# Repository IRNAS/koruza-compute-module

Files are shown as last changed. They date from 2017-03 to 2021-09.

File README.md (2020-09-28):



# Koruza compute module

Main hardware board for the Koruza unit, based on the Raspberry Pi Compute Module.

Currently under development, for all information see the [schematic PDF file](https://github.com/IRNAS/koruza-compute-module/blob/board_0.2/koruza-compute-module-board/koruza-compute-module-board.pdf).Produced board versions can be found in the [release section](https://github.com/IRNAS/koruza-compute-module/releases) of the repository.

**Latest release: [v0.3.1](https://github.com/IRNAS/koruza-compute-module/releases/tag/v0.3.1)**

All comments and suggestions can be added to the [Issues](https://github.com/IRNAS/koruza-compute-module/issues) section of the repo. For additional details see the [Issue](https://github.com/IRNAS/koruza-compute-module/issues) section or contact me at vojislav@irnas.eu

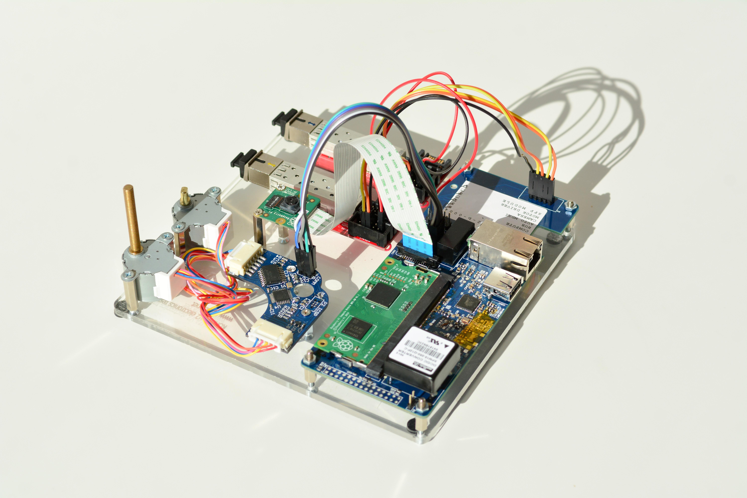
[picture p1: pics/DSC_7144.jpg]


---
## Uploding firmware

Connect board via USB and provide power via POE. Run RPiboot and wait for replay. Flash firmware image via Win32. 

## Licensing

KORUZA Pro Hardware with documentation, including Koruza compute module, is licensed under [CERN OHL v.1.2. license](https://www.ohwr.org/licenses/cern-ohl/license_versions/v1.2).

What this means is that you can use this hardware and documentation without paying a royalty and knowing that you'll be able to use your version forever. You are also free to make changes but if you share these changes then you have to do so on the same conditions that you enjoy.

KORUZA, KORUZA Pro and IRNAS are all names and marks of Institute IRNAS Rače. You may use these names and terms only to attribute the appropriate entity as required by the Open Licence referred to above. You may not use them in any other way and in particular you may not use them to imply endorsement or authorization of any hardware that you design, make or sell.

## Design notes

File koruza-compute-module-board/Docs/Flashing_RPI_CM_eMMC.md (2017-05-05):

# RPI CM Flash manual
The Compute Module has an on-board eMMC device connected to the primary SD card interface. This guide explains how to write data to the eMMC storage using a Compute Module IO board and Raspberry Pi 2B or 3B board.

1. Put the RPI CM in the RPI CM IO board socket. 
2. Set the J4 jumper (USB SLAVE BOOT ENABLE) on the RPI CM IO board to the EN.
3. Plug the micro USB power into the RPI 2B/3B. 
4. SSH to the RPI 2B/3B

*****
If the RPI 2B/3B is configured:

5. On RPI 2B/3B: `cd usbboot`
6. On RPI 2B/3B: `sudo ./rpiboot`
7. Now plug the host machine into the Compute Module IO board USB slave port (J15) and power the CMIO board on. The rpiboot tool will discover the Compute Module and send boot code to allow access to the eMMC. 
8. On RPI 2B/3B: `cd ..`
9. On RPI 2B/3B: `cd image`
10. On RPI 2B/3B: `sudo dd if=image_name.img of=/dev/sda bs=4MiB` Note the following command may take some time to complete, depending on the size of the image. verbose command option: `sudo dd if=image_name.img | pv -s 4G | sudo dd of=/dev/sda bs=4MiB`
11. Make sure J4 (USB SLAVE BOOT ENABLE) is set to the disabled position and/or nothing is plugged into the USB slave port. Power cycling the IO board should now result in the Compute Module booting from eMMC.

*****
If the RPI 2B/3B is NOT configured:

5. On RPI 2B/3B: `sudo apt-get update`
6. On RPI 2B/3B: `sudo apt-get install git pv`
7. Git may produce an error if the date is not set correctly. On a Raspberry Pi, enter the following to correct this: `sudo date MMDDhhmm` where MM is the month, DD is the date, and hh and mm are hours and minutes respectively.
8. On RPI 2B/3B: `git clone --depth=1 https://github.com/raspberrypi/usbboot`
9. On RPI 2B/3B: `cd usbboot`
10. On RPI 2B/3B: `sudo apt-get install libusb-1.0-0-dev`
11. On RPI 2B/3B now build and install the usbboot tool: `make`
12. NOW CONTNOUE FROM THE **If the RPI 2B/3B is configured: number 6.** 

If you have problems configuring the RPI CM please check the [link][link1].

[link1]: https://www.raspberrypi.org/documentation/hardware/computemodule/cm-emmc-flashing.md

# RPI CM installation post flash
1. Run `sudo raspi-config` and expand the filesystem
2. Run `sudo apt-ger update`
3. Run `sudo apt-get upgrade`
4. Copy koruza package on the unit
4. Run `sudo dpkg -i <koruza package>`
4. Run `sudo apt-get -f install`
4. Run `sudo dpkg -i <koruza package>`
4. Upgrade mcu firmware `sudo mcu-upgrade-firmware master`

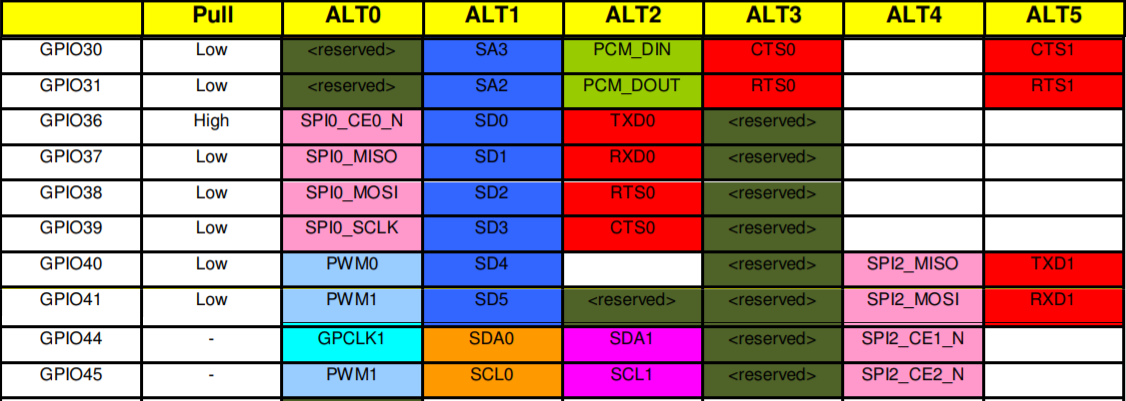
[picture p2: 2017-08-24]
pics/GPIO_ALT.png

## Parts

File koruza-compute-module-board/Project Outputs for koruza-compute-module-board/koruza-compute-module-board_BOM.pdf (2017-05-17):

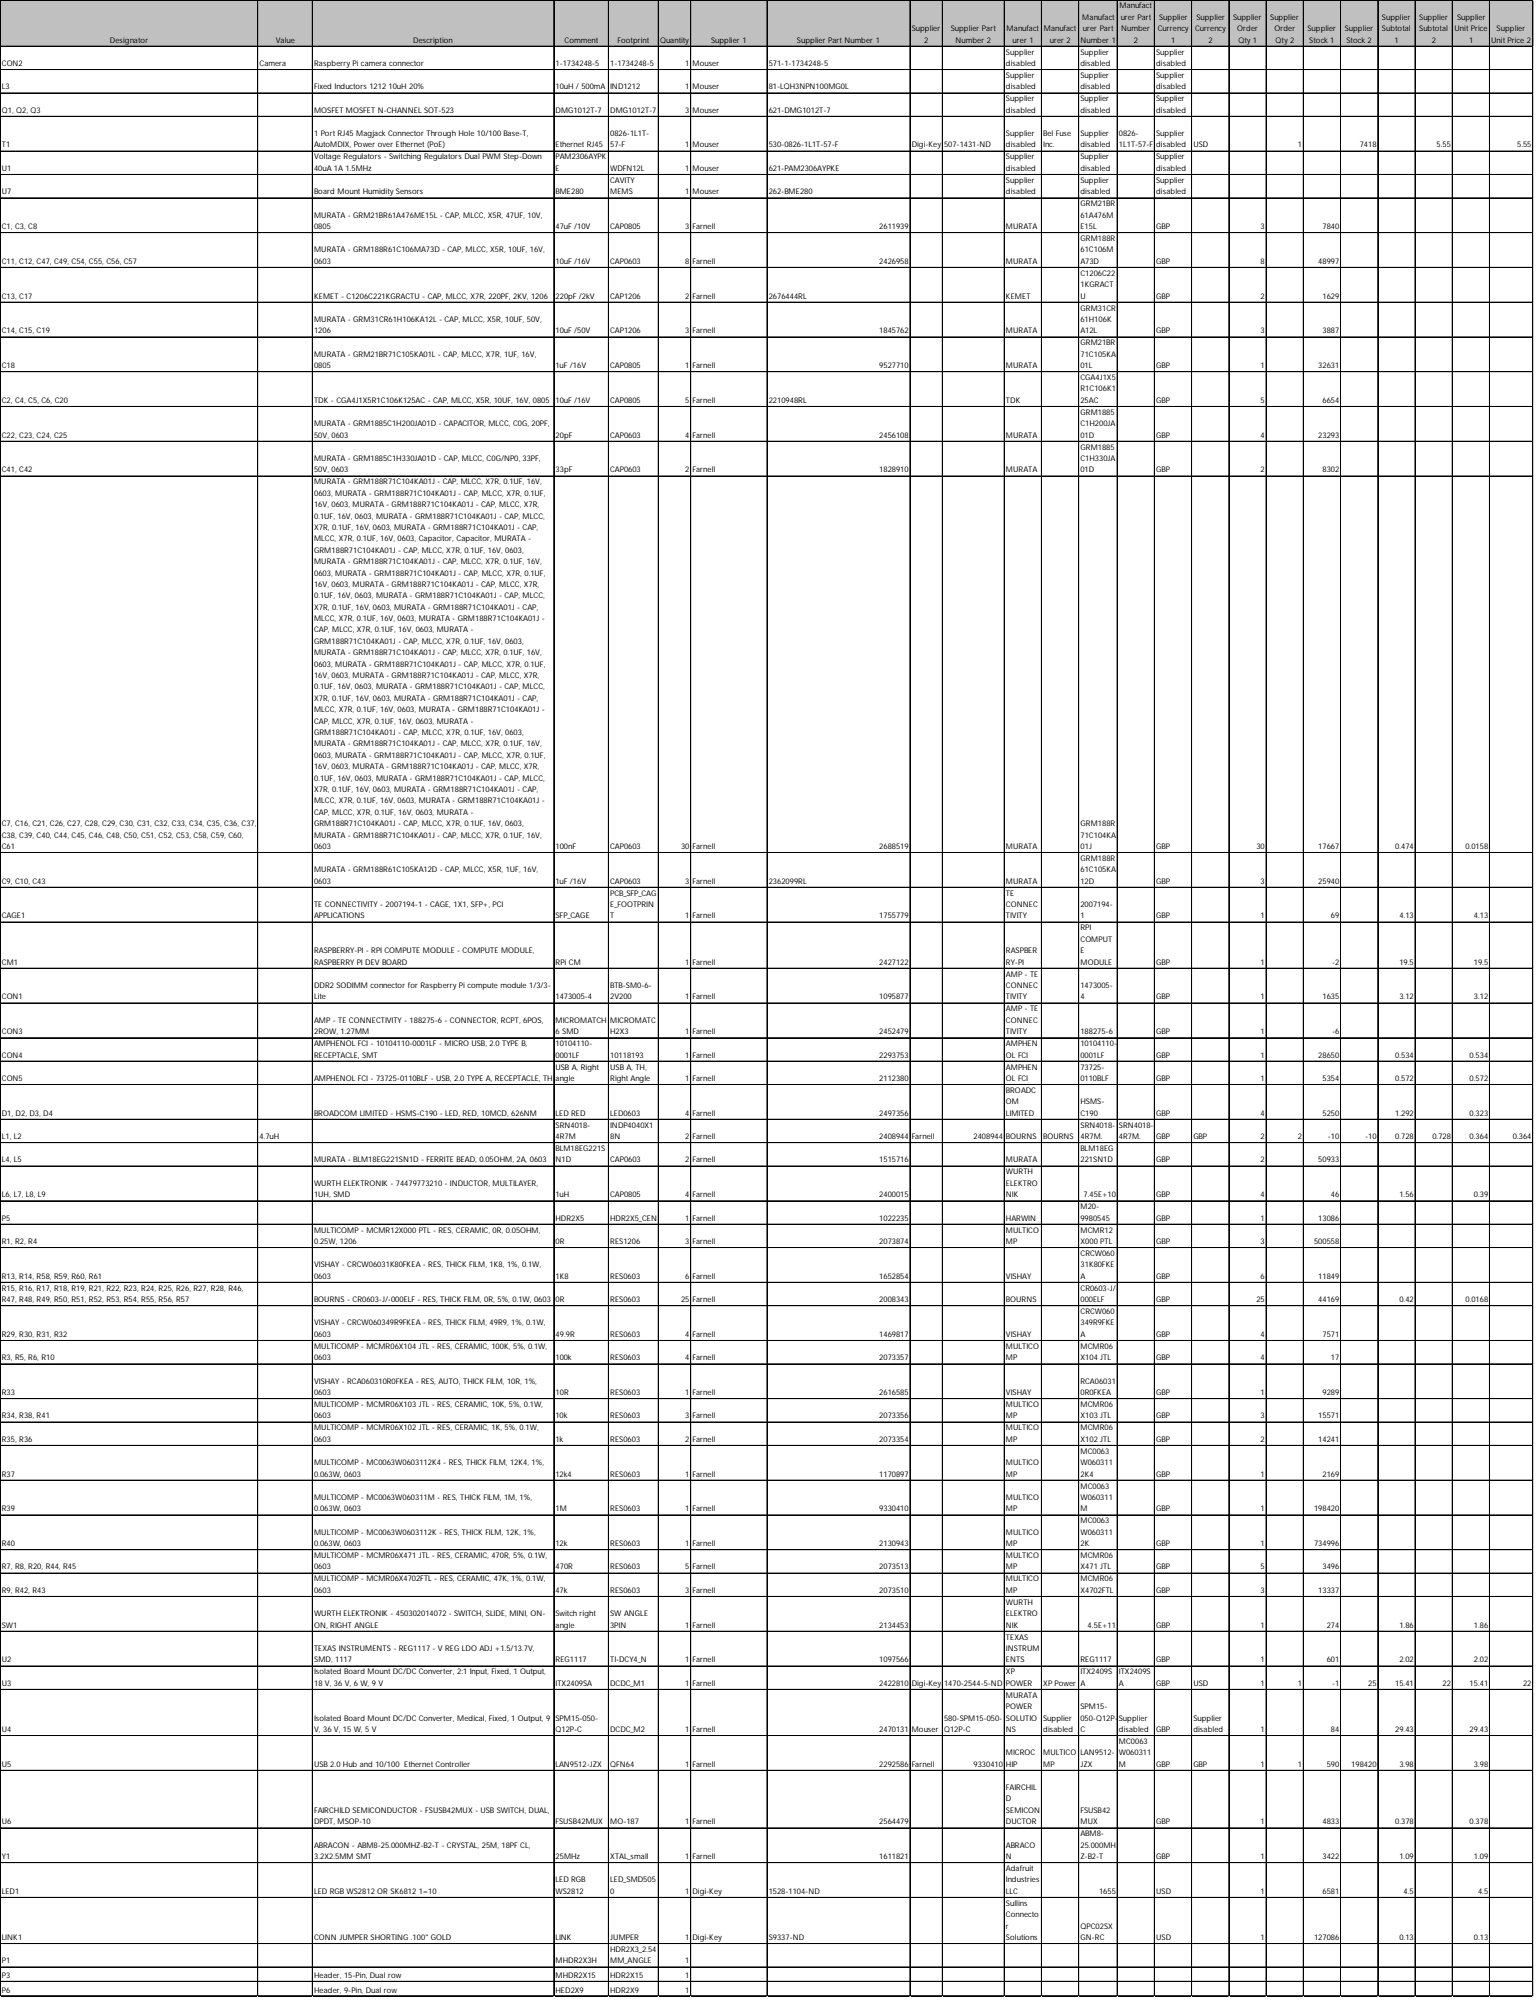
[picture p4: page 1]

Designator | Value | Description | Comment | Footprint | Quantity | Supplier 1 | Supplier Part Number 1 | Supplier 2 | Supplier Part Number 2 | Manufact urer 1 | Manufact urer 2 | Manufact urer Part Number 1 | Manufact urer Part Number 2 | Supplier Currency 1 | Supplier Currency 2 | Supplier Order Qty 1 | Supplier Order Qty 2 | Supplier Stock 1 | Supplier Stock 2 | Supplier Subtotal 1 | Supplier Subtotal 2 | Supplier Unit Price 1 | Supplier Unit Price 2

CON2 | Camera | Raspberry Pi camera connector | 1-1734248-5 | 1-1734248-5 | 1 | Mouser | 571-1-1734248-5 | | | Supplier disabled | | Supplier disabled | | Supplier disabled

L3 | | Fixed Inductors 1212 10uH 20% | 10uH / 500mA | IND1212 | 1 | Mouser | 81-LQH3NPN100MG0L | | | Supplier disabled | | Supplier disabled | | Supplier disabled

Q1, Q2, Q3 | | MOSFET MOSFET N-CHANNEL SOT-523 | DMG1012T-7 | DMG1012T-7 | 3 | Mouser | 621-DMG1012T-7 | | | Supplier disabled | | Supplier disabled | | Supplier disabled

T1 | | 1 Port RJ45 Magjack Connector Through Hole 10/100 Base-T, AutoMDIX, Power over Ethernet (PoE) | Ethernet RJ45 | 0826-1L1T-57-F | 1 | Mouser | 530-0826-1L1T-57-F | Digi-Key | 507-1431-ND | Supplier disabled | Bel Fuse Inc. | Supplier disabled | 0826-1L1T-57-F | Supplier disabled | USD | | 1 | | 7418 | | 5.55 | | 5.55

U1 | | Voltage Regulators - Switching Regulators Dual PWM Step-Down 40uA 1A 1.5MHz | PAM2306AYPK E | WDFN12L | 1 | Mouser | 621-PAM2306AYPKE | | | Supplier disabled | | Supplier disabled | | Supplier disabled

U7 | | Board Mount Humidity Sensors | BME280 | CAVITY MEMS | 1 | Mouser | 262-BME280 | | | Supplier disabled | | Supplier disabled | | Supplier disabled

C1, C3, C8 | | MURATA - GRM21BR61A476ME15L - CAP, MLCC, X5R, 47UF, 10V, 0805 | 47uF /10V | CAP0805 | 3 | Farnell | 2611939 | | | MURATA | | GRM21BR 61A476M E15L | | GBP | | 3 | | 7840

C11, C12, C47, C49, C54, C55, C56, C57 | | MURATA - GRM188R61C106MA73D - CAP, MLCC, X5R, 10UF, 16V, 0603 | 10uF /16V | CAP0603 | 8 | Farnell | 2426958 | | | MURATA | | GRM188R 61C106M A73D | | GBP | | 8 | | 48997

C13, C17 | | KEMET - C1206C221KGRACTU - CAP, MLCC, X7R, 220PF, 2KV, 1206 | 220pF /2kV | CAP1206 | 2 | Farnell | 2676444RL | | | KEMET | | C1206C22 1KGRACT U | | GBP | | 2 | | 1629

C14, C15, C19 | | MURATA - GRM31CR61H106KA12L - CAP, MLCC, X5R, 10UF, 50V, 1206 | 10uF /50V | CAP1206 | 3 | Farnell | 1845762 | | | MURATA | | GRM31CR 61H106K A12L | | GBP | | 3 | | 3887

C18 | | MURATA - GRM21BR71C105KA01L - CAP, MLCC, X7R, 1UF, 16V, 0805 | 1uF /16V | CAP0805 | 1 | Farnell | 9527710 | | | MURATA | | GRM21BR 71C105KA 01L | | GBP | | 1 | | 32631

C2, C4, C5, C6, C20 | | TDK - CGA4J1X5R1C106K125AC - CAP, MLCC, X5R, 10UF, 16V, 0805 | 10uF /16V | CAP0805 | 5 | Farnell | 2210948RL | | | TDK | | CGA4J1X5 R1C106K1 25AC | | GBP | | 5 | | 6654

C22, C23, C24, C25 | | MURATA - GRM1885C1H200JA01D - CAPACITOR, MLCC, C0G, 20PF, 50V, 0603 | 20pF | CAP0603 | 4 | Farnell | 2456108 | | | MURATA | | GRM1885 C1H200JA 01D | | GBP | | 4 | | 23293

C41, C42 | | MURATA - GRM1885C1H330JA01D - CAP, MLCC, C0G/NP0, 33PF, 50V, 0603 | 33pF | CAP0603 | 2 | Farnell | 1828910 | | | MURATA | | GRM1885 C1H330JA 01D | | GBP | | 2 | | 8302

MURATA - GRM188R71C104KA01J - CAP, MLCC, X7R, 0.1UF, 16V,
0603, MURATA - GRM188R71C104KA01J - CAP, MLCC, X7R, 0.1UF,
16V, 0603, MURATA - GRM188R71C104KA01J - CAP, MLCC, X7R,
0.1UF, 16V, 0603, MURATA - GRM188R71C104KA01J - CAP, MLCC,
X7R, 0.1UF, 16V, 0603, MURATA - GRM188R71C104KA01J - CAP,
MLCC, X7R, 0.1UF, 16V, 0603, Capacitor, Capacitor, MURATA -
GRM188R71C104KA01J - CAP, MLCC, X7R, 0.1UF, 16V, 0603,
MLCC, X7R, 0.1UF, 16V, 0603, MURATA - GRM188R71C104KA01J -
CAP, MLCC, X7R, 0.1UF, 16V, 0603, MURATA -

C9, C10, C43 | | MURATA - GRM188R61C105KA12D - CAP, MLCC, X5R, 1UF, 16V, 0603 | 1uF /16V | CAP0603 | 3 | Farnell | 2362099RL | | | MURATA | | GRM188R 61C105KA 12D | | GBP | | 3 | | 25940

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

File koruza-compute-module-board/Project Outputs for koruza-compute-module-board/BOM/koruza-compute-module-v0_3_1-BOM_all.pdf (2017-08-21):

Created by FEDEVEL | Motherboard, Processor and Microcontroller Board Design | http://www.fedevel.com
Component list | <Parameter ProjectTitle not found>
Source Data From: | koruza-compute-module-board.PrjPcb | Contact:
Project: | koruza-compute-module-board.PrjPcb
Variant: | None | Koruza
Report Date: | 05/13/2017 | 10:14:47 AM | www.koruza.net
Print Date: | 27-Jul-17 | 9:42:24 AM
# | Manufacturer Part Number 1 | Manufacturer 1 | Description | Footprint | Category | Quantity | Supplier 1 | Supplier Part Number 1

Supplier
Order Qty
1

Supplier
Stock 1

Supplier
Unit Price
1

Supplier
Subtotal 1

Supplier
Currency 1
1 | ITX2409SA | XP POWER | Isolated Board Mount DC/DC
2 3 | 450302014072 | WURTH ELEKTRONIK | WURTH ELEKTRONIK - | SW ANGLE 3PIN | | 1 | Farnell | 2134453 | 25 | 262 | 1.66 | 41.50 | GBP
| 74479773210 | WURTH ELEKTRONIK | WURTH ELEKTRONIK - | CAP0805 | | 4 | Farnell | 1869749 | 100 | 2187 | 0.29 | 29.00 | GBP
4 5 | CRCW06031K80FKEA | VISHAY | VISHAY - | RES0603 | | 6 | Farnell | 1652854 | 150 | 11759 | 0.01 | 1.44 | GBP
| CRCW060349R9FKEA | VISHAY | VISHAY - | RES0603 | | 4 | Farnell | 1469817 | 100 | 4204 | 0.01 | 0.94 | GBP
6 7 | RCA060310R0FKEA | VISHAY | VISHAY - RCA060310R0FKEA | RES0603 | | 1 | Farnell | 2616585 | 25 | 9289 | 0.08 | 2.01 | GBP
| REG1117 | TEXAS INSTRUMENTS | TEXAS INSTRUMENTS - | TI-DCY4_N | | 1 | Farnell | 1097566 | 25 | 550 | 1.53 | 38.25 | GBP
8 9 | 1-1734248-5 | TE Connectivity / AMP | Raspberry Pi camera connector | 1-1734248-5 | FFC & FPC Connectors | 1 | Mouser | 571-1-1734248-5 | 25 | 1375 | 1.29 | 32.25 | GBP
| 2007194-1 | TE CONNECTIVITY | TE CONNECTIVITY - 2007194- | PCB_SFP_CAGE_FOOTPRI | | 1 | Farnell | 1755779 | 25 | 68 | 3.68 | 92.00 | GBP
10 11 | CGA4J1X5R1C106K125AC | TDK | TDK - | CAP0805 | | 5 | Farnell | 2210948 | 125 | 6414 | 0.16 | 20.00 | GBP
| QPC02SXGN-RC | Sullins Connector Solutions | CONN JUMPER SHORTING | JUMPER | Connectors, Interconnects | 1 | Digi-Key | S9337-ND | 25 | 125440 | 0.05 | 1.25 | GBP
12 13 | RPI COMPUTE MODULE | RASPBERRY-PI | RASPBERRY-PI - RPI | | | 1 | Farnell | 2427122 | 25 | 25 | 19.50 | 487.50 | GBP
| SPM15-050-Q12P-C | MURATA POWER SOLUTIONS | Isolated Board Mount DC/DC | DCDC_M2 | | 1 | Farnell | 2470131 | 25 | 76 | 28.95 | 723.75 | GBP
14 15 | LQH3NPN100MG0L | Murata Electronics | Fixed Inductors 1212 10uH | IND1212 | Fixed Inductors | 1 | Mouser | 81-LQH3NPN100MG0L | 25 | 25 | 0.30 | 7.50 | GPB
| BLM18EG221SN1D | MURATA | MURATA - | CAP0603 | | 2 | Farnell | 1515716 | 50 | 50563 | 0.10 | 4.83 | GBP
16 17 | GRM1885C1H200JA01D | MURATA | MURATA - | CAP0603 | | 4 | Farnell | 2456108 | 100 | 23083 | 0.02 | 1.59 | GBP
| GRM1885C1H330JA01D | MURATA | MURATA - | CAP0603 | | 2 | Farnell | 1828910 | 50 | 8002 | 0.02 | 0.78 | GBP
18 19 | GRM188R61C105KA12D | MURATA | MURATA - | CAP0603 | | 3 | Farnell | 2362099 | 75 | 25820 | 0.01 | 0.95 | GBP
| GRM188R61C106MA73D | MURATA | MURATA - | CAP0603 | | 8 | Farnell | 2426958 | 200 | 37407 | 0.10 | 20.60 | GBP
20 21 | GRM188R71C104KA01J | MURATA | MURATA - | CAP0603 | | 30 | Farnell | 2688519 | 750 | 17667 | 0.01 | 5.85 | GBP
| GRM21BR61A476ME15L | MURATA | MURATA - | CAP0805 | | 3 | Farnell | 2611939 | 75 | 2584 | 0.30 | 22.28 | GBP
22 23 | GRM21BR71C105KA01L | MURATA | MURATA - | CAP0805 | | 1 | Farnell | 9527710 | 25 | 30805 | 0.04 | 1.01 | GBP
| GRM31CR61H106KA12L | MURATA | MURATA - | CAP1206 | | 3 | Farnell | 1845762 | 75 | 711 | 0.22 | 16.20 | GBP
24 25 | MC0063W0603112K | MULTICOMP | MULTICOMP - | RES0603 | | 1 | Farnell | 9330518 | 25 | 724996 | 0.00 | 0.02 | GBP
| MC0063W0603112K4 | MULTICOMP | MULTICOMP - | RES0603 | | 1 | Farnell | 1170897 | 25 | 1859 | 0.01 | 0.28 | GBP
26 27 | MC0063W060311M | MULTICOMP | MULTICOMP - | RES0603 | | 1 | Farnell | 9330410 | 25 | 176136 | 0.00 | 0.03 | GBP
| MCMR06X102 JTL | MULTICOMP | MULTICOMP - MCMR06X102 | RES0603 | | 2 | Farnell | 2073354 | 50 | 10741 | 0.01 | 0.32 | GBP
28 29 | MCMR06X103 JTL | MULTICOMP | MULTICOMP - MCMR06X103 | RES0603 | | 3 | Farnell | 2073356 | 75 | 15351 | 0.01 | 0.47 | GBP
| MCMR06X104 JTL | MULTICOMP | MULTICOMP - MCMR06X104 | RES0603 | | 4 | Farnell | 9233628 | 100 | 25843 | 0.00 | 0.45 | GBP
30 31 | MCMR06X4702FTL | MULTICOMP | MULTICOMP - | RES0603 | | 3 | Farnell | 2073510 | 75 | 13267 | 0.01 | 0.64 | GBP
| MCMR06X471 JTL | MULTICOMP | MULTICOMP - MCMR06X471 | RES0603 | | 5 | Farnell | 2073513 | 125 | 3496 | 0.01 | 0.95 | GBP
32 33 | MCMR12X000 PTL | MULTICOMP | MULTICOMP - MCMR12X000 | RES1206 | | 3 | Farnell | 2073874 | 75 | 497468 | 0.02 | 1.44 | GBP
| LAN9512-JZX | MICROCHIP | USB 2.0 Hub and 10/100 | QFN64 | | 1 | Farnell | 2292586 | 25 | 588 | 3.23 | 80.75 | GBP
34 35 | C1206C221KGRACTU | KEMET | KEMET - | CAP1206 | | 2 | Farnell | 2676444RL | 50 | 1629 | | 0.00 | GBP
| FSUSB42MUX | FAIRCHILD SEMICONDUCTOR | FAIRCHILD | MO-187 | | 1 | Farnell | 2564479 | 25 | 4826 | 0.30 | 7.43 | GBP
36 37 | DMG1012T-7 | Diodes Incorporated | MOSFET MOSFET N- | DMG1012T-7 | MOSFET | 3 | RS | 751-4064 | 100 | 2900 | 0.07 | 6.50 | GBP
| PAM2306AYPKE | Diodes Incorporated | Voltage Regulators - Switching | WDFN12L | Voltage Regulators - Switching Regulators | 1 | Mouser | 621-PAM2306AYPKE | 25 | 25 | 0.56 | 14.00 | GBP
38 39 | HSMS-C190 | BROADCOM LIMITED | BROADCOM LIMITED - HSMS- | LED0603 | | 4 | Farnell | 2497356 | 100 | 5223 | 0.10 | 9.74 | GBP
| VLS4012ET-4R7M | TDK | 4.7 µH, 1.9 A, 1.4 A, Shielded, | INDP4040X18N | Inductor | 2 | Farnell | 2345245 | 50 | 257 | 0..354 | 17.70 | GBP
40 41 | CR0603-J/-000ELF | BOURNS | BOURNS - CR0603-J/-000ELF - | RES0603 | | 25 | Farnell | 2008343 | 625 | 43719 | 0.01 | 7.00 | GBP
| BME280 | Bosch Sensortec | Board Mount Humidity Sensors | CAVITY MEMS | Board Mount Humidity Sensors | 1 | Mouser | 262-BME280 | 25 | 27083 | 5.06 | 106.88 | GPB
42 43 | 0826-1L1T-57-F | Bel Fuse | 1 Port RJ45 Magjack | 0826-1L1T-57-F | Modular Connectors / Ethernet Connectors | 1 | Mouser | 530-0826-1L1T-57-F | 25 | 1438 | 4.58 | 114.50 | GBP
| 10104110-0001LF | AMPHENOL FCI | AMPHENOL FCI - 10104110- | 10118193 | | 1 | Farnell | 2293753 | 25 | 26778 | 0.45 | 11.23 | GBP
44 45 | 73725-0110BLF | AMPHENOL FCI | AMPHENOL FCI - 73725- | USB A, TH, Right Angle | | 1 | Farnell | 2112380 | 25 | 5093 | 0.53 | 13.23 | GBP
| 188275-6 | AMP - TE CONNECTIVITY | AMP - TE CONNECTIVITY - | MICROMATCH2X3 | | 1 | Farnell | 2452479 | 25 | 851 | 0.45 | 11.13 | GBP
46 47 | 1473005-4 | AMP - TE CONNECTIVITY | DDR2 SODIMM connector for | BTB-SM0-6-2V200 | | 1 | Farnell | 1095877 | 25 | 1678 | 2.68 | 67.00 | GBP
| 1655 | Adafruit Industries LLC | LED RGB WS2812 OR | LED_SMD5050 | Optoelectronics | 1 | Digi-Key | 1528-1104-ND | 25 | 6446 | 0.09 | 2.23 | GBP
48 | ABM8-25.000MHZ-B2-T | ABRACON | ABRACON - ABM8- | XTAL_small | | 1 | Farnell | 1611821 | 25 | 3412 | 0.66 | 16.45 | GBP
| | | | | | 155 | | | 3900 | 2426.32
Approved | | | | Notes Price for 1pcs | | | | | | | | GBP
DCDC_M1 | 1 | Digi-Key | 1470-2544-5-ND | 25 | 25 | 15.38 | 384.50 | GBP
25 pcs: | Total | GBP
2426.317

97.05

07/27/2017 | 1/1

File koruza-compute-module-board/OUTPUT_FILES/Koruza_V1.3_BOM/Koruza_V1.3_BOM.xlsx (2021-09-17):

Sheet: Part List Report
 | Component list |  |  | Koruza
 | Source Data From: | koruza-compute-module-board.PrjPcb |  |  | Contact:
 | Project: | koruza-compute-module-board.PrjPcb
 | Variant: | None |  |  |  |  |  |  | IRNAS
 | Report Date: | 13. 04. 2021 | 08:57 |  |  |  |  |  | www.irnas.eu
 | Print Date: | 2021-05-26 | 7:35:33
# | Manufacturer Part Number | Manufacturer | Description | Footprint | Designator | Quantity | Supplier 1 | Supplier Part Number 1 | Supplier Order Qty 1 | Supplier Stock 1 | Supplier Unit Price 1 | Supplier Subtotal 1 | Supplier Currency 1
1 | RPI COMPUTE MODULE | RASPBERRY-PI | RASPBERRY-PI - RPI COMPUTE MODULE - COMPUTE MODULE, RASPBERRY PI DEV BOARD |  | CM1 | 1 | Farnell | 2427122 |  |  |  |  |  | 2427122,40,Koruza,Koruza
2 | 1-1734248-5 | TE Connectivity / AMP | Raspberry Pi camera connector | 1-1734248-5 | CON2 | 1 | Mouser | 571-1-1734248-5
3 | 0826-1L1T-57-F | Bel Fuse | 1 Port RJ45 Magjack Connector Through Hole 10/100 Base-T, AutoMDIX, Power over Ethernet (PoE) | 0826-1L1T-57-F | T1 | 1 | Mouser | 530-0826-1L1T-57-F
4
5 | 1776275-2 | TE CONNECTIVITY | TE CONNECTIVITY - 1776275-2 - TERMINAL BLOCK, WIRE TO BRD, 2POS, 18AWG | Block Terminal 3.5mm | CON4 | 1 | Farnell | 1098611 |  |  |  |  |  | 1098611,40,Koruza,Koruza
6 | BM04B-SRSS | JST | Pin Header, Top Entry, Wire-to-Board, 1 mm, 1 Rows, 4 Contacts, Surface Mount, SR Series | BM04B-SRSS | P5, P6 | 2 | Farnell | 1679129 |  |  |  |  |  | 1679129,80,Koruza,Koruza
7 | 1473005-4 | AMP - TE CONNECTIVITY | DDR2 SODIMM connector for Raspberry Pi compute module 1/3/3-Lite | BTB-SM0-6-2V200 | CON1 | 1 | Farnell | 1095877 |  |  |  |  |  | 1095877,40,Koruza,Koruza
8 | BLM18EG221SN1D | MURATA | MURATA - BLM18EG221SN1D - FERRITE BEAD, 0.05OHM, 2A, 0603 | CAP0603 | L4, L5 | 2 | Farnell | 1515716 |  |  |  |  |  | 1515716,80,Koruza,Koruza
9 | GRM188R61C105KA12D | MURATA | MURATA - GRM188R61C105KA12D - CAP, MLCC, X5R, 1UF, 16V, 0603 | CAP0603 | C9, C10, C43 | 3 | Farnell | 2362099 |  |  |  |  |  | 2362099,120,Koruza,Koruza
10 | GRM188R61C106MA73D | MURATA | MURATA - GRM188R61C106MA73D - CAP, MLCC, X5R, 10UF, 16V, 0603 | CAP0603 | C11, C12, C54, C55, C56, C57 | 6 | Farnell | 2426958 |  |  |  |  |  | 2426958,240,Koruza,Koruza
11 | GRM188R61C475KAAJD | MURATA | MURATA - GRM188R61C475KAAJD - CAP, MLCC, X5R, 4.7UF, 16V, 0603 | CAP0603 | C13, C14, C47 | 3 | Farnell | 2611924 |  |  |  |  |  | 2611924,120,Koruza,Koruza
12 | GRM188R61H105KAALD | MURATA | MURATA - GRM188R61H105KAALD - CAP, MLCC, X5R, 1UF, 50V, 0603 | CAP0603 | C50 | 1 | Farnell | 1845736 |  |  |  |  |  | 1845736,40,Koruza,Koruza
13 | GRM188R71C104KA01J | MURATA | MURATA - GRM188R71C104KA01J - CAP, MLCC, X7R, 0.1UF, 16V, 0603 | CAP0603 | C7, C16, C17, C26, C27, C28, C29, C30, C31, C32, C33, C34, C35, C36, C37, C38, C39, C40, C44, C45, C46, C48, C49, C52, C53, C58, C59, C60, C61, C64, C65, C68, C69, C72, C73 | 35 | Farnell | 2688519 |  |  |  |  |  | 2688519,1400,Koruza,Koruza
14 | GRM188R71C104KA01J | MURATA | MURATA - GRM188R71C104KA01J - CAP, MLCC, X7R, 0.1UF, 16V, 0603 | CAP0603 | C51 | 1 | Farnell | 2688519 |  |  |  |  |  | 2688519,40,Koruza,Koruza
15 | GRM1885C1H200JA01D | MURATA | MURATA - GRM1885C1H200JA01D - CAPACITOR, MLCC, C0G, 20PF, 50V, 0603 | CAP0603 | C22, C23, C24, C25 | 4 | Farnell | 2456108 |  |  |  |  |  | 2456108,160,Koruza,Koruza
16 | GRM1885C1H330JA01D | MURATA | MURATA - GRM1885C1H330JA01D - CAP, MLCC, C0G/NP0, 33PF, 50V, 0603 | CAP0603 | C41, C42 | 2 | Farnell | 1828910 |  |  |  |  |  | 1828910,80,Koruza,Koruza
17 | GRM21BR61A476ME15L | MURATA | MURATA - GRM21BR61A476ME15L - CAP, MLCC, X5R, 47UF, 10V, 0805 | CAP0805 | C62, C66, C70, C74 | 4 | Farnell | 2611939 |  |  |  |  |  | 2611939,160,Koruza,Koruza
18 | GRM21BR61A476ME15L | MURATA | MURATA - GRM21BR61A476ME15L - CAP, MLCC, X5R, 47UF, 10V, 0805 | CAP0805 | C1, C3, C8 | 3 | Farnell | 2611939 |  |  |  |  |  | 2611939,120,Koruza,Koruza
19 | GRM21BR71C105KA01L | MURATA | MURATA - GRM21BR71C105KA01L - CAP, MLCC, X7R, 1UF, 16V, 0805 | CAP0805 | C18 | 1 | Farnell | 9527710 |  |  |  |  |  | 9527710,40,Koruza,Koruza
20 | CGA4J1X5R1C106K125AC | TDK | TDK - CGA4J1X5R1C106K125AC - CAP, MLCC, X5R, 10UF, 16V, 0805 | CAP0805 | C2, C4, C5, C6, C20 | 5 | Farnell | 2210948 |  |  |  |  |  | 2210948,200,Koruza,Koruza
21 | MPZ1608D101B | TDK | TDK - MPZ1608D101B - FERRITE BEAD, 0.15OHM, 1A, 0603 | CAP0805 | FB1 | 1 | Farnell | 1669740 |  |  |  |  |  | 1669740,40,Koruza,Koruza
22 | KLZ2012AHR1R0WTD25 | WURTH ELEKTRONIK | WURTH ELEKTRONIK - 74479773210 - INDUCTOR, MULTILAYER, 1UH, SMD | CAP0805 | L6, L7, L8, L9 | 4 | Farnell | 3489650 |  |  |  |  |  | 3489650,160,Koruza,Koruza
23 | C1206C221KGRACTU | KEMET | KEMET - C1206C221KGRACTU - CAP, MLCC, X7R, 220PF, 2KV, 1206 | CAP1206 | C21 | 1 | Farnell | 2676444 |  |  |  |  |  | 2676444,40,Koruza,Koruza
24 | GRM31CR61H106KA12L | MURATA | MURATA - GRM31CR61H106KA12L - CAP, MLCC, X5R, 10UF, 50V, 1206 | CAP1206 | C15, C63, C67, C71 | 4 | Farnell | 1845762 |  |  |  |  |  | 1845762,160,Koruza,Koruza
25 | GRM31CR61H106KA12L | MURATA | MURATA - GRM31CR61H106KA12L - CAP, MLCC, X5R, 10UF, 50V, 1206 | CAP1206 | C19 | 1 | Farnell | 1845762 |  |  |  |  |  | 1845762,40,Koruza,Koruza
26 | SPM15-050-Q12P-C | MURATA POWER SOLUTIONS | Isolated Board Mount DC/DC Converter, Medical, Fixed, 1 Output, 9 V, 36 V, 15 W, 5 V | DCDC_M2 | U4 | 1 | Farnell | 2470131 |  |  |  |  |  | 2470131,40,Koruza,Koruza
27 | MRA4007T3G | ON SEMICONDUCTOR | ON SEMICONDUCTOR - MRA4007T3G - DIODE, STANDARD, 1A, 1KV, SMA | DIOM4326X24N_1 | D5, D6 | 2 | Farnell | 1459137 |  |  |  |  |  | 1459137,80,Koruza,Koruza
28 | DMG1012T-7 | Diodes Incorporated | MOSFET MOSFET N-CHANNEL SOT-523 | DMG1012T-7 | Q1, Q2, Q3, Q4, Q5 | 5 | Mouser | 621-DMG1012T-7
29
30 | 68001-402HLF | Amphenol FCI | Headers & Wire Housings 2P VERT HDR | Hdr1x2_2.54mm | CON8 | 1 | Mouser
31 | PCA9546ABS,118 | NXP | Translating Switch, Bidirectional, 4 Inputs, 2.3V to 5.5V Supply, 25mA Out, 0.3ns Delay, HVQFN-16 | HVQFN16 | U17 | 1 | Farnell | 2775989 |  |  |  |  |  | 2775989,40,Koruza,Koruza
32 | SRN4018-4R7M. | Bourns | INDUCTOR, SEMI-SHIELDED, 4.7uH, 1.9A, 20%, SMD | INDP4040X18N | L1, L2 | 2 | Farnell | 2408944 |  |  |  |  |  | 2408944,80,Koruza,Koruza
33
34 | QPC02SXGN-RC | Sullins Connector Solutions | CONN JUMPER SHORTING .100" GOLD | JUMPER | LINK1 | 1 | Digi-Key | S9337-ND
35 | HSMS-C190 | BROADCOM LIMITED | BROADCOM LIMITED - HSMS-C190 - LED, RED, 10MCD, 626NM | LED0603 | D1, D2, D3, D4 | 4 | Farnell | 2497356 |  |  |  |  |  | 2497356,160,Koruza,Koruza
36 | 1040310811 | Molex, LLC | CONN MICRO SD CARD PUSH-PULL R/A | MICRO SD CARD SOCKET | CON5 | 1 | Digi-Key | WM6357CT-ND
37 | 188275-6 | AMP - TE CONNECTIVITY | AMP - TE CONNECTIVITY - 188275-6 - CONNECTOR, RCPT, 6POS, 2ROW, 1.27MM | MICROMATCH2X3 | CON3 | 1 | Farnell | 2452479 |  |  |  |  |  | 2452479,40,Koruza,Koruza
38 | FSUSB42MUX | FAIRCHILD SEMICONDUCTOR | FAIRCHILD SEMICONDUCTOR - FSUSB42MUX - USB SWITCH, DUAL, DPDT, MSOP-10 | MO-187 | U6 | 1 | Farnell | 2564479
39 | 2007194-1 | TE CONNECTIVITY | TE CONNECTIVITY - 2007194-1 - CAGE, 1X1, SFP+, PCI APPLICATIONS | PCB_SFP_CAGE_FOOTPRINT | CAGE1 | 1 | Farnell | 1755779 |  |  |  |  |  | 1755779,40,Koruza,Koruza
40 | LAN9514-JZX | MICROCHIP | MICROCHIP - LAN9514-JZX - IC, USB2 - ENET CNTRL 4-PORT HUB, 64VQFN | QFN64 | U5 | 1 | Farnell | 2292587 |  |  |  |  |  | 2292587,40,Koruza,Koruza
41 | CR0603-J/-000ELF | BOURNS | BOURNS - CR0603-J/-000ELF - RES, THICK FILM, 0R, 5%, 0.1W, 0603 | RES0603 | R2, R11, R15, R63 | 4 | Farnell | 2008343 |  |  |  |  |  | 2008343,160,Koruza,Koruza
42 | CR0603-J/-000ELF | BOURNS | BOURNS - CR0603-J/-000ELF - RES, THICK FILM, 0R, 5%, 0.1W, 0603 | RES0603 | R16, R17, R18, R19, R22, R25, R26, R50, R51, R52, R53 | 11 | Farnell | 2008343 |  |  |  |  |  | 2008343,440,Koruza,Koruza
43 | MC0063W060311M | MULTICOMP | MULTICOMP - MC0063W060311M - RES, THICK FILM, 1M, 1%, 0.063W, 0603 | RES0603 | R46 | 1 | Farnell | 9330410 |  |  |  |  |  | 9330410,40,Koruza,Koruza
44 | MC0063W060311M | MULTICOMP | MULTICOMP - MC0063W060311M - RES, THICK FILM, 1M, 1%, 0.063W, 0603 | RES0603 | R39 | 1 | Farnell | 9330410 |  |  |  |  |  | 9330410,40,Koruza,Koruza
45 | MC0063W0603112K4 | MULTICOMP | MULTICOMP - MC0063W0603112K4 - RES, THICK FILM, 12K4, 1%, 0.063W, 0603 | RES0603 | R37 | 1 | Farnell | 1170897 |  |  |  |  |  | 1170897,40,Koruza,Koruza
46 | MC0063W0603112K | MULTICOMP | MULTICOMP - MC0063W0603112K - RES, THICK FILM, 12K, 1%, 0.063W, 0603 | RES0603 | R40 | 1 | Farnell | 2130943 |  |  |  |  |  | 2130943,40,Koruza,Koruza
47 | MCMR06X102 JTL | MULTICOMP | MULTICOMP - MCMR06X102 JTL - RES, CERAMIC, 1K, 5%, 0.1W, 0603 | RES0603 | R35, R36 | 2 | Farnell | 2073354 |  |  |  |  |  | 2073354,80,Koruza,Koruza
48 | MCMR06X103 JTL | MULTICOMP | MULTICOMP - MCMR06X103 JTL - RES, CERAMIC, 10K, 5%, 0.1W, 0603 | RES0603 | R47, R48, R49, R54, R55, R56, R57, R66, R67 | 9 | Farnell | 2073356 |  |  |  |  |  | 2073356,360,Koruza,Koruza
49 | MCMR06X103 JTL | MULTICOMP | MULTICOMP - MCMR06X103 JTL - RES, CERAMIC, 10K, 5%, 0.1W, 0603 | RES0603 | R34, R38, R41, R72, R73, R74, R75 | 7 | Farnell | 2073356 |  |  |  |  |  | 2073356,280,Koruza,Koruza
50 | MCMR06X104 JTL | MULTICOMP | MULTICOMP - MCMR06X104 JTL - RES, CERAMIC, 100K, 5%, 0.1W, 0603 | RES0603 | R3, R5, R6, R10, R64 | 5 | Farnell | 2073357 |  |  |  |  |  | 2073357,200,Koruza,Koruza
51 | MCMR06X471 JTL | MULTICOMP | MULTICOMP - MCMR06X471 JTL - RES, CERAMIC, 470R, 5%, 0.1W, 0603 | RES0603 | R65 | 1 | Farnell | 2073513 |  |  |  |  |  | 2073513,40,Koruza,Koruza
52 | MCMR06X471 JTL | MULTICOMP | MULTICOMP - MCMR06X471 JTL - RES, CERAMIC, 470R, 5%, 0.1W, 0603 | RES0603 | R7, R8, R20, R44, R45 | 5 | Farnell | 2073513 |  |  |  |  |  | 2073513,200,Koruza,Koruza
53 | MCMR06X4701FTL | MULTICOMP | MULTICOMP - MCMR06X4701FTL - RES, CERAMIC, 4K7, 1%, 0.1W, 0603 | RES0603 | R23, R24, R68, R69, R70, R71 | 6 | Farnell | 2073509 |  |  |  |  |  | 2073509,240,Koruza,Koruza
54 | MCMR06X4702FTL | MULTICOMP | MULTICOMP - MCMR06X4702FTL - RES, CERAMIC, 47K, 1%, 0.1W, 0603 | RES0603 | R1, R4, R12, R62 | 4 | Farnell | 2073510 |  |  |  |  |  | 2073510,160,Koruza,Koruza
55 | MCMR06X4702FTL | MULTICOMP | MULTICOMP - MCMR06X4702FTL - RES, CERAMIC, 47K, 1%, 0.1W, 0603 | RES0603 | R9, R42, R43 | 3 | Farnell | 2073510 |  |  |  |  |  | 2073510,120,Koruza,Koruza
56 | CRCW06031K80FKEA | VISHAY | VISHAY - CRCW06031K80FKEA - RES, THICK FILM, 1K8, 1%, 0.1W, 0603 | RES0603 | R13, R14, R58, R59, R60, R61 | 6 | Farnell | 1652854 |  |  |  |  |  | 1652854,240,Koruza,Koruza
57 | CRCW060349R9FKEA | VISHAY | VISHAY - CRCW060349R9FKEA - RES, THICK FILM, 49R9, 1%, 0.1W, 0603 | RES0603 | R29, R30, R31, R32 | 4 | Farnell | 1469817 |  |  |  |  |  | 1469817,160,Koruza,Koruza
58 | RCA060310R0FKEA | VISHAY | VISHAY - RCA060310R0FKEA - RES, AUTO, THICK FILM, 10R, 1%, 0603 | RES0603 | R33 | 1 | Farnell | 2616585 |  |  |  |  |  | 2616585,40,Koruza,Koruza
59 | MCMR12X000 PTL | MULTICOMP | MULTICOMP - MCMR12X000 PTL - RES, CERAMIC, 0R, 0.05OHM, 0.25W, 1206 | RES1206 | R27, R28 | 2 | Farnell | 2073874 |  |  |  |  |  | 2073874,80,Koruza,Koruza
60 | TL2BR10FTE | TE CONNECTIVITY | TE CONNECTIVITY - TL2BR10FTE - RESISTOR, METAL , R10, 0.25W, 1%, 1206 | RES1206 | R21 | 1 | Farnell | 2330389 |  |  |  |  |  | 2330389,40,Koruza,Koruza
61 | AP2553FDC-7 | Diodes Incorporated | IC PD SW CURR LIMIT 6DFN | SON65P200X63_HS-7N | U8, U10, U12, U14 | 4 | Digi-Key | AP2553FDC-7DICT-ND
62 | PC817X2NIP0F | SHARP | SHARP - PC817X2NIP0F - OPTOCOUPLER, PHOTOTRANSISTOR, 5KV | SOP127P600-8N | U16 | 1 | Farnell | 2420054 |  |  |  |  |  | 2420054,40,Koruza,Koruza
63 | INA219AIDCNR | TEXAS INSTRUMENTS | TEXAS INSTRUMENTS - INA219AIDCNR - CURRENT / POWER MONITOR, 120DB, 8SOT23 | SOT23-8PIN | U7 | 1 | Farnell | 2295989 |  |  |  |  |  | 2295989,40,Koruza,Koruza
64 | USBLC6-2SC6 | STMICROELECTRONICS | STMICROELECTRONICS - USBLC6-2SC6 - ESD PROTECTION, 3.5PF, 17V, SOT23 | SOT23127P600-8N | U9, U11, U13, U15 | 4 | Farnell | 1269406 |  |  |  |  |  | 1269406,160,Koruza,Koruza
65 | SRV05-4ATCT | Semtech Corporation | TVS DIODE 5VWM 17.5VC SOT23-6 | SOT23127P600-8N | U3 | 1 | Digi-Key | SRV05-4ATCTCT-ND
66 | CPH3455-TL-W | ON SEMICONDUCTOR | ON SEMICONDUCTOR - CPH3455-TL-W - MOSFET, N-CH, 35V, 3A, CPH-3 | SOT23127P600-8N - 1 | Q6 | 1 | Farnell | 2508370 |  |  |  |  |  | 2508370,40,Koruza,Koruza
67 | REG1117 | TEXAS INSTRUMENTS | TEXAS INSTRUMENTS - REG1117 - V REG LDO ADJ +1.5/13.7V, SMD, 1117 | TI-DCY4_N | U2 | 1 | Farnell | 1097566 |  |  |  |  |  | 1097566,40,Koruza,Koruza
68 | PAM2306AYPKE | Diodes Incorporated | Voltage Regulators - Switching Regulators Dual PWM Step-Down 40uA 1A 1.5MHz | WDFN12L | U1 | 1 | Mouser | 621-PAM2306AYPKE
69 | ABM8-25.000MHZ-B2-T | ABRACON | ABRACON - ABM8-25.000MHZ-B2-T - CRYSTAL, 25M, 18PF CL, 3.2X2.5MM SMT | XTAL_small | Y1 | 1 | Farnell | 1611821 |  |  |  |  |  | 1611821,40,Koruza,Koruza
 |  |  |  |  |  | 200 |  |  | 0 |  |  | 0
Approved |  |  |  | Notes
 |  |  |  | pcs: |  | 20 |  | Total |  | 0 |  | <none>
 |  |  |  |  |  |  |  | Price for 1pcs |  | 0.00 |  | <none>

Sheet: Project Information
Project Full Path | D:\Synology Drive\IRNAS-Projects\KORUZA\KORUZA-Electronics\koruza-compute-module-board.PrjPcb
Project Filename | koruza-compute-module-board.PrjPcb
Variant Name | None
Data-Source Filename | koruza-compute-module-board.PrjPcb
Data-Source Full Path | D:\Synology Drive\IRNAS-Projects\KORUZA\KORUZA-Electronics\koruza-compute-module-board.PrjPcb
Title | BOM for Project [koruza-compute-module-board.PrjPcb] (No PCB Document Selected)
Total Quantity | 204
Report Time | 08:57
Report Date | 13. 04. 2021
Report Date & Tine | 13. 04. 2021 08:57
Output Name | BOM
Output Type | BOM_PartType
Output Generator Name | BOM
Output Generator Description | Bill of Materials

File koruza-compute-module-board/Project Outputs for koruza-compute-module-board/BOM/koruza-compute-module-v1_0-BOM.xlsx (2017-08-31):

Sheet: Part List Report
 | Component list |  |  | Koruza-CM
 | Source Data From: | koruza-compute-module-board.PrjPcb |  |  | Contact:
 | Project: | koruza-compute-module-board.PrjPcb
 | Variant: | None |  |  |  |  |  |  | Koruza
 | Report Date: | 08/31/2017 | 8:45:27 AM |  |  |  |  |  | www.koruza.net
 | Print Date: | 2017-08-31 | 8:54:46
# | Manufacturer Part Number 1 | Manufacturer 1 | Description | Footprint | Category | Quantity | Supplier 1 | Supplier Part Number 1 | Supplier Order Qty 1 | Supplier Stock 1 | Supplier Unit Price 1 | Supplier Subtotal 1 | Supplier Currency 1
1 | 74479773210 | WURTH ELEKTRONIK | WURTH ELEKTRONIK - 74479773210 - INDUCTOR, MULTILAYER, 1UH, SMD | CAP0805 |  | 4 | Farnell |  | 20 | 41 | 0.39 | 7.80 | GBP
2 | CRCW06031K80FKEA | VISHAY | VISHAY - CRCW06031K80FKEA - RES, THICK FILM, 1K8, 1%, 0.1W, 0603 | RES0603 |  | 6 | Farnell | 1652854 | 30 | -2 | 0.04 | 1.26 | GBP
3 | CRCW060349R9FKEA | VISHAY | VISHAY - CRCW060349R9FKEA - RES, THICK FILM, 49R9, 1%, 0.1W, 0603 | RES0603 |  | 4 | Farnell | 1469817 | 20 | -2 | 0.03 | 0.67 | GBP
4 | RCA060310R0FKEA | VISHAY | VISHAY - RCA060310R0FKEA - RES, AUTO, THICK FILM, 10R, 1%, 0603 | RES0603 |  | 1 | Farnell | 2616585 | 5 | 7045 |  |  | GBP
5 | INA219AIDCNR | TEXAS INSTRUMENTS | TEXAS INSTRUMENTS - INA219AIDCNR - CURRENT / POWER MONITOR, 120DB, 8SOT23 | SOT23-8PIN |  | 1 | Farnell | 2295989 | 5 | 5708 | 1.90 | 9.50 | GBP
6 | REG1117 | TEXAS INSTRUMENTS | TEXAS INSTRUMENTS - REG1117 - V REG LDO ADJ +1.5/13.7V, SMD, 1117 | TI-DCY4_N |  | 1 | Farnell | 1097566 | 5 | 274 | 2.92 | 14.60 | GBP
7 | 1776275-2 | TE CONNECTIVITY | TE CONNECTIVITY - 1776275-2 - TERMINAL BLOCK, WIRE TO BRD, 2POS, 18AWG | Block Terminal 3.5mm |  | 1 | Farnell | 1098611 | 5 | 22419 | 0.20 | 0.99 | GBP
8 | 2007194-1 | TE CONNECTIVITY | TE CONNECTIVITY - 2007194-1 - CAGE, 1X1, SFP+, PCI APPLICATIONS | PCB_SFP_CAGE_FOOTPRINT | Optoelectronics | 1 | Farnell | 1755779 | 5 | 1124 | 3.43 | 17.15 | GBP
9 | TL2BR10FTE | TE CONNECTIVITY | TE CONNECTIVITY - TL2BR10FTE - RESISTOR, METAL , R10, 0.25W, 1%, 1206 | RES1206 |  | 1 | Farnell | 2330389 | 5 | 1781 |  |  | GBP
10 | CGA4J1X5R1C106K125AC | TDK | TDK - CGA4J1X5R1C106K125AC - CAP, MLCC, X5R, 10UF, 16V, 0805 | CAP0805 |  | 5 | Farnell | 2210948RL | 25 | 5934 | 0.31 | 7.72 | GBP
11 | MPZ1608D101B | TDK | TDK - MPZ1608D101B - FERRITE BEAD, 0.15OHM, 1A, 0603 | CAP0805 |  | 1 | Farnell | 1669740 | 5 | 21874 |  |  | GBP
12 | Supplier disabled | Supplier disabled | 1 Port RJ45 Magjack Connector Through Hole 10/100 Base-T, AutoMDIX, Power over Ethernet (PoE) | 0826-1L1T-57-F | Modular Connectors / Ethernet Connectors | 1 | Mouser | 530-0826-1L1T-57-F |  |  |  |  | Supplier disabled
13 | Supplier disabled | Supplier disabled | MOSFET MOSFET N-CHANNEL SOT-523 | DMG1012T-7 | MOSFET | 5 | Mouser | 621-DMG1012T-7 |  |  |  |  | Supplier disabled
14 | Supplier disabled | Supplier disabled | Raspberry Pi camera connector | 1-1734248-5 | FFC & FPC Connectors | 1 | Mouser | 571-1-1734248-5 |  |  |  |  | Supplier disabled
15 | Supplier disabled | Supplier disabled | Voltage Regulators - Switching Regulators Dual PWM Step-Down 40uA 1A 1.5MHz | WDFN12L | Voltage Regulators - Switching Regulators | 1 | Mouser | 621-PAM2306AYPKE |  |  |  |  | Supplier disabled
16 | USBLC6-2SC6 | STMICROELECTRONICS | STMICROELECTRONICS - USBLC6-2SC6 - ESD PROTECTION, 3.5PF, 17V, SOT23 | SOT23127P600-8N |  | 4 | Farnell | 1269406 | 20 | 22324 | 0.21 | 4.30 | GBP
17 | PC817X2NIP0F | SHARP | SHARP - PC817X2NIP0F - OPTOCOUPLER, PHOTOTRANSISTOR, 5KV | SOP127P600-8N |  | 1 | Farnell | 2420054 | 5 | 5697 | 0.37 | 1.83 | GBP
18 | SRV05-4ATCT | Semtech Corporation | TVS DIODE 5VWM 17.5VC SOT23-6 | SOT23127P600-8N | Circuit Protection | 1 | Digi-Key | SRV05-4ATCTCT-ND | 5 | 15256 | 1.19 | 5.95 | USD
19 | FSUSB42MUX | ON SEMICONDUCTOR/FAIRCHILD | FAIRCHILD SEMICONDUCTOR - FSUSB42MUX - USB SWITCH, DUAL, DPDT, MSOP-10 | MO-187 |  | 1 | Farnell | 2564479 | 5 | 4690 | 0.55 | 2.73 | GBP
20 | CPH3455-TL-W | ON SEMICONDUCTOR | ON SEMICONDUCTOR - CPH3455-TL-W - MOSFET, N-CH, 35V, 3A, CPH-3 | SOT23127P600-8N - 1 |  | 1 | Farnell | 2508370 | 5 | 2861 | 0.46 | 2.32 | GBP
21 | MRA4007T3G | ON SEMICONDUCTOR | ON SEMICONDUCTOR - MRA4007T3G - DIODE, STANDARD, 1A, 1KV, SMA | DIOM4326X24N_1 |  | 2 | Farnell | 1459137 | 10 | 80779 | 0.18 | 1.81 | GBP
22 | SPM15-050-Q12P-C | MURATA POWER SOLUTIONS | Isolated Board Mount DC/DC Converter, Medical, Fixed, 1 Output, 9 V, 36 V, 15 W, 5 V | DCDC_M2 |  | 1 | Farnell | 2470131 | 5 | 1 | 34.90 | 174.50 | GBP | imamo ta dva komada kod mene
23 | BLM18EG221SN1D | MURATA | MURATA - BLM18EG221SN1D - FERRITE BEAD, 0.05OHM, 2A, 0603 | CAP0603 |  | 2 | Farnell | 1515716 | 10 | 42371 | 0.11 | 1.13 | GBP
24 | GRM1885C1H200JA01D | MURATA | MURATA - GRM1885C1H200JA01D - CAPACITOR, MLCC, C0G, 20PF, 50V, 0603 | CAP0603 |  | 4 | Farnell | 2456108 | 20 | 13962 | 0.03 | 0.52 | GBP
25 | GRM1885C1H330JA01D | MURATA | MURATA - GRM1885C1H330JA01D - CAP, MLCC, C0G/NP0, 33PF, 50V, 0603 | CAP0603 |  | 2 | Farnell | 1828910 | 10 | 13046 | 0.02 | 0.16 | GBP
26 | GRM188R61C105KA12D | MURATA | MURATA - GRM188R61C105KA12D - CAP, MLCC, X5R, 1UF, 16V, 0603 | CAP0603 |  | 3 | Farnell | 2362099RL | 15 | 21570 | 0.02 | 0.33 | GBP
27 | GRM188R61C106MA73D | MURATA | MURATA - GRM188R61C106MA73D - CAP, MLCC, X5R, 10UF, 16V, 0603 | CAP0603 |  | 6 | Farnell | 2426958 | 30 | 32477 | 0.28 | 8.34 | GBP
28 | GRM188R61C475KAAJD | MURATA | MURATA - GRM188R61C475KAAJD - CAP, MLCC, X5R, 4.7UF, 16V, 0603 | CAP0603 |  | 3 | Farnell | 2611924 | 15 | 3758 | 0.16 | 2.40 | GBP
29 | GRM188R71C104KA01J | MURATA | MURATA - GRM188R71C104KA01J - CAP, MLCC, X7R, 0.1UF, 16V, 0603 | CAP0603 |  | 35 | Farnell | 2688519 | 175 | 9083 | 0.01 | 2.31 | GBP
30 | GRM21BR61A476ME15L | MURATA | MURATA - GRM21BR61A476ME15L - CAP, MLCC, X5R, 47UF, 10V, 0805 | CAP0805 |  | 3 | Farnell | 2611939 | 15 | 9 | 0.49 | 7.37 | GBP
31 | GRM21BR61A476ME15L | MURATA | MURATA - GRM21BR61A476ME15L - CAP, MLCC, X5R, 47UF, 10V, 0805 | CAP0805 |  | 4 | Farnell | 2611939 | 20 | 9 | 0.49 | 9.82 | GBP
32 | GRM21BR71C105KA01L | MURATA | MURATA - GRM21BR71C105KA01L - CAP, MLCC, X7R, 1UF, 16V, 0805 | CAP0805 |  | 1 | Farnell | 9527710 | 5 | 72743 | 0.06 | 0.31 | GBP
33 | GRM31CR61H106KA12L | MURATA | MURATA - GRM31CR61H106KA12L - CAP, MLCC, X5R, 10UF, 50V, 1206 | CAP1206 |  | 1 | Farnell | 1845762 | 5 | 53539 | 0.42 | 2.10 | GBP
34 | GRM31CR61H106KA12L | MURATA | MURATA - GRM31CR61H106KA12L - CAP, MLCC, X5R, 10UF, 50V, 1206 | CAP1206 |  | 4 | Farnell | 1845762 | 20 | 53539 | 0.42 | 8.38 | GBP
35 | MC0063W0603112K | MULTICOMP | MULTICOMP - MC0063W0603112K - RES, THICK FILM, 12K, 1%, 0.063W, 0603 | RES0603 |  | 1 | Farnell | 2130943 | 5 | 559496 |  |  | GBP
36 | MC0063W0603112K4 | MULTICOMP | MULTICOMP - MC0063W0603112K4 - RES, THICK FILM, 12K4, 1%, 0.063W, 0603 | RES0603 |  | 1 | Farnell | 1170897 | 5 | 688 |  |  | GBP
37 | MC0063W060311M | MULTICOMP | MULTICOMP - MC0063W060311M - RES, THICK FILM, 1M, 1%, 0.063W, 0603 | RES0603 |  | 1 | Farnell | 9330410 | 5 | 29546 |  |  | GBP
38 | MC0063W060311M | MULTICOMP | MULTICOMP - MC0063W060311M - RES, THICK FILM, 1M, 1%, 0.063W, 0603 | RES0603 |  | 1 | Farnell | 9330410 | 5 | 29546 |  |  | GBP
39 | MCMR06X102 JTL | MULTICOMP | MULTICOMP - MCMR06X102 JTL - RES, CERAMIC, 1K, 5%, 0.1W, 0603 | RES0603 |  | 2 | Farnell | 2073354 | 10 | 5961 | 0.01 | 0.07 | GBP
40 | MCMR06X103 JTL | MULTICOMP | MULTICOMP - MCMR06X103 JTL - RES, CERAMIC, 10K, 5%, 0.1W, 0603 | RES0603 |  | 3 | Farnell | 2073356 | 15 | 16381 | 0.01 | 0.11 | GBP
41 | MCMR06X103 JTL | MULTICOMP | MULTICOMP - MCMR06X103 JTL - RES, CERAMIC, 10K, 5%, 0.1W, 0603 | RES0603 |  | 9 | Farnell | 2073356 | 45 | 16381 | 0.01 | 0.33 | GBP
42 | MCMR06X104 JTL | MULTICOMP | MULTICOMP - MCMR06X104 JTL - RES, CERAMIC, 100K, 5%, 0.1W, 0603 | RES0603 |  | 5 | Farnell | 2073357 | 25 | 3387 | 0.01 | 0.16 | GBP
43 | MCMR06X4702FTL | MULTICOMP | MULTICOMP - MCMR06X4702FTL - RES, CERAMIC, 47K, 1%, 0.1W, 0603 | RES0603 |  | 3 | Farnell | 2073510 | 15 | 14979 | 0.01 | 0.15 | GBP
44 | MCMR06X4702FTL | MULTICOMP | MULTICOMP - MCMR06X4702FTL - RES, CERAMIC, 47K, 1%, 0.1W, 0603 | RES0603 |  | 4 | Farnell | 2073510 | 20 | 14979 | 0.01 | 0.20 | GBP
45 | MCMR06X471 JTL | MULTICOMP | MULTICOMP - MCMR06X471 JTL - RES, CERAMIC, 470R, 5%, 0.1W, 0603 | RES0603 |  | 1 | Farnell | 2073513 | 5 | 2976 |  |  | GBP
46 | MCMR06X471 JTL | MULTICOMP | MULTICOMP - MCMR06X471 JTL - RES, CERAMIC, 470R, 5%, 0.1W, 0603 | RES0603 |  | 5 | Farnell | 2073513 | 25 | 2976 | 0.01 | 0.23 | GBP
47 | MCMR12X000 PTL | MULTICOMP | MULTICOMP - MCMR12X000 PTL - RES, CERAMIC, 0R, 0.05OHM, 0.25W, 1206 | RES1206 |  | 2 | Farnell | 2073874 | 10 | 434877 | 0.01 | 0.14 | GBP
48 | 1040310811 | Molex, LLC | CONN MICRO SD CARD PUSH-PULL R/A | MICRO SD CARD SOCKET | Connectors, Interconnects | 1 | Digi-Key | WM6357CT-ND | 5 | 22256 | 1.92 | 9.60 | USD
49 | LAN9514-JZX | MICROCHIP | MICROCHIP - LAN9514-JZX - IC, USB2 - ENET CNTRL 4-PORT HUB, 64VQFN | QFN64 |  | 1 | Farnell | 2292587 | 5 | 941 | 5.09 | 25.45 | GBP
50 | C1206C221KGRACTU | KEMET | KEMET - C1206C221KGRACTU - CAP, MLCC, X7R, 220PF, 2KV, 1206 | CAP1206 |  | 1 | Farnell | 2676444 | 5 | 2575 | 0.21 | 1.05 | GBP
51 | AP2553FDC-7 | Diodes Incorporated | IC PD SW CURR LIMIT 6DFN | SON65P200X63_HS-7N | Integrated Circuits (ICs) | 4 | Digi-Key | AP2553FDC-7DICT-ND | 20 | 1636 | 0.42 | 8.50 | USD
52 | CR0603-J/-000ELF | BOURNS | BOURNS - CR0603-J/-000ELF - RES, THICK FILM, 0R, 5%, 0.1W, 0603 | RES0603 |  | 11 | Farnell | 2008343 | 55 | 24261 | 0.02 | 0.90 | GBP
53 | CR0603-J/-000ELF | BOURNS | BOURNS - CR0603-J/-000ELF - RES, THICK FILM, 0R, 5%, 0.1W, 0603 | RES0603 |  | 4 | Farnell | 2008343 | 20 | 24261 | 0.02 | 0.33 | GBP
54 | 188275-6 | AMP - TE CONNECTIVITY | AMP - TE CONNECTIVITY - 188275-6 - CONNECTOR, RCPT, 6POS, 2ROW, 1.27MM | MICROMATCH2X3 |  | 1 | Farnell | 2452479 | 5 | 79 |  |  | GBP
55 | 1473005-4 | AMP - TE CONNECTIVITY | DDR2 SODIMM connector for Raspberry Pi compute module 1/3/3-Lite | BTB-SM0-6-2V200 |  | 1 | Farnell | 1095877 | 5 | 1803 | 2.94 | 14.70 | GBP
56 | ABM8-25.000MHZ-B2-T | ABRACON | ABRACON - ABM8-25.000MHZ-B2-T - CRYSTAL, 25M, 18PF CL, 3.2X2.5MM SMT | XTAL_small |  | 1 | Farnell | 1611821 | 5 | 592 | 0.83 | 4.17 | GBP
 |  |  |  |  |  | 176 |  |  | 840 |  |  | 362.389
Approved |  |  |  | Notes
 |  |  |  |  |  | 5 | pcs: | Total |  | 362.389 |  | <none>
 |  |  |  |  |  |  |  | Price for 1pcs |  | 72.48 |  | <none>

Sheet: Project Information
Project Full Path | C:\Users\vojislav\Documents\koruza-compute-module\koruza-compute-module-board\koruza-compute-module-board.PrjPcb
Project Filename | koruza-compute-module-board.PrjPcb
Variant Name | None
Data-Source Filename | koruza-compute-module-board.PrjPcb
Data-Source Full Path | C:\Users\vojislav\Documents\koruza-compute-module\koruza-compute-module-board\koruza-compute-module-board.PrjPcb
Title | <Parameter Title not found>
Total Quantity | 189
Report Time | 8:45:27 AM
Report Date | 08/31/2017
Report Date & Tine | 08/31/2017 8:45:27 AM
Output Name | Bill of Materials
Output Type | BOM_PartType
Output Generator Name | BOM
Output Generator Description | Bill of Materials

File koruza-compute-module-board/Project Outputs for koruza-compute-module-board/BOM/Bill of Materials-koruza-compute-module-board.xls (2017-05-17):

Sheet: Part List Report
 | Component list |  |  | Bill of Materials For Project [koruza-compute-module-board.PrjPcb] (No PCB Document Selected)
 | Source Data From: | koruza-compute-module-board.PrjPcb |  |  | Contact: |  |  |  | Generated by:
 | Project: | koruza-compute-module-board.PrjPcb
 | Variant: | None |  |  |  |  |  |  | FEDEVEL
 | Report Date: | 05/12/2017 | 4:55:51 PM |  |  |  |  |  | http://www.fedevel.com
 | Print Date: | 2017-05-13 | 10:17:47
# | Category | Manufacturer 1 | Manufacturer Part Number 1 | #Column Name Error:Package / Case | Description | Quantity | Supplier 1 | Supplier Part Number 1 | Supplier Order Qty 1 | Supplier Stock 1 | Supplier Unit Price 1 | Supplier Subtotal 1 | Supplier Currency 1
1 | Modular Connectors / Ethernet Connectors | Bel Fuse | 0826-1L1T-57-F |  | 1 Port RJ45 Magjack Connector Through Hole 10/100 Base-T, AutoMDIX, Power over Ethernet (PoE) | 1 | Mouser | 530-0826-1L1T-57-F | 25 | 1590 | 4.58 | 114.50 | EUR
2 | Board Mount Humidity Sensors | Bosch Sensortec | BME280 |  | Board Mount Humidity Sensors | 1 | Mouser | 262-BME280 | 25 | 27093 | 5.06 | 126.50 | EUR
3 | Fixed Inductors | Murata Electronics | LQH3NPN100MG0L |  | Fixed Inductors 1212 10uH 20% | 1 | Mouser | 81-LQH3NPN100MG0L | 25 | 0 | 0.30 | 7.58 | EUR
4 | MOSFET | Diodes Incorporated | DMG1012T-7 |  | MOSFET MOSFET N-CHANNEL SOT-523 | 3 | RS | 751-4064 | 100 | 0 | 0.19 | 14.03 | EUR
5 | FFC & FPC Connectors | TE Connectivity / AMP | 1-1734248-5 |  | Raspberry Pi camera connector | 1 | Mouser | 571-1-1734248-5 | 25 | 1405 | 1.53 | 38.25 | EUR
6 | Voltage Regulators - Switching Regulators | Diodes Incorporated | PAM2306AYPKE |  | Voltage Regulators - Switching Regulators Dual PWM Step-Down 40uA 1A 1.5MHz | 1 | Mouser | 621-PAM2306AYPKE | 25 | 0 | 0.56 | 13.88 | EUR
7 |  | HARWIN | M20-9980545 |  |  | 1 | Farnell | 1022235 | 25 | 12796 | 0.23 | 5.65 | GBP
8 |  | BOURNS | SRN4018-4R7M. |  |  | 2 | Farnell | 2345245 | 50 | -10 | 0.21 | 10.55 | GBP
9 |  | ABRACON | ABM8-25.000MHZ-B2-T |  | ABRACON - ABM8-25.000MHZ-B2-T - CRYSTAL, 25M, 18PF CL, 3.2X2.5MM SMT | 1 | Farnell | 1611821 | 25 | 3422 | 0.66 | 16.45 | GBP
10 |  | AMP - TE CONNECTIVITY | 188275-6 |  | AMP - TE CONNECTIVITY - 188275-6 - CONNECTOR, RCPT, 6POS, 2ROW, 1.27MM | 1 | Farnell | 2452479 | 25 | 851 | 0.45 | 11.12 | GBP
11 |  | AMPHENOL FCI | 10104110-0001LF |  | AMPHENOL FCI - 10104110-0001LF - MICRO USB, 2.0 TYPE B, RECEPTACLE, SMT | 1 | Farnell | 2293753 | 25 | 26778 | 0.45 | 11.22 | GBP
12 |  | AMPHENOL FCI | 73725-0110BLF |  | AMPHENOL FCI - 73725-0110BLF - USB, 2.0 TYPE A, RECEPTACLE, TH | 1 | Farnell | 2112380 | 25 | 5094 | 0.53 | 13.22 | GBP
13 |  | BOURNS | CR0603-J/-000ELF |  | BOURNS - CR0603-J/-000ELF - RES, THICK FILM, 0R, 5%, 0.1W, 0603 | 25 | Farnell | 2008343 | 625 | 43719 | 0.01 | 7.00 | GBP
14 |  | BROADCOM LIMITED | HSMS-C190 |  | BROADCOM LIMITED - HSMS-C190 - LED, RED, 10MCD, 626NM | 4 | Farnell | 2497356 | 100 | 5223 | 0.10 | 9.74 | GBP
15 |  | AMP - TE CONNECTIVITY | 1473005-4 |  | DDR2 SODIMM connector for Raspberry Pi compute module 1/3/3-Lite | 1 | Farnell | 1095877 | 25 | 1678 | 2.68 | 67.00 | GBP
16 |  | FAIRCHILD SEMICONDUCTOR | FSUSB42MUX |  | FAIRCHILD SEMICONDUCTOR - FSUSB42MUX - USB SWITCH, DUAL, DPDT, MSOP-10 | 1 | Farnell | 2564479 | 25 | 4826 | 0.30 | 7.42 | GBP
17 |  | XP POWER | ITX2409SA |  | Isolated Board Mount DC/DC Converter, 2:1 Input, Fixed, 1 Output, 18 V, 36 V, 6 W, 9 V | 1 | Farnell | 2422810 | 25 | -1 | 15.38 | 384.50 | GBP
18 |  | MURATA POWER SOLUTIONS | SPM15-050-Q12P-C |  | Isolated Board Mount DC/DC Converter, Medical, Fixed, 1 Output, 9 V, 36 V, 15 W, 5 V | 1 | Farnell | 2470131 | 25 | 76 | 28.95 | 723.75 | GBP
19 |  | KEMET | C1206C221KGRACTU |  | KEMET - C1206C221KGRACTU - CAP, MLCC, X7R, 220PF, 2KV, 1206 | 2 | Farnell | 2676444RL | 50 | 1629 |  |  | GBP
20 |  | MULTICOMP | MC0063W0603112K |  | MULTICOMP - MC0063W0603112K - RES, THICK FILM, 12K, 1%, 0.063W, 0603 | 1 | Farnell | 2130943 | 25 | 724996 |  |  | GBP
21 |  | MULTICOMP | MC0063W0603112K4 |  | MULTICOMP - MC0063W0603112K4 - RES, THICK FILM, 12K4, 1%, 0.063W, 0603 | 1 | Farnell | 1170897 | 25 | 1859 | 0.01 | 0.28 | GBP
22 |  | MULTICOMP | MC0063W060311M |  | MULTICOMP - MC0063W060311M - RES, THICK FILM, 1M, 1%, 0.063W, 0603 | 1 | Farnell | 9330410 | 25 | 177136 | 0.0011 | 0.03 | GBP
23 |  | MULTICOMP | MCMR06X102 JTL |  | MULTICOMP - MCMR06X102 JTL - RES, CERAMIC, 1K, 5%, 0.1W, 0603 | 2 | Farnell | 2073354 | 50 | 10741 | 0.01 | 0.32 | GBP
24 |  | MULTICOMP | MCMR06X103 JTL |  | MULTICOMP - MCMR06X103 JTL - RES, CERAMIC, 10K, 5%, 0.1W, 0603 | 3 | Farnell | 2073356 | 75 | 15351 | 0.01 | 0.47 | GBP
25 |  | MULTICOMP | MCMR06X104 JTL |  | MULTICOMP - MCMR06X104 JTL - RES, CERAMIC, 100K, 5%, 0.1W, 0603 | 4 | Farnell | 2073357 | 100 | 17 | 0.0038 | 0.38 | GBP
26 |  | MULTICOMP | MCMR06X4702FTL |  | MULTICOMP - MCMR06X4702FTL - RES, CERAMIC, 47K, 1%, 0.1W, 0603 | 3 | Farnell | 2073510 | 75 | 13267 | 0.01 | 0.64 | GBP
27 |  | MULTICOMP | MCMR06X471 JTL |  | MULTICOMP - MCMR06X471 JTL - RES, CERAMIC, 470R, 5%, 0.1W, 0603 | 5 | Farnell | 2073513 | 125 | 3496 | 0.01 | 0.95 | GBP
28 |  | MULTICOMP | MCMR12X000 PTL |  | MULTICOMP - MCMR12X000 PTL - RES, CERAMIC, 0R, 0.05OHM, 0.25W, 1206 | 3 | Farnell | 2073874 | 75 | 497468 | 0.02 | 1.44 | GBP
29 |  | MURATA | BLM18EG221SN1D |  | MURATA - BLM18EG221SN1D - FERRITE BEAD, 0.05OHM, 2A, 0603 | 2 | Farnell | 1515716 | 50 | 50563 | 0.10 | 4.83 | GBP
30 |  | MURATA | GRM1885C1H200JA01D |  | MURATA - GRM1885C1H200JA01D - CAPACITOR, MLCC, C0G, 20PF, 50V, 0603 | 4 | Farnell | 2456108 | 100 | 23093 | 0.02 | 1.59 | GBP
31 |  | MURATA | GRM1885C1H330JA01D |  | MURATA - GRM1885C1H330JA01D - CAP, MLCC, C0G/NP0, 33PF, 50V, 0603 | 2 | Farnell | 1828910 | 50 | 8002 | 0.02 | 0.78 | GBP
32 |  | MURATA | GRM188R61C105KA12D |  | MURATA - GRM188R61C105KA12D - CAP, MLCC, X5R, 1UF, 16V, 0603 | 3 | Farnell | 2362099 | 75 | 25820 |  |  | GBP
33 |  | MURATA | GRM188R61C106MA73D |  | MURATA - GRM188R61C106MA73D - CAP, MLCC, X5R, 10UF, 16V, 0603 | 8 | Farnell | 2426958 | 200 | 37767 | 0.10 | 20.60 | GBP
34 |  | MURATA | GRM188R71C104KA01J |  | MURATA - GRM188R71C104KA01J - CAP, MLCC, X7R, 0.1UF, 16V, 0603 | 28 | Farnell | 2688519 | 700 | 17667 | 0.01 | 5.46 | GBP
35 |  | MURATA | GRM21BR61A476ME15L |  | MURATA - GRM21BR61A476ME15L - CAP, MLCC, X5R, 47UF, 10V, 0805 | 3 | Farnell | 2611939 | 75 | 2584 | 0.30 | 22.27 | GBP
36 |  | MURATA | GRM21BR71C105KA01L |  | MURATA - GRM21BR71C105KA01L - CAP, MLCC, X7R, 1UF, 16V, 0805 | 1 | Farnell | 9527710 | 25 | 30805 | 0.04 | 1.01 | GBP
37 |  | MURATA | GRM31CR61H106KA12L |  | MURATA - GRM31CR61H106KA12L - CAP, MLCC, X5R, 10UF, 50V, 1206 | 3 | Farnell | 1845762 | 75 | -2 | 0.22 | 16.20 | GBP
38 |  | RASPBERRY-PI | RPI COMPUTE MODULE |  | RASPBERRY-PI - RPI COMPUTE MODULE - COMPUTE MODULE, RASPBERRY PI DEV BOARD | 1 | Farnell | 2427122 | 25 | -2 | 19.50 | 487.50 | GBP
39 |  | TDK | CGA4J1X5R1C106K125AC |  | TDK - CGA4J1X5R1C106K125AC - CAP, MLCC, X5R, 10UF, 16V, 0805 | 5 | Farnell | 2210948 | 125 | 6414 |  |  | GBP
40 |  | TE CONNECTIVITY | 2007194-1 |  | TE CONNECTIVITY - 2007194-1 - CAGE, 1X1, SFP+, PCI APPLICATIONS | 1 | Farnell | 1755779 | 25 | 68 | 3.68 | 92.00 | GBP
41 |  | TEXAS INSTRUMENTS | REG1117 |  | TEXAS INSTRUMENTS - REG1117 - V REG LDO ADJ +1.5/13.7V, SMD, 1117 | 1 | Farnell | 1097566 | 25 | 550 | 1.53 | 38.25 | GBP
42 |  | MICROCHIP | LAN9512-JZX |  | USB 2.0 Hub and 10/100 Ethernet Controller | 1 | Farnell | 2292586 | 25 | 588 | 3.23 | 80.75 | GBP
43 |  | VISHAY | CRCW06031K80FKEA |  | VISHAY - CRCW06031K80FKEA - RES, THICK FILM, 1K8, 1%, 0.1W, 0603 | 6 | Farnell | 1652854 | 150 | 11759 | 0.01 | 1.44 | GBP
44 |  | VISHAY | CRCW060349R9FKEA |  | VISHAY - CRCW060349R9FKEA - RES, THICK FILM, 49R9, 1%, 0.1W, 0603 | 4 | Farnell | 1469817 | 100 | 4204 | 0.01 | 0.94 | GBP
45 |  | Loading... | Loading... |  | VISHAY - RCA060310R0FKEA - RES, AUTO, THICK FILM, 10R, 1%, 0603 | 1 | Farnell | 2616585 |  |  |  |  | Loading...
46 |  | WURTH ELEKTRONIK | 450302014072 |  | WURTH ELEKTRONIK - 450302014072 - SWITCH, SLIDE, MINI, ON-ON, RIGHT ANGLE | 1 | Farnell | 2134453 | 25 | 262 | 1.66 | 41.50 | GBP
47 |  | WURTH ELEKTRONIK | 74479773210 |  | WURTH ELEKTRONIK - 74479773210 - INDUCTOR, MULTILAYER, 1UH, SMD | 4 | Farnell | 2400015 | 100 | 36 | 0.29 | 29.00 | GBP
48 | Connectors, Interconnects | Sullins Connector Solutions | QPC02SXGN-RC |  | CONN JUMPER SHORTING .100" GOLD | 1 | Digi-Key | S9337-ND | 25 | 125560 | 0.05 | 1.37 | USD
49 | Optoelectronics | Adafruit Industries LLC | 1655 |  | LED RGB WS2812 OR SK6812 1=10 | 1 | Digi-Key | 1528-1104-ND | 25 | 6446 | 4.50 | 112.50 | USD
50 |  |  |  |  |  | 1
51 |  |  |  |  | Capacitor | 2
52 |  |  |  |  | Header, 15-Pin, Dual row | 1
53 |  |  |  |  | Header, 9-Pin, Dual row | 1
 |  |  |  |  |  | 159 |  |  | 3850 |  |  | 2544.8675
Approved |  |  |  | Notes
 |  |  |  |  |  | 25 | pcs: | Total |  | 2544.8675 |  | <none>
 |  |  |  |  |  |  |  | Price for 1pcs |  | 101.79 |  | <none>

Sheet: Project Information
Project Full Path | C:\Users\vojislav\Documents\koruza-compute-module\koruza-compute-module-board\koruza-compute-module-board.PrjPcb
Project Filename | koruza-compute-module-board.PrjPcb
Variant Name | None
Data-Source Filename | koruza-compute-module-board.PrjPcb
Data-Source Full Path | C:\Users\vojislav\Documents\koruza-compute-module\koruza-compute-module-board\koruza-compute-module-board.PrjPcb
Title | Bill of Materials For Project [koruza-compute-module-board.PrjPcb] (No PCB Document Selected)
Total Quantity | 159
Report Time | 4:55:51 PM
Report Date | 05/12/2017
Report Date & Tine | 05/12/2017 4:55:51 PM
Output Name | Bill of Materials
Output Type | BOM_PartType
Output Generator Name | BOM
Output Generator Description | Bill of Materials

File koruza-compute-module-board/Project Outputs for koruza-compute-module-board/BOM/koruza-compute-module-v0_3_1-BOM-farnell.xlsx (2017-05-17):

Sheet: Part List Report
 | Component list |  |  | <Parameter ProjectTitle not found>
 | Source Data From: | koruza-compute-module-board.PrjPcb |  |  | Contact:
 | Project: | koruza-compute-module-board.PrjPcb
 | Variant: | None |  |  |  |  |  |  | Koruza
 | Report Date: | 05/13/2017 | 10:14:47 AM |  |  |  |  |  | www.koruza.net
 | Print Date: | 2017-05-16 | 15:22:14
# | Manufacturer Part Number 1 | Manufacturer 1 | Description | Footprint | Category | Quantity | Supplier 1 | Supplier Part Number 1 | Supplier Order Qty 1 | Supplier Stock 1 | Supplier Unit Price 1 | Supplier Subtotal 1 | Supplier Currency 1
1 | 1655 | Adafruit Industries LLC | LED RGB WS2812 OR SK6812 1=10 | LED_SMD5050 | Optoelectronics | 1 | Digi-Key | 1528-1104-ND | 25 | 6446 | 4.50 | 112.50 | USD
2 | 450302014072 | WURTH ELEKTRONIK | WURTH ELEKTRONIK - 450302014072 - SWITCH, SLIDE, MINI, ON-ON, RIGHT ANGLE | SW ANGLE 3PIN |  | 1 | Farnell | 2134453 | 25 | 262 | 1.66 | 41.50 | GBP
3 | 74479773210 | WURTH ELEKTRONIK | WURTH ELEKTRONIK - 74479773210 - INDUCTOR, MULTILAYER, 1UH, SMD | CAP0805 |  | 4 | Farnell | 1869749 | 100 | 2187 | 0.29 | 29.00 | GBP
4 | CRCW06031K80FKEA | VISHAY | VISHAY - CRCW06031K80FKEA - RES, THICK FILM, 1K8, 1%, 0.1W, 0603 | RES0603 |  | 6 | Farnell | 1652854 | 150 | 11759 | 0.01 | 1.44 | GBP
5 | CRCW060349R9FKEA | VISHAY | VISHAY - CRCW060349R9FKEA - RES, THICK FILM, 49R9, 1%, 0.1W, 0603 | RES0603 |  | 4 | Farnell | 1469817 | 100 | 4204 | 0.01 | 0.94 | GBP
6 | RCA060310R0FKEA | VISHAY | VISHAY - RCA060310R0FKEA - RES, AUTO, THICK FILM, 10R, 1%, 0603 | RES0603 |  | 1 | Farnell | 2616585 | 25 | 9289 | 0.08 | 2.01 | GBP
7 | REG1117 | TEXAS INSTRUMENTS | TEXAS INSTRUMENTS - REG1117 - V REG LDO ADJ +1.5/13.7V, SMD, 1117 | TI-DCY4_N |  | 1 | Farnell | 1097566 | 25 | 550 | 1.53 | 38.25 | GBP
8 | 2007194-1 | TE CONNECTIVITY | TE CONNECTIVITY - 2007194-1 - CAGE, 1X1, SFP+, PCI APPLICATIONS | PCB_SFP_CAGE_FOOTPRINT |  | 1 | Farnell | 1755779 | 25 | 68 | 3.68 | 92.00 | GBP
9 | CGA4J1X5R1C106K125AC | TDK | TDK - CGA4J1X5R1C106K125AC - CAP, MLCC, X5R, 10UF, 16V, 0805 | CAP0805 |  | 5 | Farnell | 2210948 | 125 | 6414 | 0.16 | 20.00 | GBP
10 | BLM18EG221SN1D | MURATA | MURATA - BLM18EG221SN1D - FERRITE BEAD, 0.05OHM, 2A, 0603 | CAP0603 |  | 2 | Farnell | 1515716 | 50 | 50563 | 0.10 | 4.83 | GBP
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

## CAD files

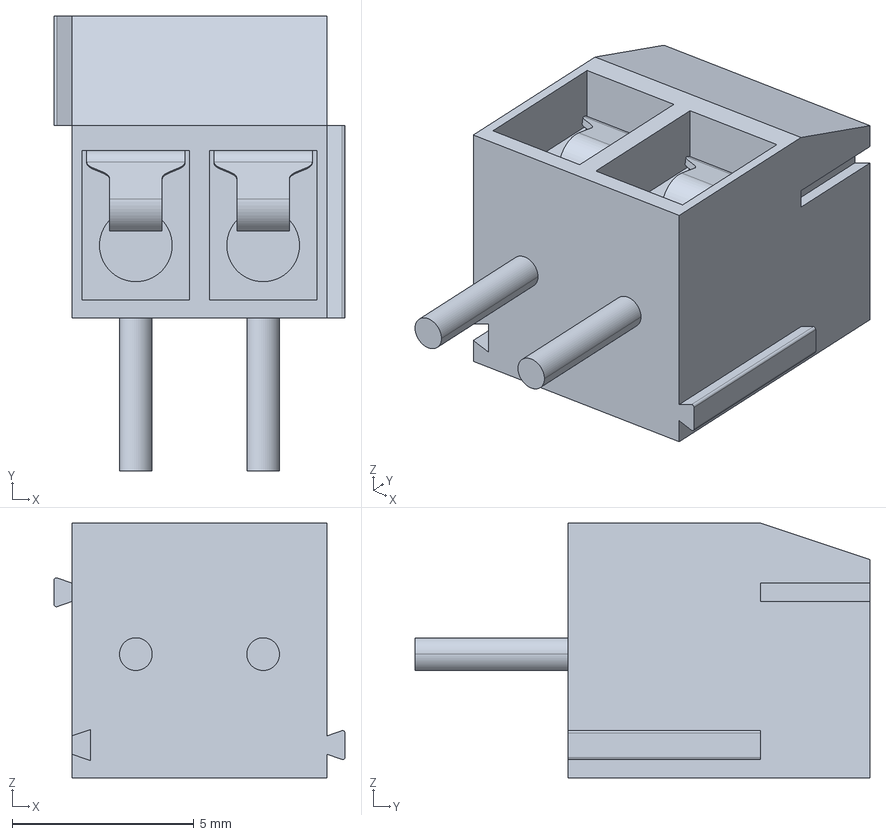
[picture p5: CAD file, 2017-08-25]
koruza-compute-module-board/step/block-terminal-2way-3.5mm.stp
8.00 x 12.5 x 7.00 mm

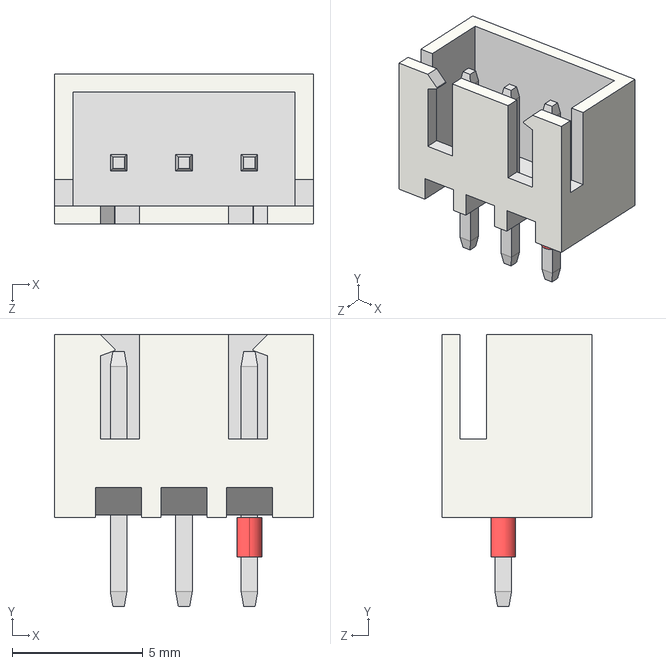
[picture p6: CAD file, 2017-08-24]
koruza-compute-module-board/step/jst-b3b-xh-a.step
9.90 x 10.4 x 5.75 mm

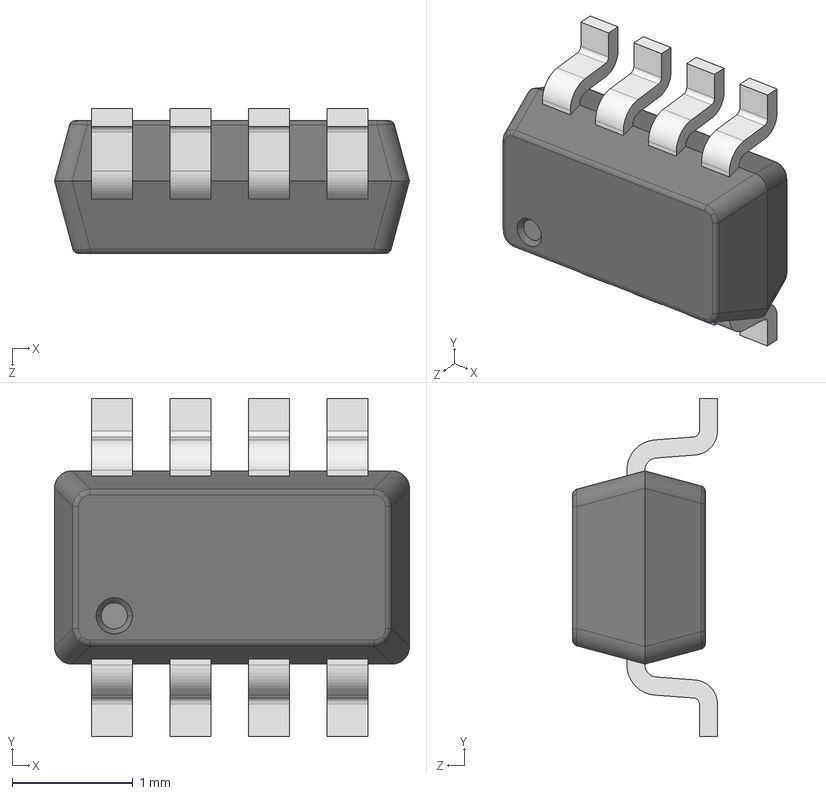
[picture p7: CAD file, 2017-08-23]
koruza-compute-module-board/step/sot238.step
2.94 x 2.80 x 1.20 mm

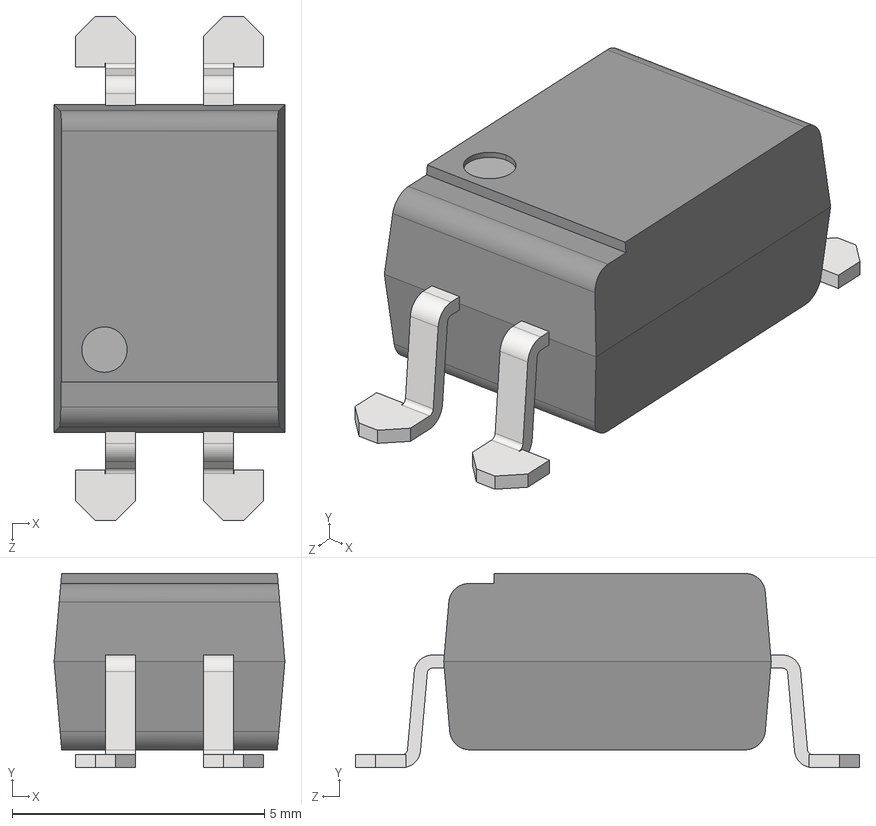
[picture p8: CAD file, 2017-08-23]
koruza-compute-module-board/step/PC817.STEP
4.58 x 3.85 x 10.0 mm
User Library-PC817_Gullwing_PC817 Body
User Library-PC817_Gullwing_Gullwing Pin
User Library-PC817_Gullwing_Gullwing Pin_MIR
User Library-PC817_Gullwing_Gullwing Pin_MIR1
User Library-PC817_Gullwing_Gullwing Pin_MIR_MIR

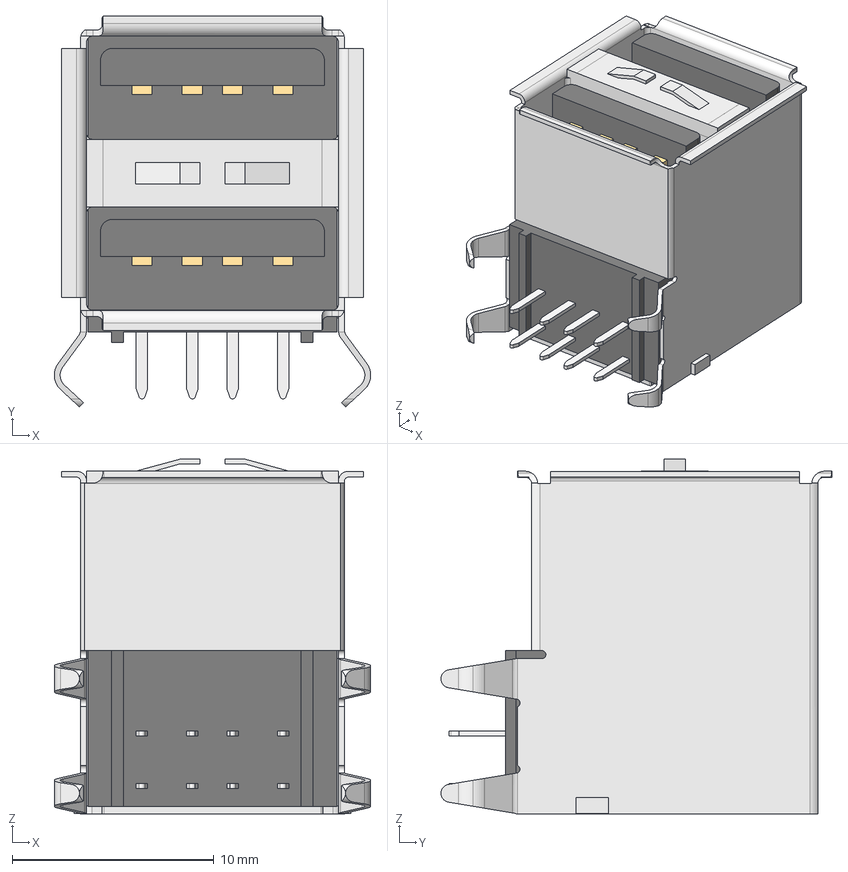
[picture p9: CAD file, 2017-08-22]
koruza-compute-module-board/step/usb_a-usb_a-2p-c.stp
15.7 x 19.4 x 17.6 mm

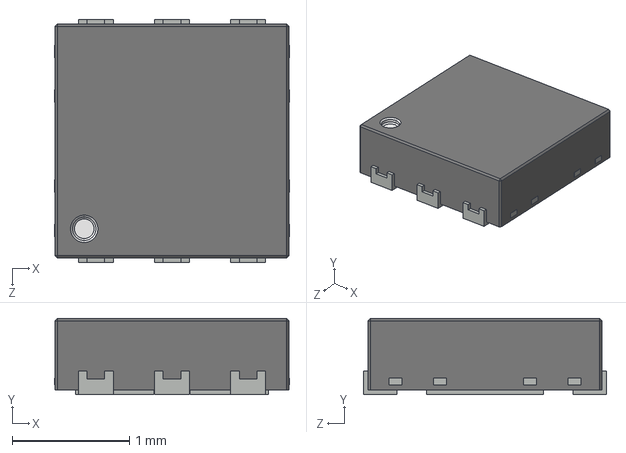
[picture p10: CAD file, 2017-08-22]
koruza-compute-module-board/step/DFN2020-6.step
2.01 x 0.65 x 2.08 mm

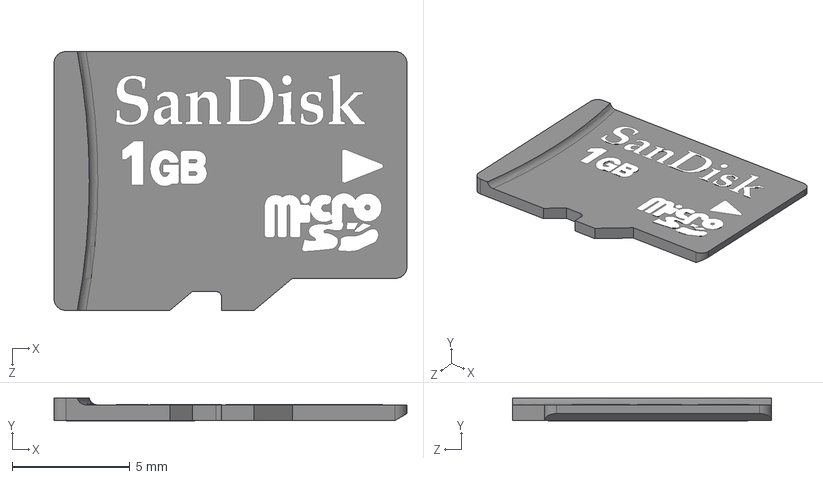
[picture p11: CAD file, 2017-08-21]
koruza-compute-module-board/step/User Library-Micro_SD.step
15.0 x 0.975 x 11.0 mm

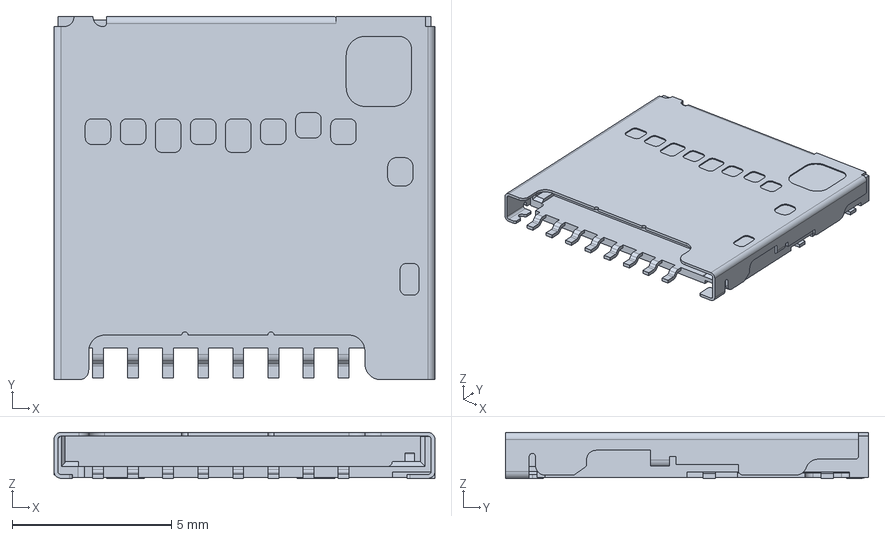
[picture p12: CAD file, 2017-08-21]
koruza-compute-module-board/step/1040310811.stp
11.9 x 11.4 x 1.45 mm

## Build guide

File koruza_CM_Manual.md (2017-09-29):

# Koruza Compute Module board Manual

This document is dedicated to the Koruza CM board and all its features. 

## Introduction
Koruza CM board is the base board for the Raspberry Pi Compute Module CM1, CM3 and CM3Lite. The Raspberry Pi Compute Module (CM1), Compute Module 3 (CM3) and Compute Module 3 Lite
(CM3L) are DDR2-SODIMM-mechanically-compatible System on Modules (SoMs) containing processor, memory, eMMC Flash (for CM1 and CM3) and supporting power circuitry.

The CM1 contains a BCM2835 processor (as used on the original Raspberry Pi and Raspberry Pi B+ models), 512MByte LPDDR2 RAM and 4Gbytes eMMC Flash. The CM3 contains a BCM2837 processor (as used on the Raspberry Pi 3), 1Gbyte LPDDR2 RAM and 4Gbytes eMMC Flash. Finally the CM3L product is the same as CM3 except the eMMC Flash is not fitted, and the SD/eMMC interface pins are available for the user to connect their own SD/eMMC device.

Note that the BCM2837 processor is an evolution of the BCM2835 processor. The only real differences are that the BCM2837 can address more RAM (up to 1Gbyte) and the ARM CPU complex has been upgraded from a single core ARM11 in BCM2835 to a Quad core Cortex A53 with dedicated 512Kbyte L2 cache in BCM2837. All IO interfaces and peripherals stay the same and hence the two chips are largely software and hardware compatible.

All three versions of the Raspberry Pi compute module are supproted by the Koruza CM board.

## Features
Koruza CM board has many interfaces:
* GPIO Expansion header
  * IO pins
  * 2x UART
  * I2C
  * USB (Optional)
  * 2x SPI
  * PWM
  * Power
* Onboard 3 Amp DC to DC converter
* Upgrade software over USB
* MicroSC slot (Only for the Raspberry Pi CM3Lite moodule)
* Camera connetor
* Camera Enable Jumper
* 4x Host USB 2.0
* Ethernet 10/100 + PoE
  * Ethernet Bandwidth: 10Base-T/100Base-TX
  * 24VDC Passive PoE Input
* SFP Controle connector
* 24 VDC Power Input
* ESD protection for USB and Ethernet

## Block Diagram
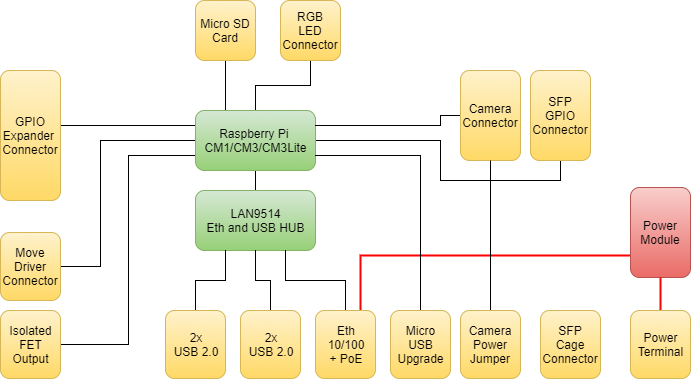
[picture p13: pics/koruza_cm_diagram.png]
koruza_cm_block_diagram


*Power module block is explained in section "Power supply"

## Mechanical Specification
The picture below shows the Koruza CM board dimension, cutouts and holes position. Holes dimensions are 3.2mm in diameter.

The maximum komponent height in the top side of the board is 14mm.

The maximum component height on the underside of the board is 2mm (component pins).

Note that the location and arrangement of components on the Koruza CM board may change slightly
over time due to revisions for cost and manufacturing considerations; however, maximum component
heights and PCB thickness and connectors positions will be kept as specified.

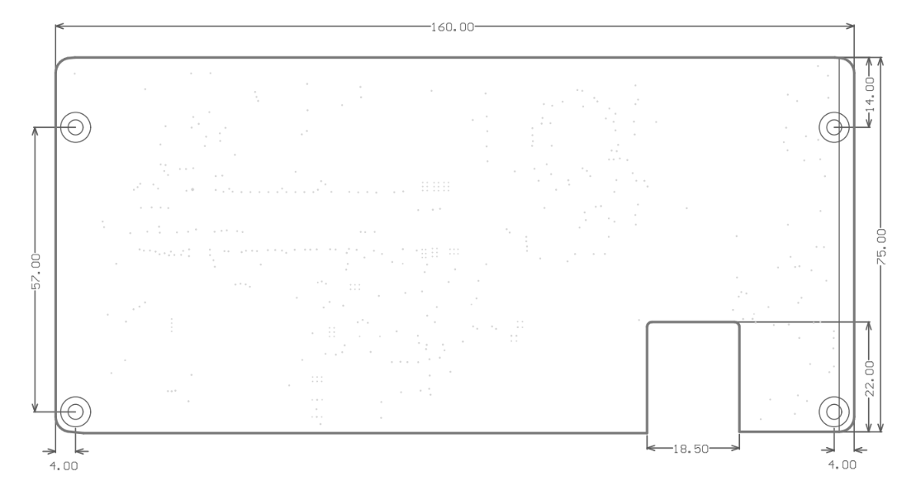
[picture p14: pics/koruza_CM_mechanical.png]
koruza_CM_mechanical


## Power sypply
  ### Power Requirements
  
Exact power requirements will be heavily dependent upon the individual use case. If an on-chip subsystem is unused, it is usually in a low power state or completely turned off. For instance, if your application does not use 3D graphics then a large part of the core digital logic will never turn on and need power. This is also the case for camera, USB interfaces, video encoders and decoders, and so on.

Powerchain design is critical for stable and reliable operation of the Compute Module. We strongly recommend that designers spend time measuring and verifying power requirements for their particular use case and application, as well as paying careful attention to power supply sequencing and maximum supply voltage tolerance.

Recomended power input for the Koruza CM board is 24VDC 1A. 
  
  ### Power Diagram
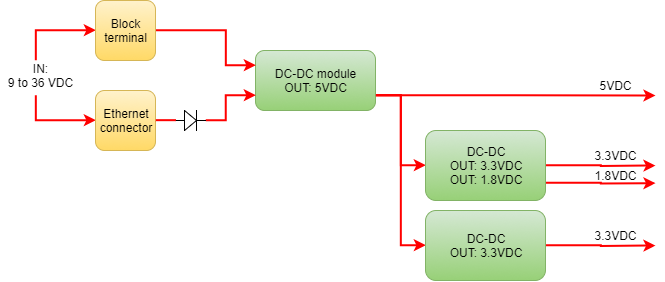
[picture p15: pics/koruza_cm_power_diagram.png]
koruza_CM_power_diagram
  

## Board peripherials
  ### Ethernet 
  
  ### USB Port
  ### Camera
  ### MicroSD Card
  ### UART Connector (Move Driver)
  ### Isolated FET output
  ### Front panle GPIO
  ### Expander GPIO connector

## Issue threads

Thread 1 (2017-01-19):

Power supply

VojislavM, 2017-01-19:
Power supply diagram:
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

5V and 9V power supply are separated besause on the 9V there is inductive load.

VojislavM, 2017-01-23:
Refer to issue #2

VojislavM, 2017-01-23:
Based on #2  DC DC 5V and 9V are isolated power modules.
Characteristics:
* Vin(5V and 9V) = ~12V to ~36V
* Vout(5V) = 5V, Imax(5V) = ~3A to 4A
* Vout(9V) = 9V, Imax(9V) = ~1A

VojislavM, 2017-01-23:
For the 5V DC-DC:
* Imax = 0.4A + 2*1A + max(0.4A, 0.7A) = 3.1A

Because Raspberry Pi compute module won't use some parts of the system like GPU, 3D graphics, HDMI, etc. the overall consumption will be smaller, so we can use the 3A@5V output on the isolated DC-DC power supply.

After testing, gettering the data about consumption and analyzing it, we can probably decrease the power of the DC-DC output.

Current optimal solution for 5V, without knowing the consumption data, is[ MURATA POWER SOLUTIONS  SPM15-050-Q12P-C  Isolated Board Mount DC/DC Converter](http://uk.farnell.com/murata-power-solutions/spm15-050-q12p-c/dc-dc-conv-medical-15w-5v-3a/dp/2470131)

VojislavM, 2017-01-23:
### FOR the 9V DC-DC:
The motor is normally rated at 5V and ~60 ohms, so each winding will take ~80mA with one
winding active, ~160mA with two (some step patterns like full-wave do this). Because the [24byj48-03](http://irnas.eu/downloads/TaskMechEng/24BYJ48-03-4.pdf) stepper motor is not relayble at 5V it is better to use 9V or 12V
At 9V supply those values will be 150mA and 300mA, and at 12V  supply those values will be 200mA and 400mA instead.

At worst scenario we will have two motors running, so:
* Imax(9V) = 2 * 300mA + 7.4mA(for the [MCU](https://www.avrprogrammers.com/howto/atmega328-power)) = 607.4 mA
* Imax(12V) = 2 * 400mA + 7.4mA(for the [MCU](https://www.avrprogrammers.com/howto/atmega328-power)) = 807.4 mA

Because lowering the power is always the priority, 9V power output from the DC-DC module is more then enough. Also Imax should not be below 650mA.

After testing, gettering the data about consumption and analyzing it, we can probably decrease the power of the DC-DC output.

Current optimal solution for 5V, without knowing the consumption data, is [XP POWER  ITX2409SA  Isolated Board Mount DC/DC Converter](http://uk.farnell.com/xp-power/itx2409sa/dc-dc-converter-6w-9v-0-666a/dp/2422810)

VojislavM, 2017-01-23:
### For SFP 3V3:
One SFP module uses aproximatly ~ 200mA so:
* Imax = 2 * 200mA = 400mA

Because there is low voltage drop, form 5V to 3.3V we will use [Low Dropout Positive Regulator REG1117](http://www.ti.com/lit/ds/symlink/reg1117.pdf)

VojislavM, 2017-01-23:
### For CM 3V3 and 1V8:
Currently the [PAM2306](http://www.diodes.com/_files/datasheets/PAM2306.pdf) is in use. It is recommended form Raspberry pi foundation and it is on there CM base board.

Other option for 3V3 and 1V8 is Low Dropout Positive Regulator REG1117 with 1A output. Is is less efficient because it is linear but it is easier to solder by hand, but PAM2306AYPKE is several time cheaper.

VojislavM, 2017-08-16:
In the new version there is no need for 9V power regulator. There will be only 5V and that vlotage will be step up on the move driver.

VojislavM, 2017-08-16:
5V DCDC module will stay same, because it has more then enough power for the hole system. Onother option will be separate koruza-power-module with the same footprint

VojislavM, 2017-08-16:
another option for power is non isolated DCDC the one form #2

VojislavM, 2017-08-17:
There will be two option, both with 5V output:
1. Isolated: [DCDC converter](http://uk.farnell.com/murata-power-solutions/spm15-050-q12p-c/dc-dc-conv-medical-15w-5v-3a/dp/2470131)
2. Non-Isolated: [koruza-power-module](https://github.com/IRNAS/koruza-power-module)

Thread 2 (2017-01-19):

isolated vs non-isolated power supply

VojislavM, 2017-01-19:
Is there need for 5V and 9V power supplies to be isolated?

isolated suggestions:
* http://uk.farnell.com/xp-power/jcd0424s09/dc-dc-converter-4w-9v-dip-24/dp/2065194
* http://uk.farnell.com/murata-power-solutions/spm15-050-q12p-c/dc-dc-conv-medical-15w-5v-3a/dp/2470131

non-isolated suggestions:
* both for 9V and 5V: http://uk.farnell.com/texas-instruments/ptn78060waz/ic-isr-3a-adj-o-p-smd-78060/dp/1109705

if we put isolated power supplies, the whole devise will be isolated because Ethernet data lines are isolated with internal transformers

VojislavM, 2017-01-23:
Because of the noise it is better for device to be electrically isolated, so isolated power modules are way to go.
New question is where should metal conductive casing be connected?

VojislavM, 2017-08-17:
We will support both options, see #1

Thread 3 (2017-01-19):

Ethernet connector

VojislavM, 2017-01-19:
The Ethernet connector is:
* http://www.digikey.com/product-detail/en/bel-fuse-inc/0826-1L1T-57-F/507-1431-ND/2107996

Need to check:
* Ethernet PoE pins
* Ethernet pins 5 and 10, do they go to GND?
* Ethernet does shield go to GND?

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

VojislavM, 2017-01-23:
This connector can be also find at mouser electronics: http://eu.mouser.com/search/ProductDetail.aspx?R=0virtualkey0virtualkey0826-1L1T-57-F

VojislavM, 2017-01-24:
Pins 4 and 5 coming form the cable side are positive end of passive PoE power supply, and pins 7 and 8 are negative end (GND).

Pins 5 and 10 on the connector side are not used, and they will be connected to the ground over zero resistors

VojislavM, 2017-08-16:
the connector for the new version has same configuration, but instead of connecting pins 5 and 10 to the ground they will be also used for power. This is the case with gigabit PoE. So eather passive PoE or gigabit PoE is connected the module will have power.

VojislavM, 2017-08-17:
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

SloMusti, 2017-10-07:
Gigabit power checked with Ubiquiti Gigabit PoE supply and works as expected.

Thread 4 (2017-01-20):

Camera connector

VojislavM, 2017-01-20:
There is a difference between camera connectors on Raspberry Pi 1, 2 and 3 and Raspberry pi CM base board.

## Raspberry Pi 3 camera connector:
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

## Raspberry Pi CM base board camera connector:
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

VojislavM, 2017-01-20:
Camera 1 interface is used as the primary camera interface

VojislavM, 2017-01-20:
## STEPS TO ATTACH A RASPBERRY PI CAMERA (TO CAM1)

* Attach the 0.5mm 22W FFC flexi (included with the adaptor board) to the CAM1 connector (flex contacts face down).
* Attach the camera adaptor board to the other end of the 0.5mm flex (flex contacts face down).
* Attach a Raspberry Pi Camera to the other, larger 15W 1mm FFC on the camera adaptor board (contacts on the Raspberry Pi Camera flex must face up).
* Attach CD1_SDA (J6 pin 37) to GPIO0 (J5 pin 1).
* Attach CD1_SCL (J6 pin 39) to GPIO1 (J5 pin 3).
* Attach CAM1_IO1 (J6 pin 41) to GPIO2 (J5 pin 5).
* Attach CAM1_IO0 (J6 pin 43) to GPIO3 (J5 pin 7).

## https://www.raspberrypi.org/documentation/hardware/computemodule/cmio-camera.md

VojislavM, 2017-01-20:
Because we do not want to use camera adapter board, 15 pin connector will be used:
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

VojislavM, 2017-01-24:
## Camera connector:
It will be vertical SMD connector, because of the limited space inside of the Koruza unit. This way flax cable will easily connect to the board.
Connector part number: 1-1734248-5
Available:
* [digikey](http://www.digikey.com/product-detail/en/te-connectivity-amp-connectors/1-1734248-5/A101418CT-ND/2567554)
* [mouser](http://eu.mouser.com/ProductDetail/TE-Connectivity-AMP/1-1734248-5/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)

VojislavM, 2017-01-30:
There is no need for trace length matching on camera differential pairs, but it would be ok to have ti.

VojislavM, 2017-01-31:
The SDA and SCL pins must be either GPIO0 and GPIO1 or GPIO28 and 29 and must be individual to each camera.

VojislavM, 2017-01-31:
## Camera 1 I2C and IO interface:

| interface       | GPIO          | function  |
| ------------- |:-------------:| -----:|
| I2C0 | GPIO0 | SDA |
| I2C0 | GPIO1 | SCL |
| GPIO | GPIO4 | CAM_GPIO |
| GPIO | GPIO5 | CAM_CLK |

VojislavM, 2017-08-17:
disconnect pins on the PCB, they are connected thru  the connector

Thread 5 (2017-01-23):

LAN and USB HUB

VojislavM, 2017-01-23:
Because [Raspberry Pi compute module](https://www.raspberrypi.org/products/compute-module/) has no Ethernet pins additional "bridge" is needed. Best solution for this is widely used [LAN9512 USB 2.0 Hub and 10/100 Ethernet Controller](http://ww1.microchip.com/downloads/en/DeviceDoc/9512.pdf). It will connect to the Raspberry Pi CM USB. On the other side ti will have one Ethernet connector RJ45 with the PoE pins and two USB A female connectors. One will not be populated, because Koruza unit needs only one.

LAN9512 HUB will not be directly connected to the RPi CM. It will be connected thru the USB MUX [FSUSB42UMX](http://www.mouser.com/ds/2/149/FSUSB42-112719.pdf) because the RPi CM has option to be booted form the USB, and this is something Koruza units could possible use. If unnecessary USB connector should not be populated.

VojislavM, 2017-01-23:
### Specifics in design:
* USB 2 and USB 3 are used
* HUB can be restarted from the RPi CM GPIO6 PIN
* **nTRST pin** This active low pin functions as the JTAG test port reset input. Note: This pin should be tied high if it is not used.
* **TEST3 PIN**  this pin must always be connected to VDD33IO for proper operation.
* **AUTOMDIX PIN** Determines the default Auto-MDIX setting. 1 = Auto-MDIX is enabled.
* **EXRES**  Used for the internal bias circuits. Connect to an external 12.4K 1.0% resistor to ground.
* **USBRBIAS**  Connect to an external 12K 1.0% resistor to ground.

VojislavM, 2017-03-29:
Consider change to newer LAN9514

VojislavM, 2017-08-17:
Change in the HUB, new version LAN9514, see #37

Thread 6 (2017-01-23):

RPi compute module

VojislavM, 2017-01-23:
Main processor is the [Raspberry Pi Computer module](https://www.raspberrypi.org/products/compute-module/).  It uses 200 Pin SODIMM connector for connecting to the board.

This board will be compatible with Raspberry Pi CM1 and CM3. It will not support CM3/Lite.
**CM1:**
- BCM2835 System on Chip (SoC) processor
- Single Core 32bit, 700Mhz
- ARM11 with ARMv6 Instruction Set
- 512MByte LPDDR2 RAM
- 4GBytes eMMC

**CM3:**
- BCM2837 System on Chip (SoC) processor
- Quad Core 64bit, 1.2Ghz
- 512KByte L2 Cache
- ARM Cortex A53 with ARMv7 Instruction Set
- 1GByte LPDDR2 RAM
- 4GBytes eMMC

Due to the CM3 using the BCM2837, this means that consideration needs to be made for power consumption and heat dissipation.
* 2000mW for CM1, 3500mW for CM3/3L*

VojislavM, 2017-01-23:
## Specifics in design:

### GPIO:
* GPIO0 - SDA0/ used for camera module
* GPIO1 - SCL0/ used for camera module
* GPIO2 - SDA/1 used for SFP module
* GPIO3 - SCL1/ used for SFP module
* GPIO4 - /CAM1_GPIO used for camera module
* GPIO5 - /CAM1_CKL used for camera module
* GPIO6 - /HUB_nRESET used for HUB
* GPIO14 - TXD0/used for move driver
* GPIO15 - RXD0/used for move driver
* GPIO16 - CTS0/SFP_LOS used for SFP module
* GPIO18 - /RST used for move driver, reset and firmware upgrade
* GPIO28, GPIO29, GPIO44 and GPIO45 are pulled down

### Camera:
* pins 147 and 149, 153 and 155, 159 and 161, which are differential pairs used for camera, need to have 100 Ohm differential pair impedance.
* pins 165 and 167, which are differential pair used for USB connection to the HUB, need to have 90 Ohm differential pair impedance.

### Power:
* VDAC is connected to the 3.3V

VojislavM, 2017-08-17:
add support for CM3 Lite, see #27

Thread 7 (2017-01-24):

GPIO Expandera port

VojislavM, 2017-01-24:
Koruza computer module board GPIO expander header will be on the left edge of the board. It will be used in the future to connect [Koruza router board](https://github.com/IRNAS/KORUZA-router).

It has:
* USB port, which is also connected to the USB and Ethernet HUB, and if this port wants to be used zero ohm resistors need to be soldered.
* UART
* I2C, which is shared with the SFP module
* GPIO pins
* Power pins, 5V and 3.3V, these are output power pins!

VojislavM, 2017-08-17:
change RGB LED pin so the UART is on the expander connector

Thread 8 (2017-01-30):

I2C-0 Bus

VojislavM, 2017-01-30:
## I2C-0
As part of the B+ improvemets, the Raspberry Pi Foundation has standardized the interface to add-on boards, in what they call the “Hardware Added On Top” (HAT) specification. It standardizes the physical form factor for add-on boards, and includes a provision for the B+ to automatically identify and initialize HATs at startup. It uses an I2C bus to read a description from an EEPROM on the HAT, similar to cape identification on the Beagle Bone Black.

This capability has been carried forward on the A+ and Pi 2 Model B as well. This I2C bus is found on the ID_SC and ID_SD pins (pins 27 and 28 of the 40-pin connector) - but before you get too excited about adding peripherals on that bus, observe the note in the schematic for that port.
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

This is further clarified in the [HAT design guide](https://github.com/raspberrypi/hats/blob/master/designguide.md):

> On a Model B+, GPIO0 (ID_SD) and GPIO1 (ID_SC) will be switched to ALT0 (I2C-0) mode and probed for an EEPROM. These pins will revert to inputs once the probe sequence has completed.
The only allowed connections to the ID_ pins are an ID EEPROM plus 3.9K pull up resistors. Do not connect anything else to these pins!

It’s only there to talk to EEPROMs at addresses 0x50 during boot time. User access at runtime is problematic. If you want a general purpose I2C bus on the B+, you’ll need to use I2C-1, on pins 3 and 5 of the 40-pin connector, marked SDA and SCL on the Pi Wedge.

### Enabling I2C-0
I2C-0 is disabled by default. To enable it, you’ll need to manually edit the configuration file.

Edit /boot/config.txt, and add the following line. If you previously used raspi-config to enable I2C-1 and SPI, you’ll see similar entries near the bottom of the vile.

```
dtparam=i2c_vc=on
```
With that enabled, restart your Pi (sudo reboot). When it’s back up, you’ll know it’s been activated is you’ve got a filesystem node at /dev/i2c-0.

Source: [Link1](https://learn.sparkfun.com/tutorials/raspberry-pi-spi-and-i2c-tutorial)

VojislavM, 2017-01-31:
## I2C 0 interface
It is used for Camera 1, and it cannot be used for other communication see the #4 .

## I2C 1 interface
This port will be used to control two SFP modules. Problem is that both modules have the same address, so they cannot be on the same bus pins.
####Options:
* use two different pins for the same I2C-1 interface, GPIO2/3 and GPIO44/45. Then the Rpi CM will do the runtime switching in the SoC GPIO multiplexer, and simulate two I2C ports for the SFP modules.
* if runtime GPIO switching is not possible one pin pair will be used for I2C communication and additional GPIO pin will be used to drive external I2C MUX or regular GPIO MUX between two SFP connectors.
* use bit-banging I2C on second GPIO pin pair.

kostko, 2017-02-01:
We can switch the GPIO pin functions during runtime, using the [`wiringpi` utility/library](http://wiringpi.com/the-gpio-utility), which is available in the package repository and may be installed via apt-get. For example:
```
gpio -g mode 2 off
gpio -g mode 3 off
gpio -g mode 44 alt2
gpio -g mode 45 alt2
```

There is also a library, so we can also switch functions from withing the `koruza-driver` daemon.

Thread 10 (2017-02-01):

Camera PWR switch

VojislavM, 2017-02-01:
Camera PWR switch need to be added in the next version of the board. This switch will enable the user to turn off camera power manually.

Closed 2017-03-29.

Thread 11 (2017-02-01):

Environment sensor

VojislavM, 2017-02-01:
Add the environment sensor for temperature, humidity and pressure.
[BME280](https://www.bosch-sensortec.com/bst/products/all_products/bme280)

Closed 2017-03-30.

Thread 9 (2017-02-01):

LED ring connector

VojislavM, 2017-02-01:
Led ring connector need to be added in the next version of the board

VojislavM, 2017-03-29:
RPI CM GPIO40 for LED RING (PWM0 mode)

Closed 2017-03-29.

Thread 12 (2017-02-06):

USB switch FSUSB42UMX

VojislavM, 2017-02-06:
The FSUSB42UMX (U6 on the schematic) has bad footprint:
* FSUSB42UMX is UMLP
* FSUSB42MUX  is MSOP

Currently the FSUSB42UMX has MSOP footprint and the problem is the pin numbers are not compatible.

For testing the first boards it could be solved by connecting pins 1 and 2 to 6 and 7. That way hub will be connected to the CM board, but USB boot for the CM will not work. For this stage this is not big problem, but it need to be fixed in the next version/release.

Closed 2017-03-29.

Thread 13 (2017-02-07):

Ethernet connector termination resistors

VojislavM, 2017-02-07:
All ethernet connector termination resistors (R34, R35, R36, R37 / 49.9R) should not be on the 3V3 on one side, instead, they should be connected to the VDD33A.
This is not a big issue, but it needs to be fixed in the next version/revision of the board.

VojislavM, 2017-02-07:
Also, it would be good to rearrange some of the components around LAN9512, and follow the [AN19.20 - LAN9512/LAN9513/LAN9514 Layout Guidelines](http://ww1.microchip.com/downloads/en/AppNotes/en562751.pdf) more accurate.

Closed 2017-03-30.

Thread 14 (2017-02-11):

CM footprint

VojislavM, 2017-02-11:
Footprint for compute module is missing holes on each side.

Closed 2017-03-29.

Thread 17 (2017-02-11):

9V DC-DC footprint

VojislavM, 2017-02-11:
Footprint for 9V DC-DC is bad, need to mirror the top overlay.

VojislavM, 2017-03-29:
Top view of the component  in the datasheet is not correct.

Closed 2017-03-29.

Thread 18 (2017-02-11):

move driver connector pinout

VojislavM, 2017-02-11:
It would be good that connectors on both boards, CM board and move driver board, have same pinout so cables can be easily made...

Possible solution change 2.54 IDC6 connector to smaller one, like micromatch...

Closed 2017-03-29.

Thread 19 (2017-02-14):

HUB oscilator

VojislavM, 2017-02-14:
There should be a 1 MOhm resistor in parallel with the oscillator. If there is no resistor HUB won't boot properly.

Closed 2017-03-30.

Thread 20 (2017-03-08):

current measurement

VojislavM, 2017-03-08:
Add current measurement to the CM

VojislavM, 2017-03-30:
Because the power lines of PoE (+24V) are galvanic isolated, we can not measure current simply. To be discussed for next revision.

VojislavM, 2017-08-17:
current measurement will be done in the 5V line, after the DCDC converter circuit

VojislavM, 2017-08-17:
We need to add current measurement to the koruza unit. There are two options for you to read the value:
* analog value (connected to the one analog pin) [INA169](https://www.adafruit.com/product/1164)
* I2C data (connected to the I2C data bus) [INA219](https://www.adafruit.com/product/904)

VojislavM, 2017-08-17:
Better option is digital sensor (I2C bus). INA219.
we can choose  from 16 different addresses to on the current measurement chip

VojislavM, 2017-08-17:
Current system uses two I2C buses. One is for camera, and it cannot be uses for anything else, and second one is for SFP modules. The modules have same address, and we are using the same bus just on the different pins to overcome this issue.
The I2C pins which are going to the SFP for the wireless optic link are the main one, so we should connect the chip to those pins.

Closed 2017-09-12.

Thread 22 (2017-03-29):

USB connector

VojislavM, 2017-03-29:
Change current USB connector to vertical right angle USB connector to save space on the board.

Closed 2017-03-30.

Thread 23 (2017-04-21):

USB switch problem

VojislavM, 2017-04-21:
USB switch has wrong D+ and D- pin connnections, quick fix for the HUB is on the picture.
Micro USB need to be tested...
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

Closed 2017-05-05.

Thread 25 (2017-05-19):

sfp disable

VojislavM, 2017-05-19:
Link fail signal propagation. Add tx disable pin to the processor

VojislavM, 2017-08-23:
TX_DISABLE_2 -> GPIO8
TX_DISABLE_1 -> GPIO9

Closed 2017-09-12.

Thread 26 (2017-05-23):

Heater for lens

VojislavM, 2017-05-23:
Add one MOSFET output for heater...

SloMusti, 2017-08-09:
via optocopupler for full isolation as we will use input voltage directly

VojislavM, 2017-08-17:
This will be a resistor around 5W
power voltage is 24V so the current will be around 0.208A, and the value of the resistor should be around 115 Ohm

This will be turned on and off over FET with opto isolation

VojislavM, 2017-08-23:
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

Closed 2017-09-12.

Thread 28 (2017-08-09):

Remove 9V power supply

SloMusti, 2017-08-09:
Remove 9V power supply from this board and route 5V to move driver.

VojislavM, 2017-08-16:
Move driver will have small boost on board

VojislavM, 2017-08-17:
see the https://github.com/IRNAS/koruza-move-driver/issues/10

Closed 2017-09-12.

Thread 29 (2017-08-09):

Add LED disable transistor

SloMusti, 2017-08-09:
Add transistor such that all LEDs inside can be disabled, except ethernet port diodes. This prevents from extra light exitign the unit when not needed.

VojislavM, 2017-08-17:
the diodes will be switched with one [MOSFET](http://uk.farnell.com/nxp/nx7002bk/mosfet-n-ch-60v-0-27a-sot-23-3/dp/2469640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)

VojislavM, 2017-08-23:
there are two diodes and they are turned off with separate mosfets Q4 and Q5, but with the same pin. Default state is on which is provided by the pull up resistor R64.

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

Closed 2017-09-12.

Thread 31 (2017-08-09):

Add dual USB port

SloMusti, 2017-08-09:
Replace single USB port with dual.

VojislavM, 2017-08-17:
there will be two dual port USB connectors, One will be on the front, the connector is ordered from the factory. The second dual port will be on the side. footprint will not be populated, and it will be compatible with other connectors.

Closed 2017-09-12.

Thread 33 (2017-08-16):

Mechanical: move SFP cage/connector

VojislavM, 2017-08-16:
Move SFP cage and connector more to the back, to be in line with the ethernet connector when the SFP module is connected.

VojislavM, 2017-08-16:
Move it 10 mm

Closed 2017-09-12.

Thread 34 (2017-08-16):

Mechanical: move USB port

VojislavM, 2017-08-16:
Instead of single A type USB port there will be dual USB #31
Move it a bit back so the USB cable can fit
move back 10 mm

VojislavM, 2017-09-12:
port won't be moved

Closed 2017-09-12.

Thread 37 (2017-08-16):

new HUB LAN9514

VojislavM, 2017-08-16:
Change the current HUB LAN9512 for the new version LAN9514.
This will add two more USB ports to  the design.

VojislavM, 2017-08-17:
LAN9512 and LAN9514 are compatible chips so we can just replace them.
TODO:
* check reference design for LAN9514
* check internal ESD protection

Closed 2017-09-12.

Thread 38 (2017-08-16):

two new USB ports

VojislavM, 2017-08-16:
Add two new USB ports, see #37
Ports will be places on the right side of the SFP cage, instede of the RGB led footprint

VojislavM, 2017-08-17:
see #31

Closed 2017-09-12.

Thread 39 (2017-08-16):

RGB LED connector

VojislavM, 2017-08-16:
Replace the current RGB LED with the connector for the koruza-led-module

Closed 2017-09-12.

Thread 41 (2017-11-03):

U2 problem

VojislavM, 2017-11-03:
Change the U2 for adj to fix 3v3 out on all boards from first batch.
http://uk.farnell.com/texas-instruments/reg1117-3-3/ic-v-reg-ldo-0-8a-3-3v-smd-1117/dp/1212355

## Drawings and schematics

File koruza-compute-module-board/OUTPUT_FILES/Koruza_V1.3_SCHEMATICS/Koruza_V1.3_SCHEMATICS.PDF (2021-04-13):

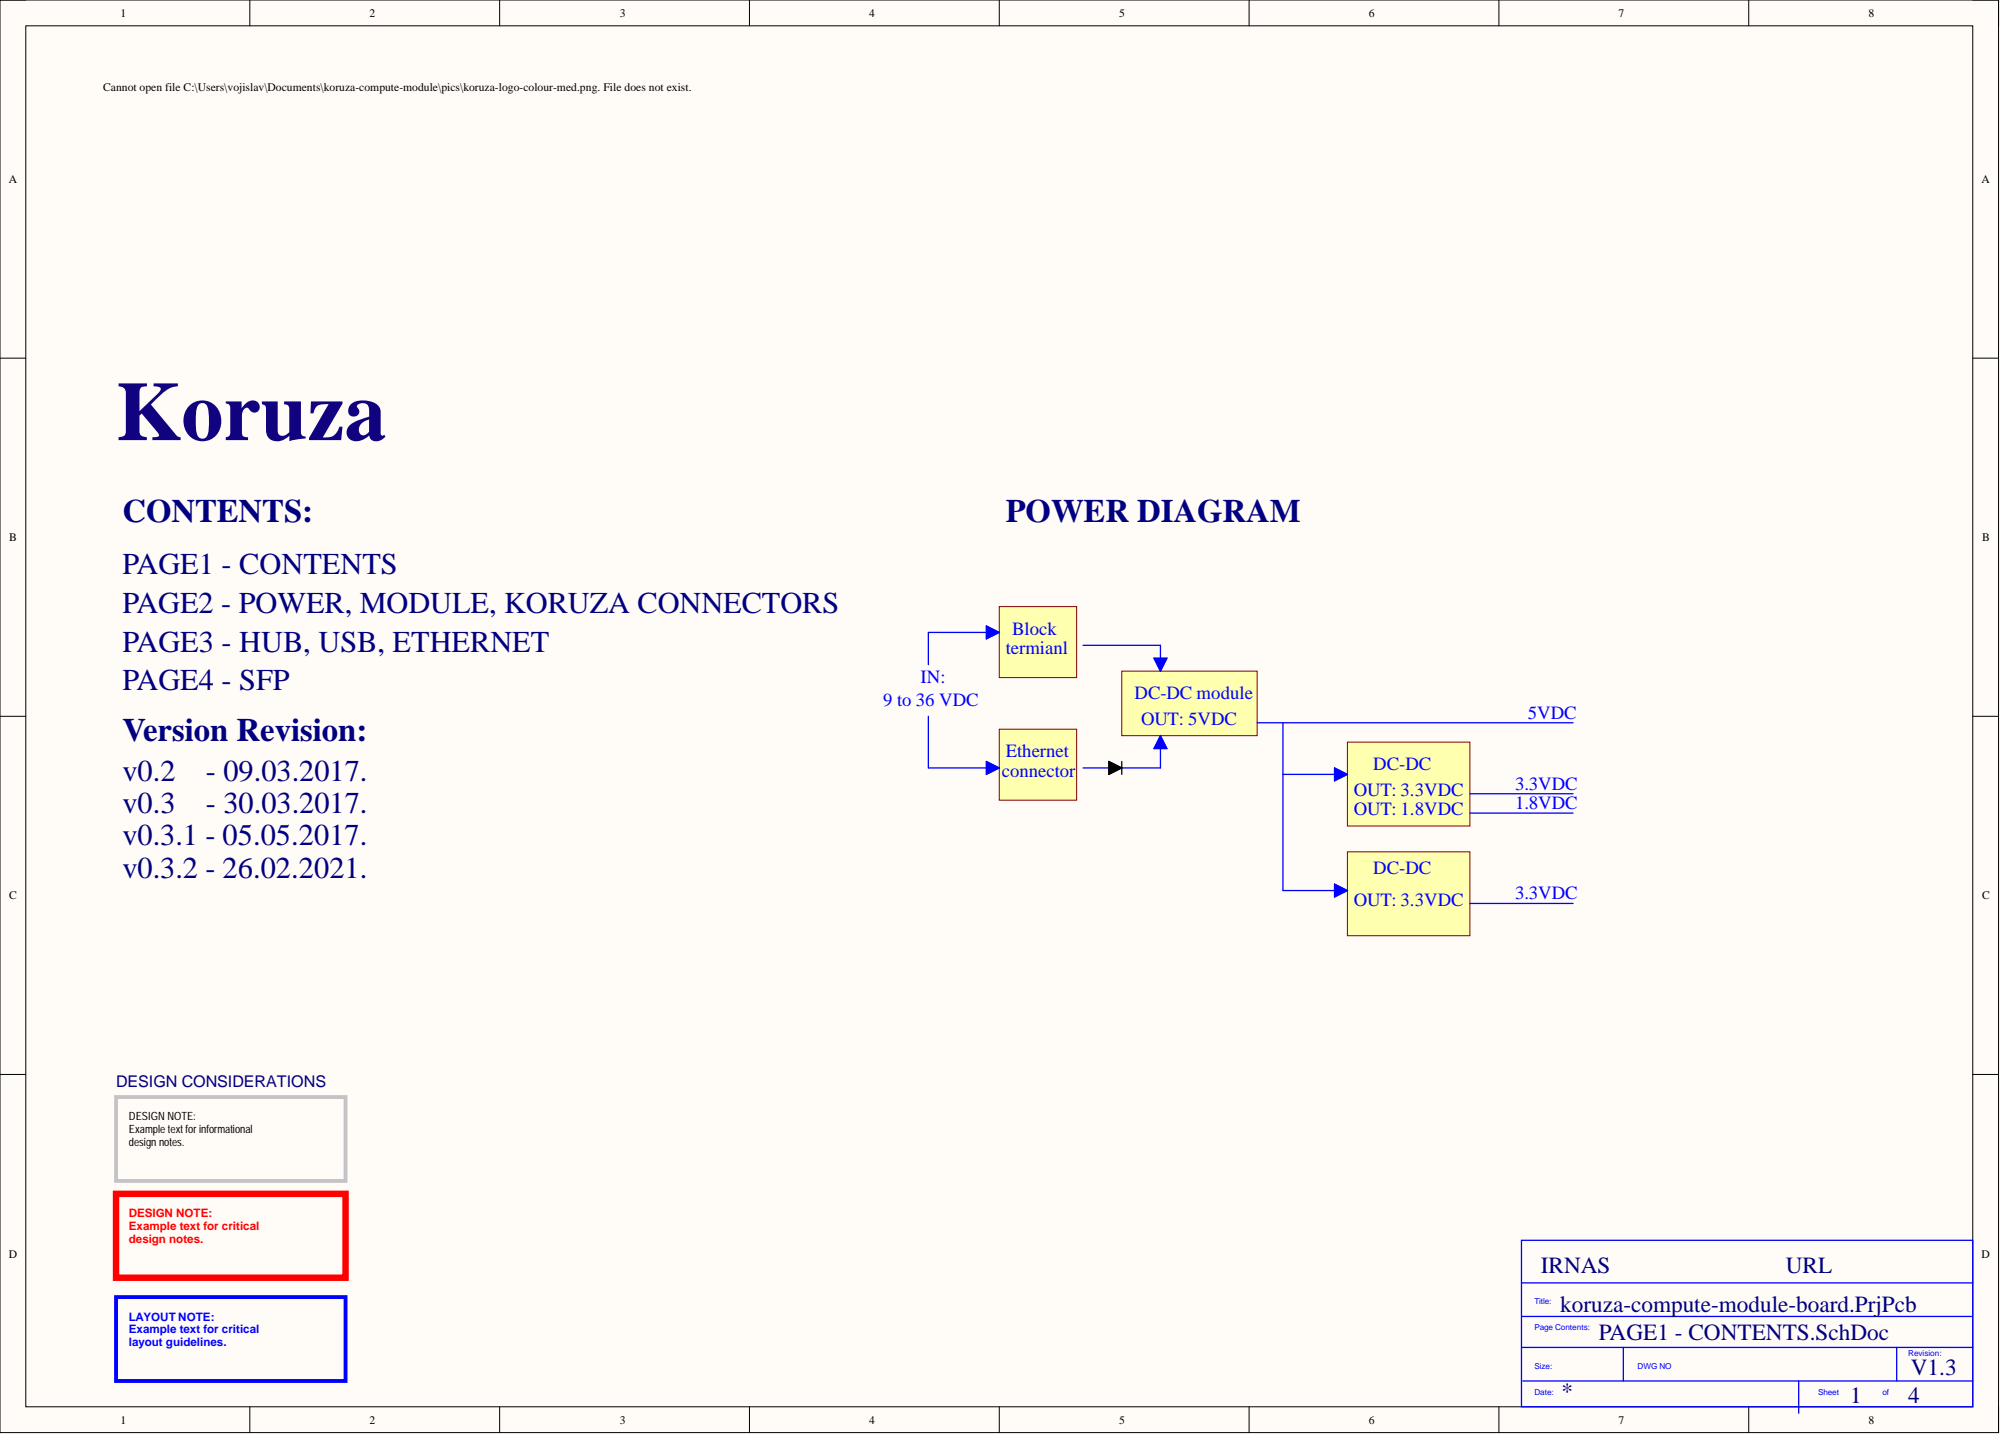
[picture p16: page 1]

Cannot open file C:\Users\vojislav\Documents\koruza-compute-module\pics\koruza-logo-colour-med.png. File does not exist.

DESIGN NOTE:
Example text for informational
design notes.

Example text for critical

koruza-compute-module-board.PrjPcb
PAGE1 - CONTENTS.SchDoc

LAYOUT NOTE:
layout guidelines.

Size: | DWG NO | Revision: V1.3

Date: | Sheet of

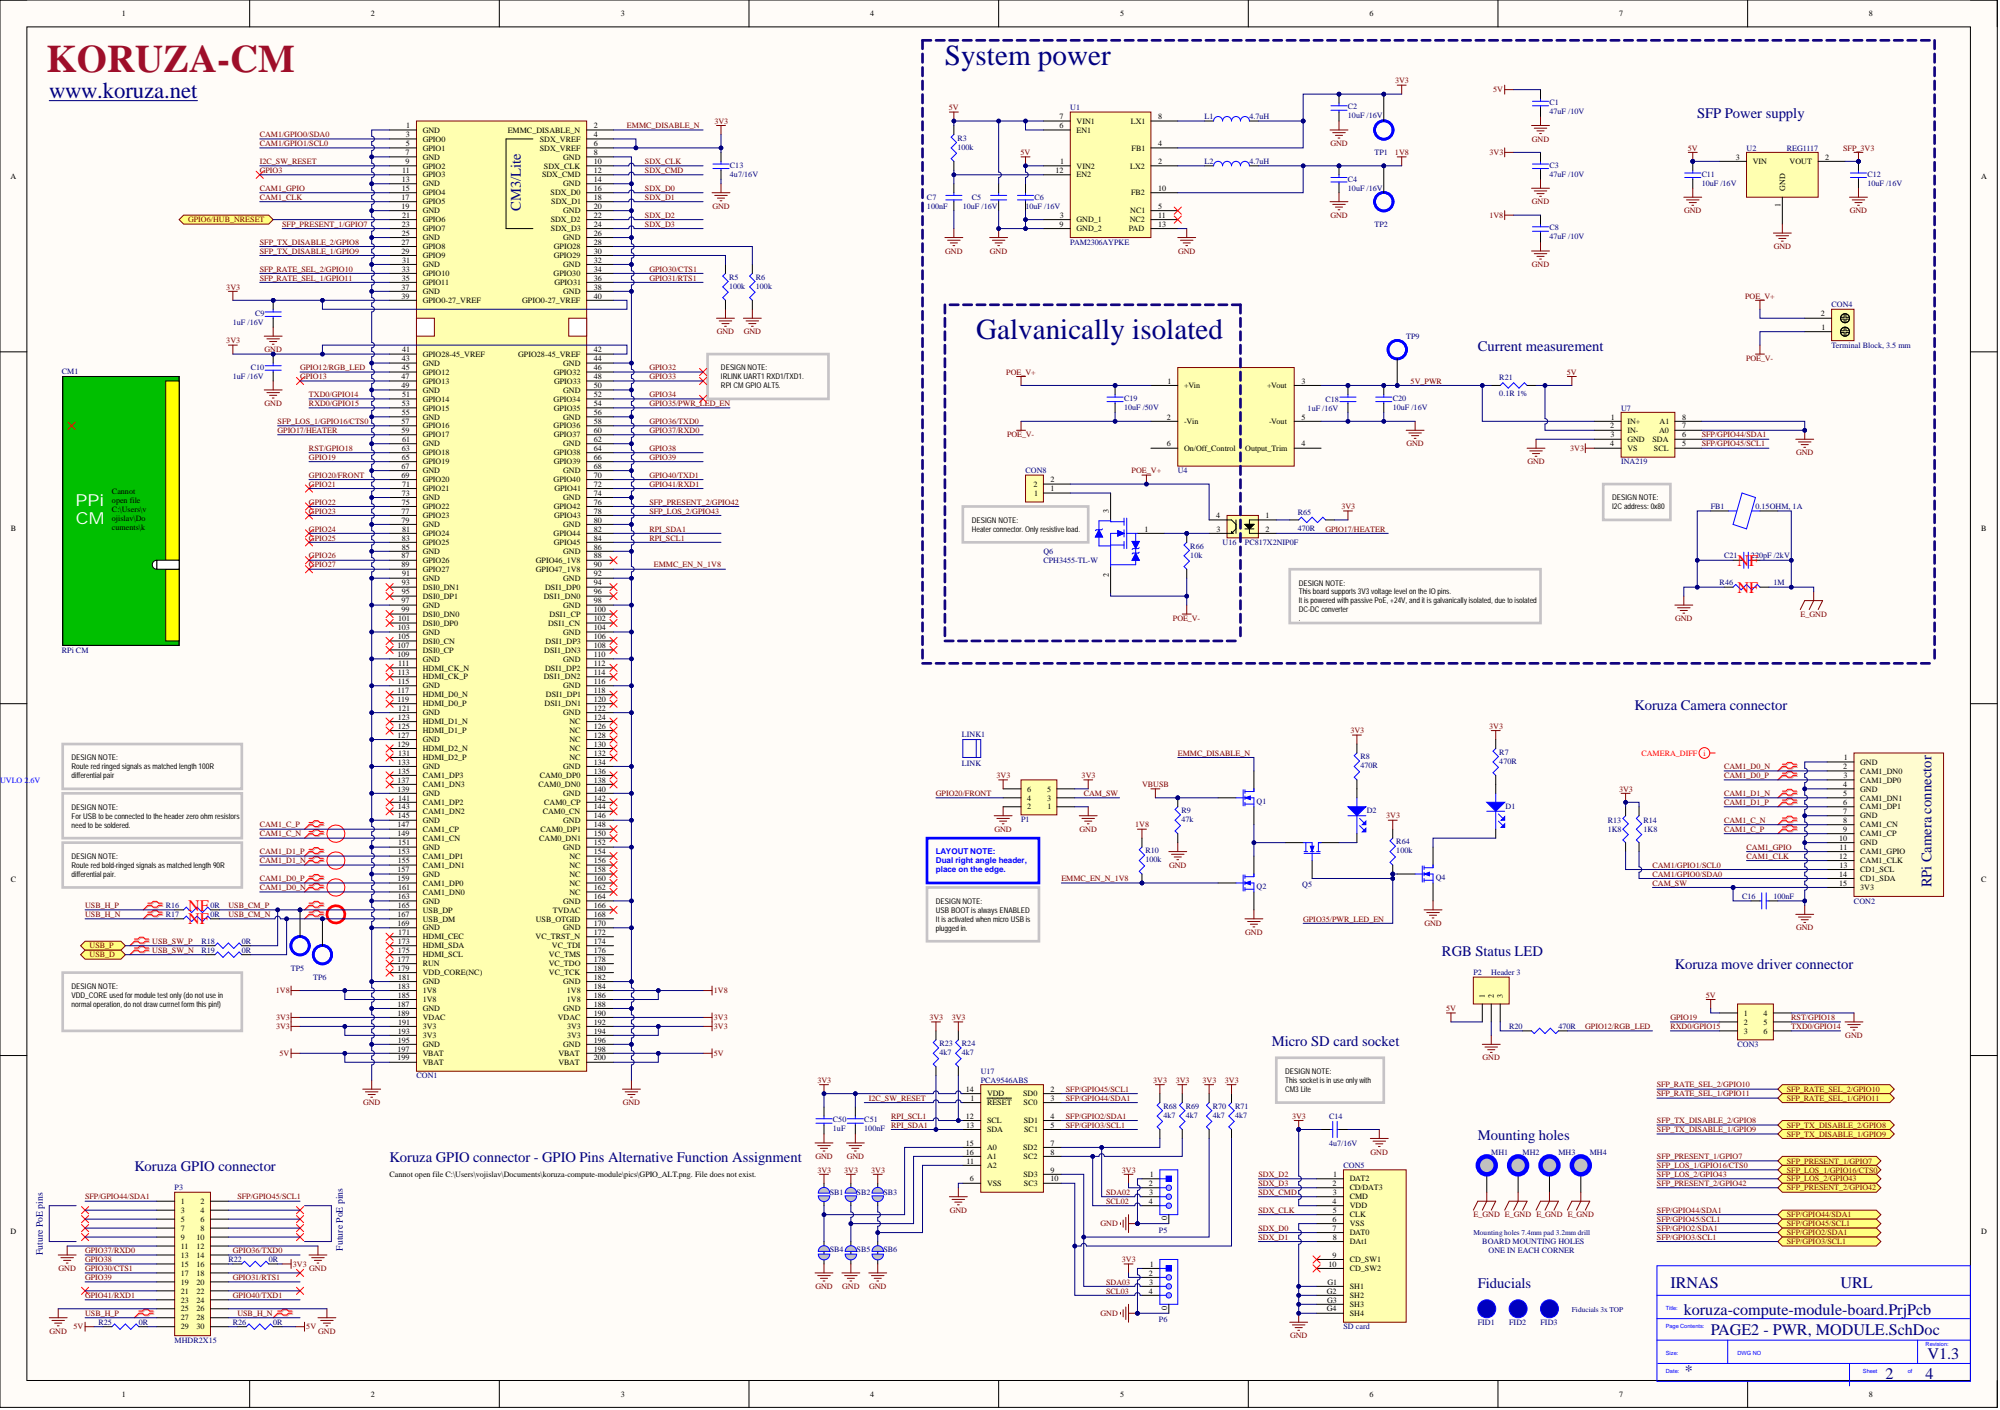
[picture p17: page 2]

2 | GND 3

DESIGN NOTE:
Heater connector. Only resistive load.

This board supports 3V3 voltage level on the IO pins.
It is powered with passive PoE, +24V, and it is galvanically isolated, due to isolated
DC-DC converter .

Route red ringed signals as matched length 100R
differential pair

For USB to be connected to the header zero ohm resistors
need to be soldered.

LAYOUT NOTE:
Dual right angle header
place on the edge.

ringed signals as matched length 90R

USB BOOT is always ENABLED
It is activated when micro USB is
plugged in.

Koruza move driver connector

VDD_CORE used for module test only (do not use in
normal operation, do not draw currnet form this pin!)

Micro SD card socket

This socket is in use only with
CM3 Lite
3V3 GND

GND | | A1 16 | 8

Koruza GPIO connector - GPIO Pins Alternative Function Assignment

Cannot open file C:\Users\vojislav\Documents\koruza-compute-module\pics\GPIO_AL

T.png. File does not exist.

SDA02

BOARD MOUNTING HOLES
ONE IN EACH CORNER

DWG N O

: | Shee t o f

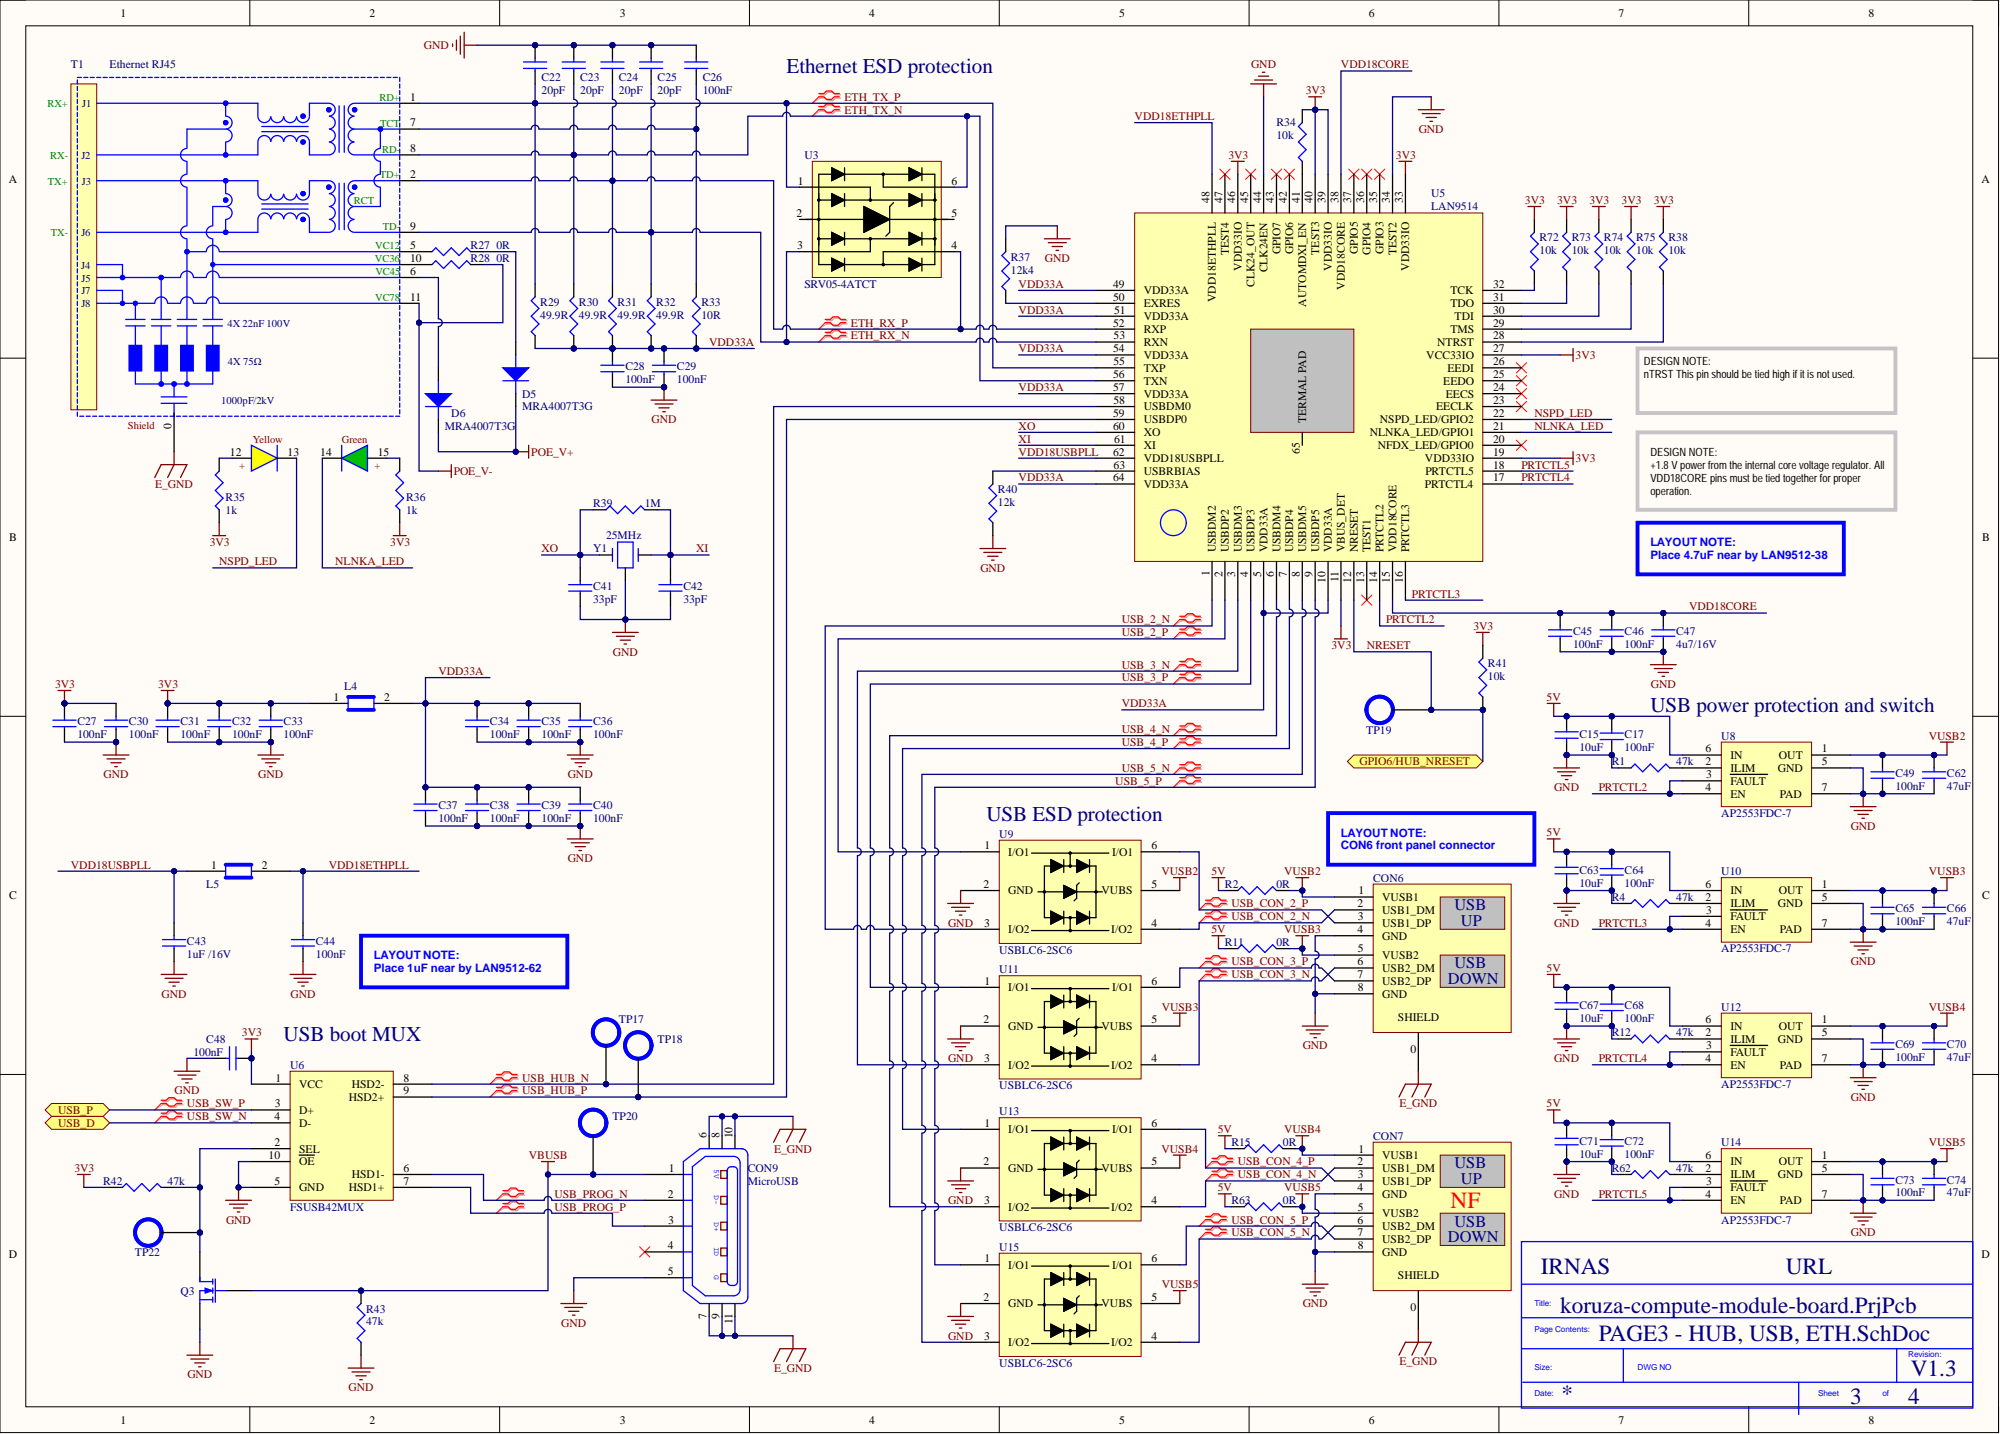
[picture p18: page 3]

DESIGN NOTE:
nTRST This pin should be tied high if it is not used.

+1.8 V power from the internal core voltage regulator. All
VDD18CORE pins must be tied together for proper
operation.

GND
USB power protection and switch

I/O1 | VUSB2

I/O1 VUBS

USB_CON_3_N | 7

9 | USB_HUB_P | | USBLC6-2SC6

DWG N O

: | Shee t o f

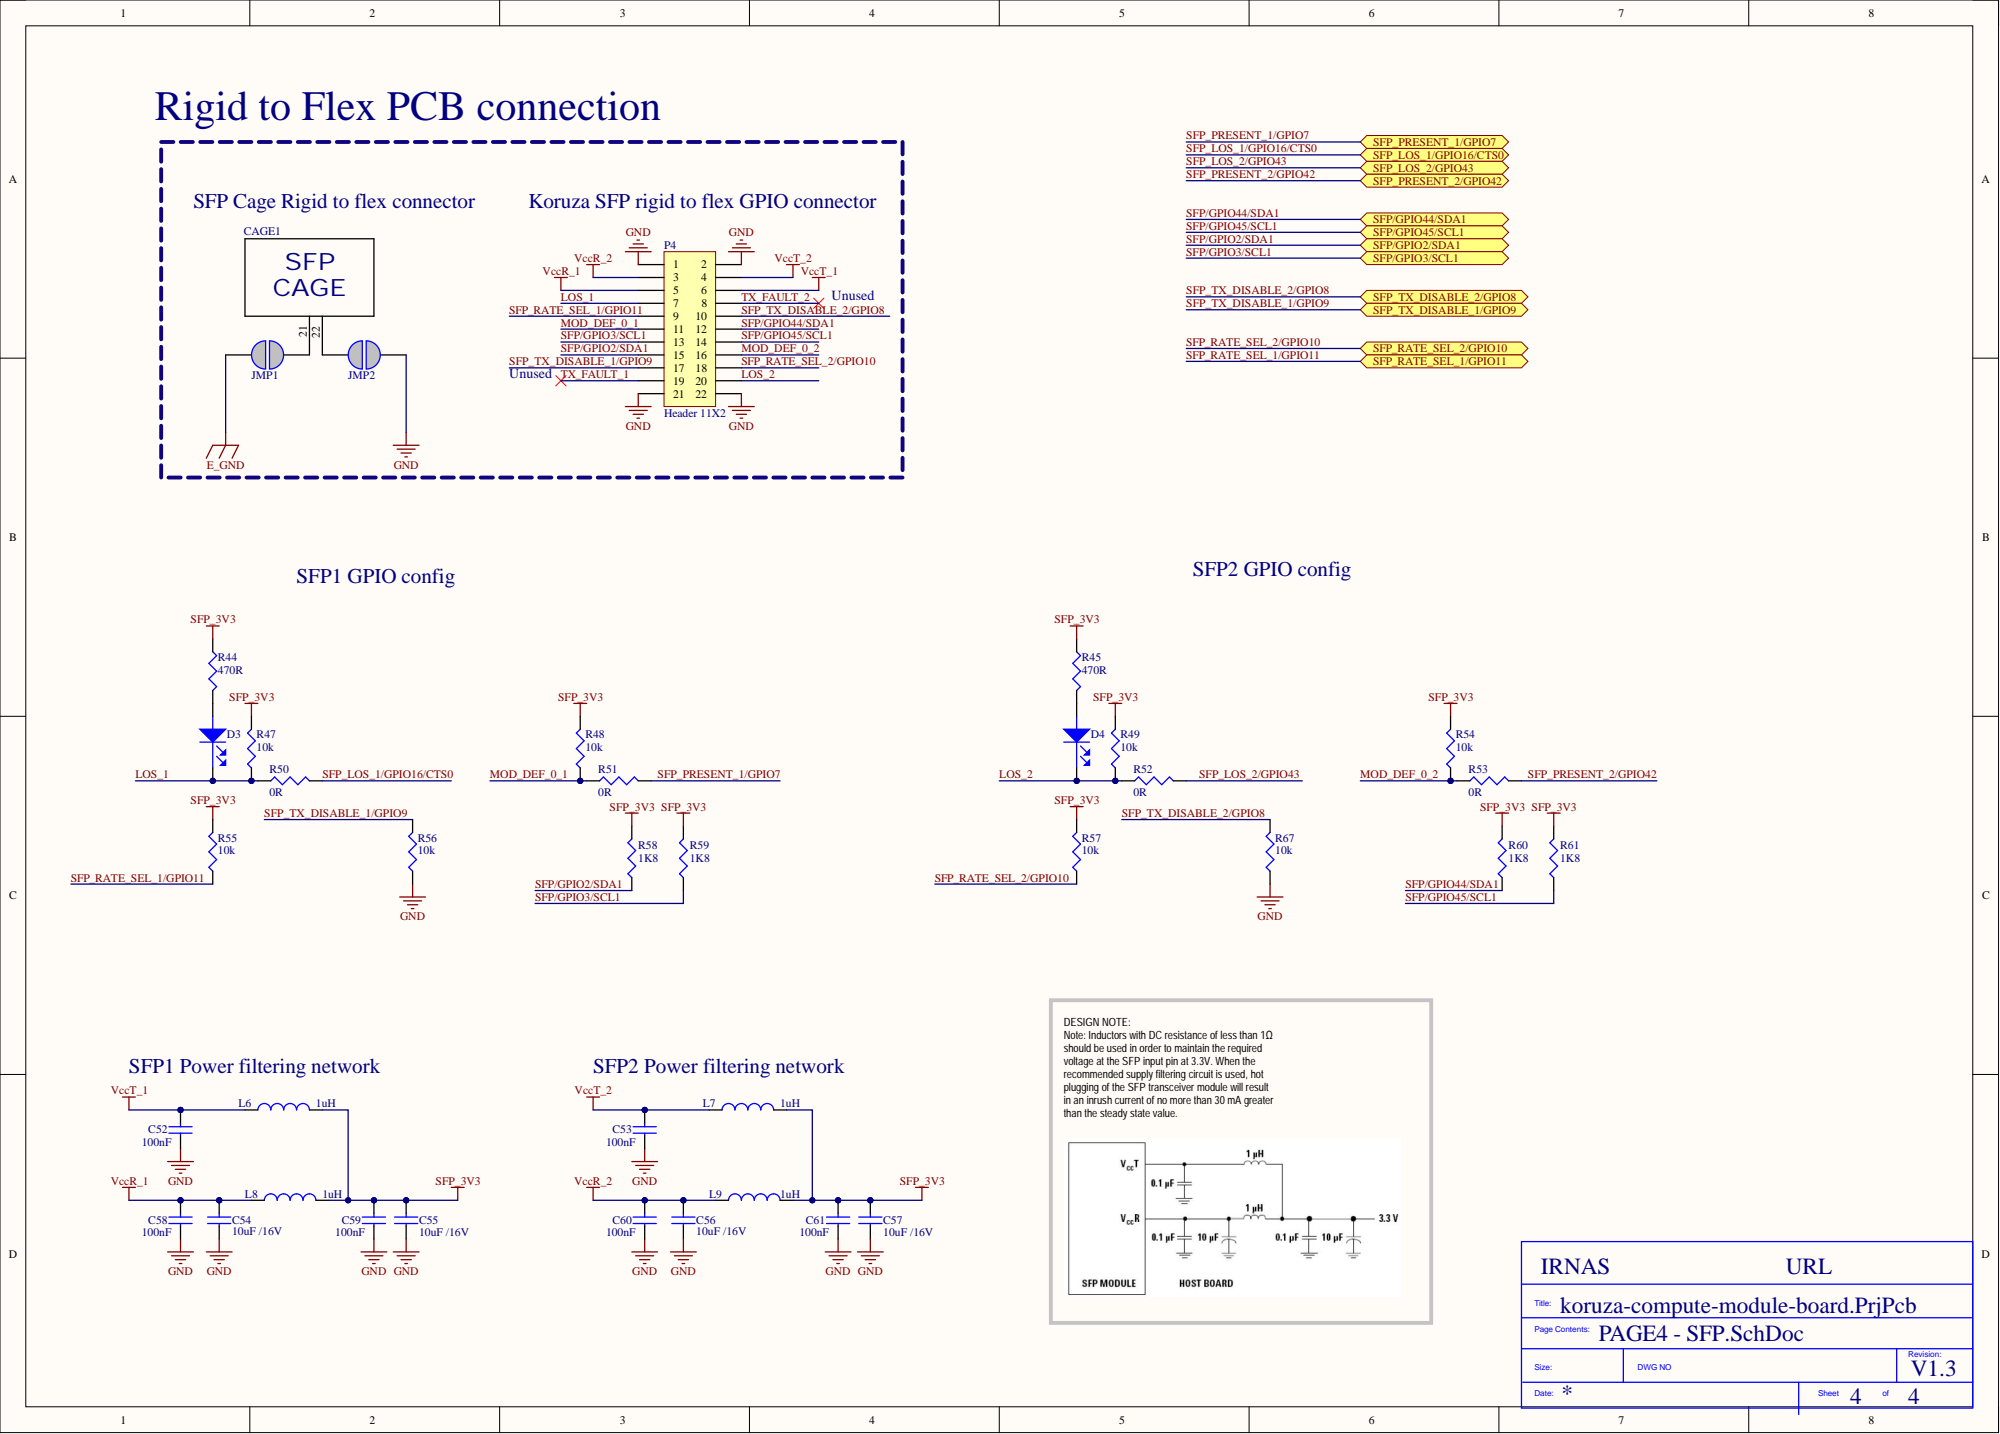
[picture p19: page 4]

Rigid to Flex PCB connection

SFP Cage Rigid to flex connector

Koruza SFP rigid to flex GPIO connector

DESIGN NOTE:
Note: Inductors with DC resistance of less than 1Ω
should be used in order to maintain the required
voltage at the SFP input pin at 3.3V. When the
recommended supply filtering circuit is used, hot
plugging of the SFP transceiver module will result
in an inrush current of no more than 30 mA greater
than the steady state value.

koruza-compute-module-board.PrjPcb
PAGE4 - SFP.SchDoc

Size: | DWG NO

Date: | Sheet of

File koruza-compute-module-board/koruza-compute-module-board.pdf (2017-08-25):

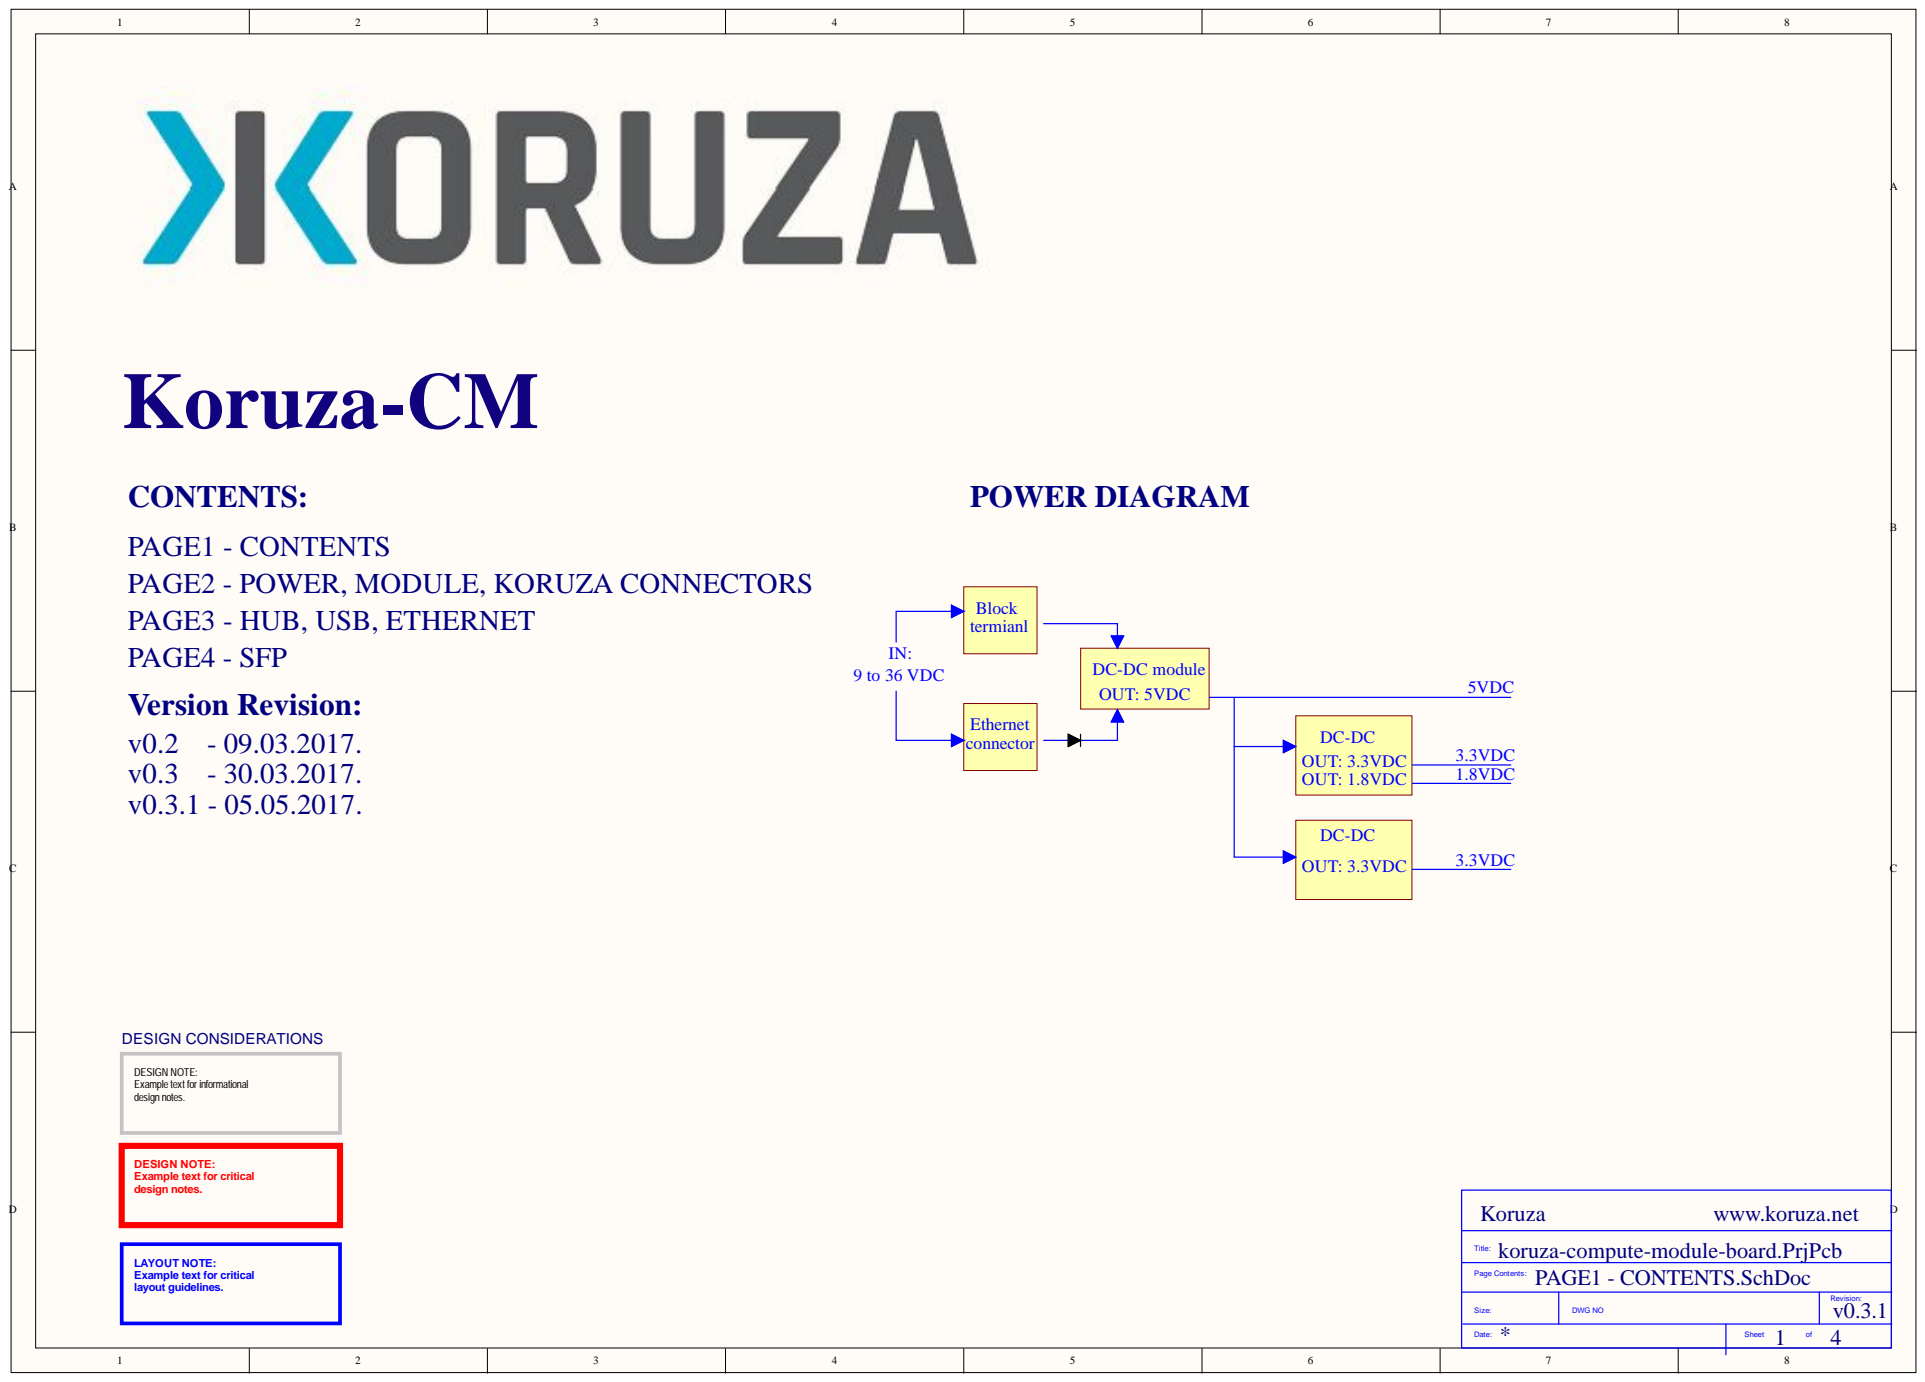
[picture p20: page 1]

DESIGN NOTE:
Example text for informational
design notes.

Example text for critical

koruza-compute-module-board.PrjPcb
PAGE1 - CONTENTS.SchDoc

LAYOUT NOTE:
layout guidelines.

Size: | DWG NO | Revision: v0.3.1

Date: | Sheet of

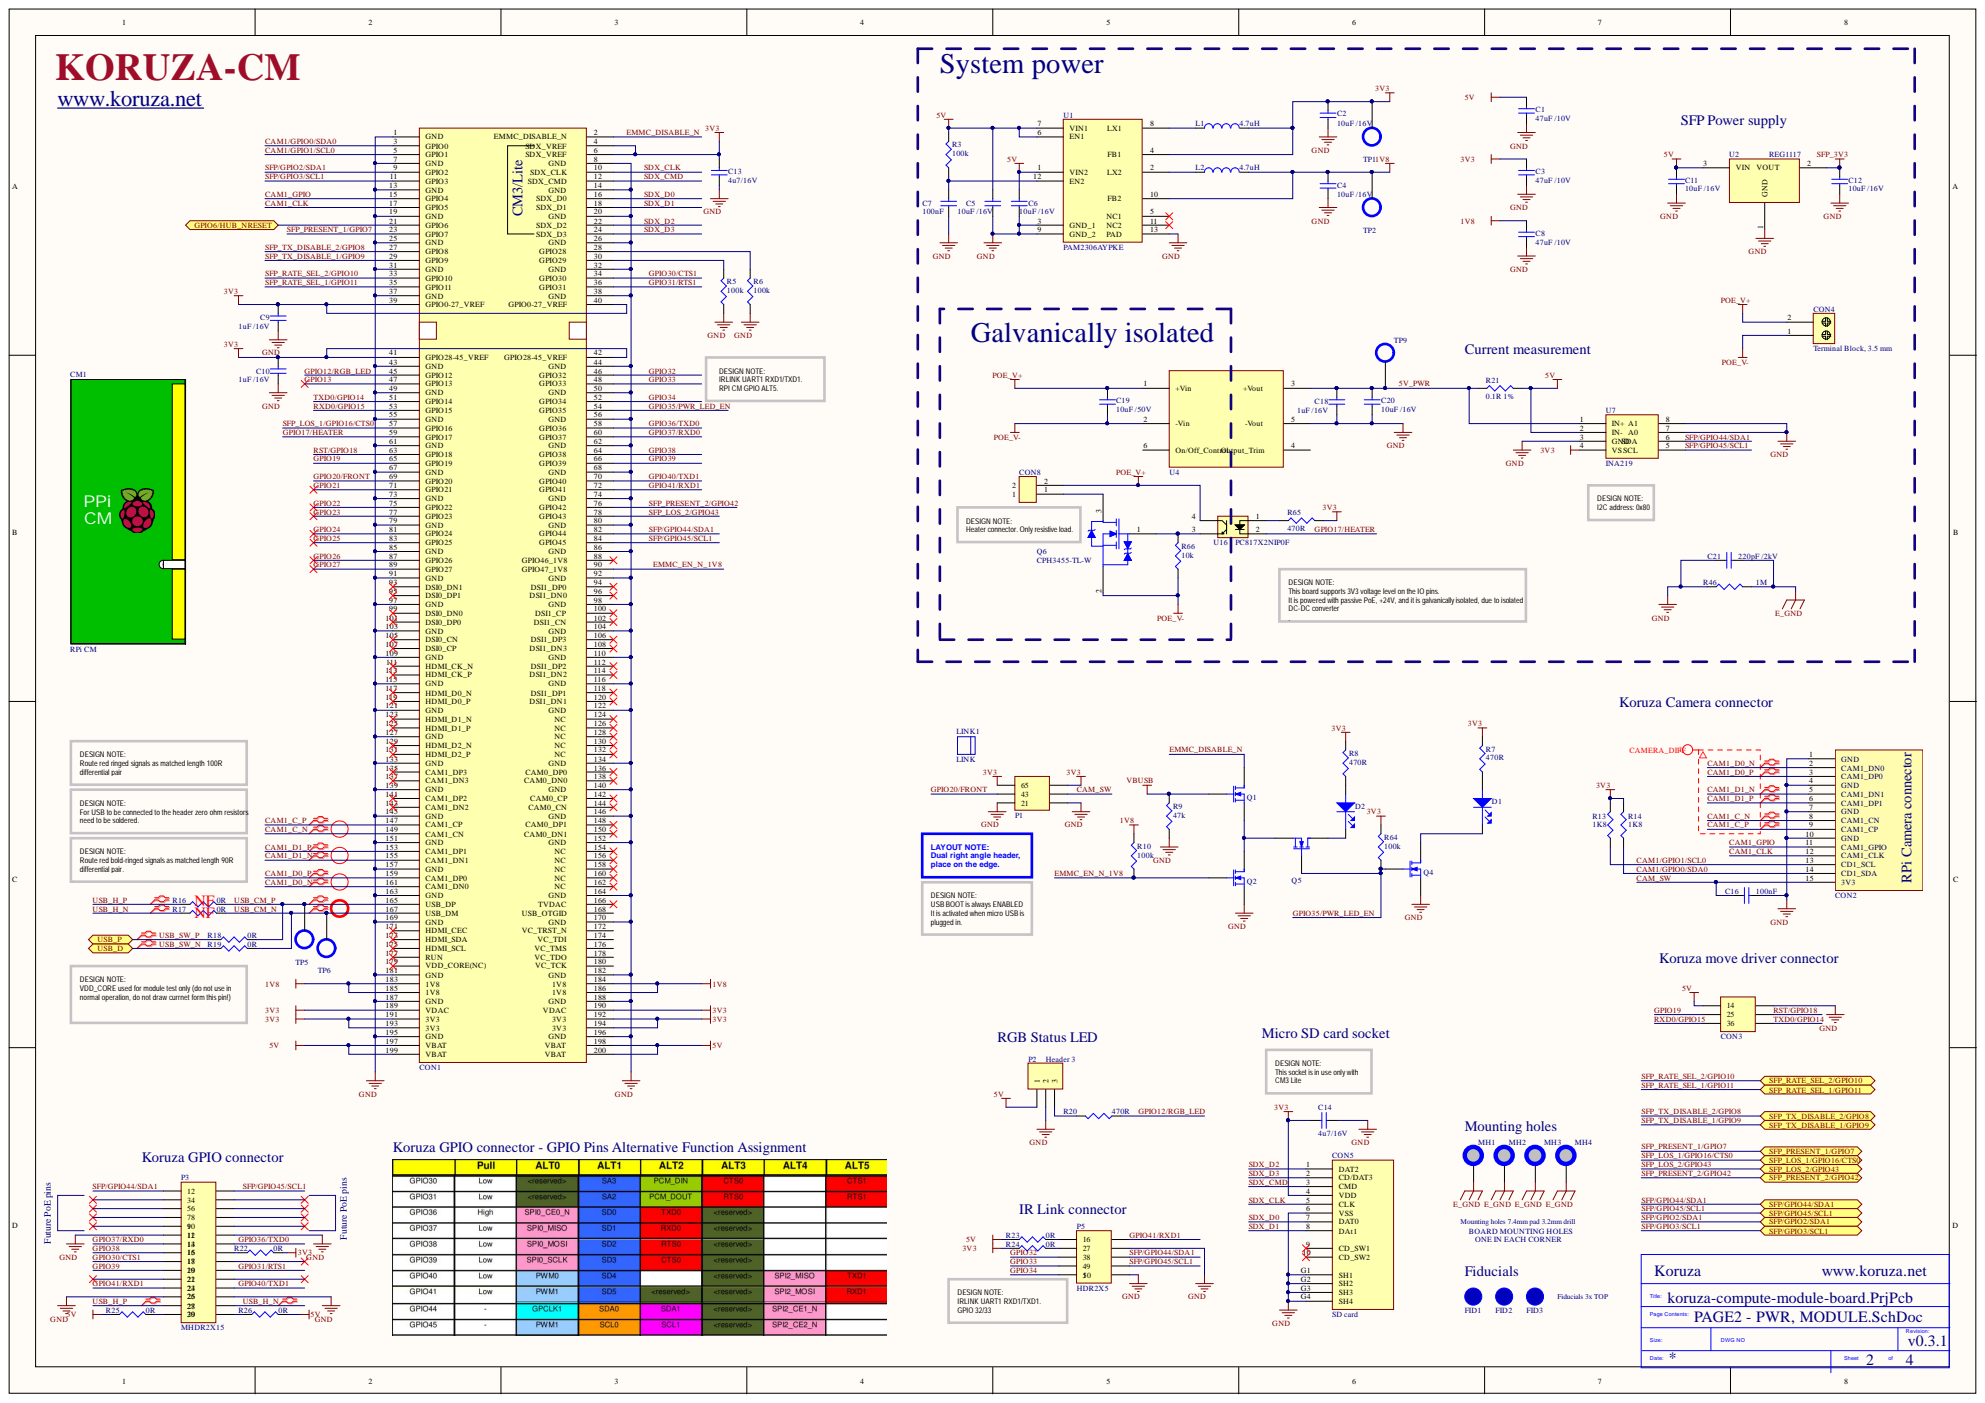
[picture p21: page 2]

KORUZA-CM www.koruza.net

s board supports 3V3 voltage level on the IO pins.
s powered with passi

ve PoE, +24V, and it i

DESIG
Route red ringed signal

For USB to be connected to the header zero ohm resi
need to be soldered. DESIGN NOTE: Route red bold-ringed signal

1 1 | 7 1 | | 1 7 2
7 3 | | 1 7 4

normal operation, do not draw currnet form thi

RE used for module test onl

y (do not use in

1 8 3 | 1 8 4
1 8 5 1 8 7 | 1 8 6 1 8 8

D WG N O | Revision: v0.3. 1

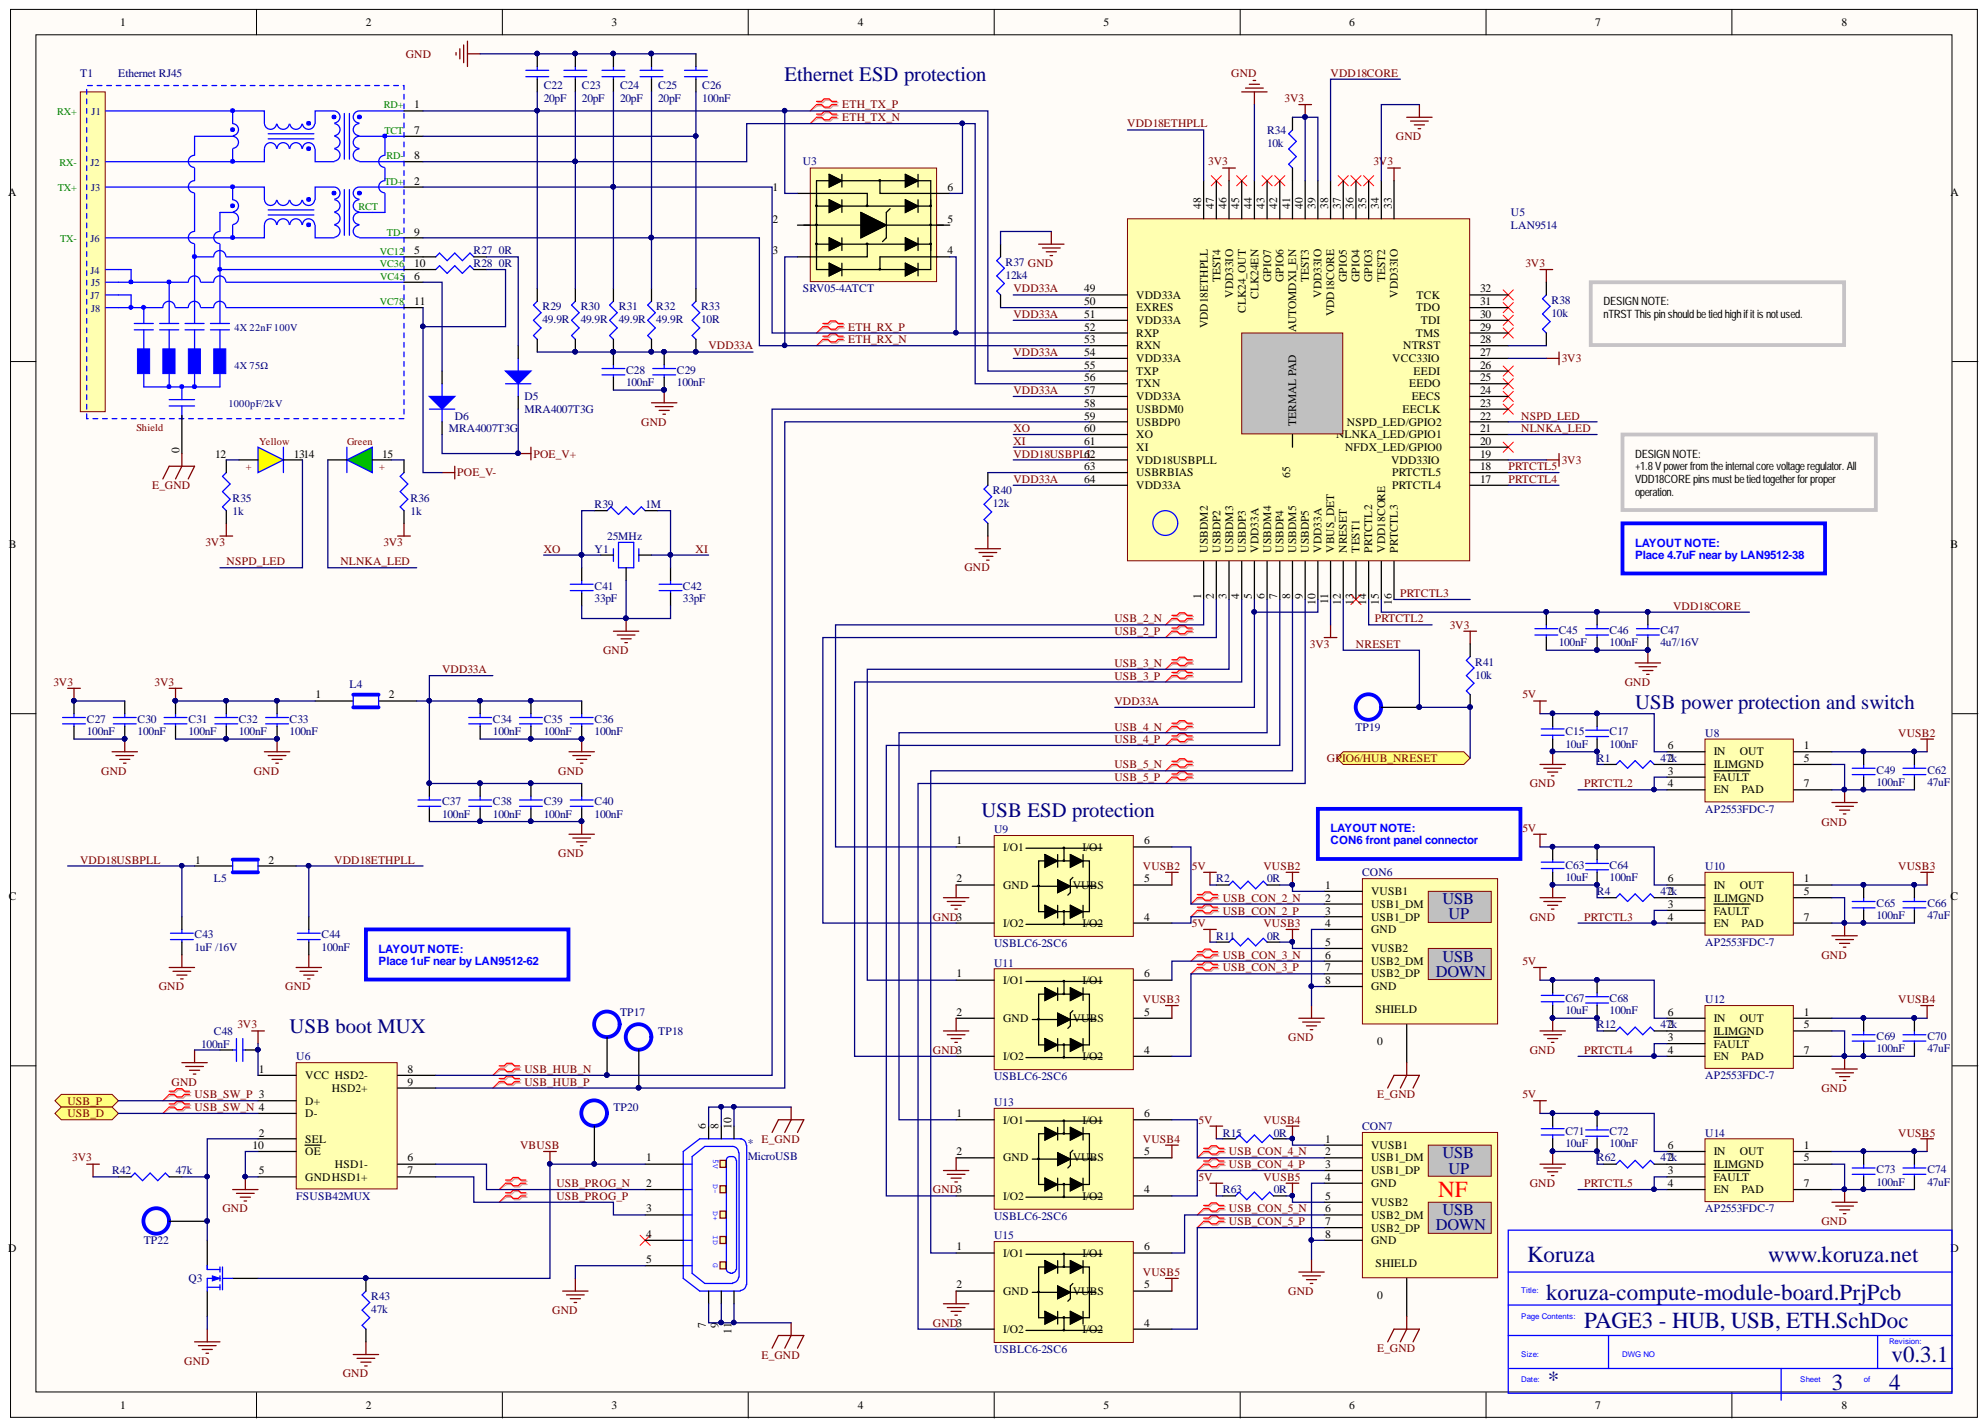
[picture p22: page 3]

EEDO | 25 EEDI 26 VCC33IO 27 NTRST 28 TMS 29 TDI 30 TDO 31 TCK 32 VDD33IO 33

DESIGN NOTE:
nTRST This pin should be tied high if it is not used.

ETH_RX_N | | RXN 53

VDD33A | VDD33A 54 TXP 55

+1.8 V power from the internal core voltage regulator. All
VDD18CORE pins must be tied together for proper
operation.

GND
USB power protection and switch

USB_CON_3_P | USB2_DP 7

GND 2 | VUSB3 | C67

koruza-compute-module-board.PrjPcb
PAGE3 - HUB, USB, ETH.SchDoc

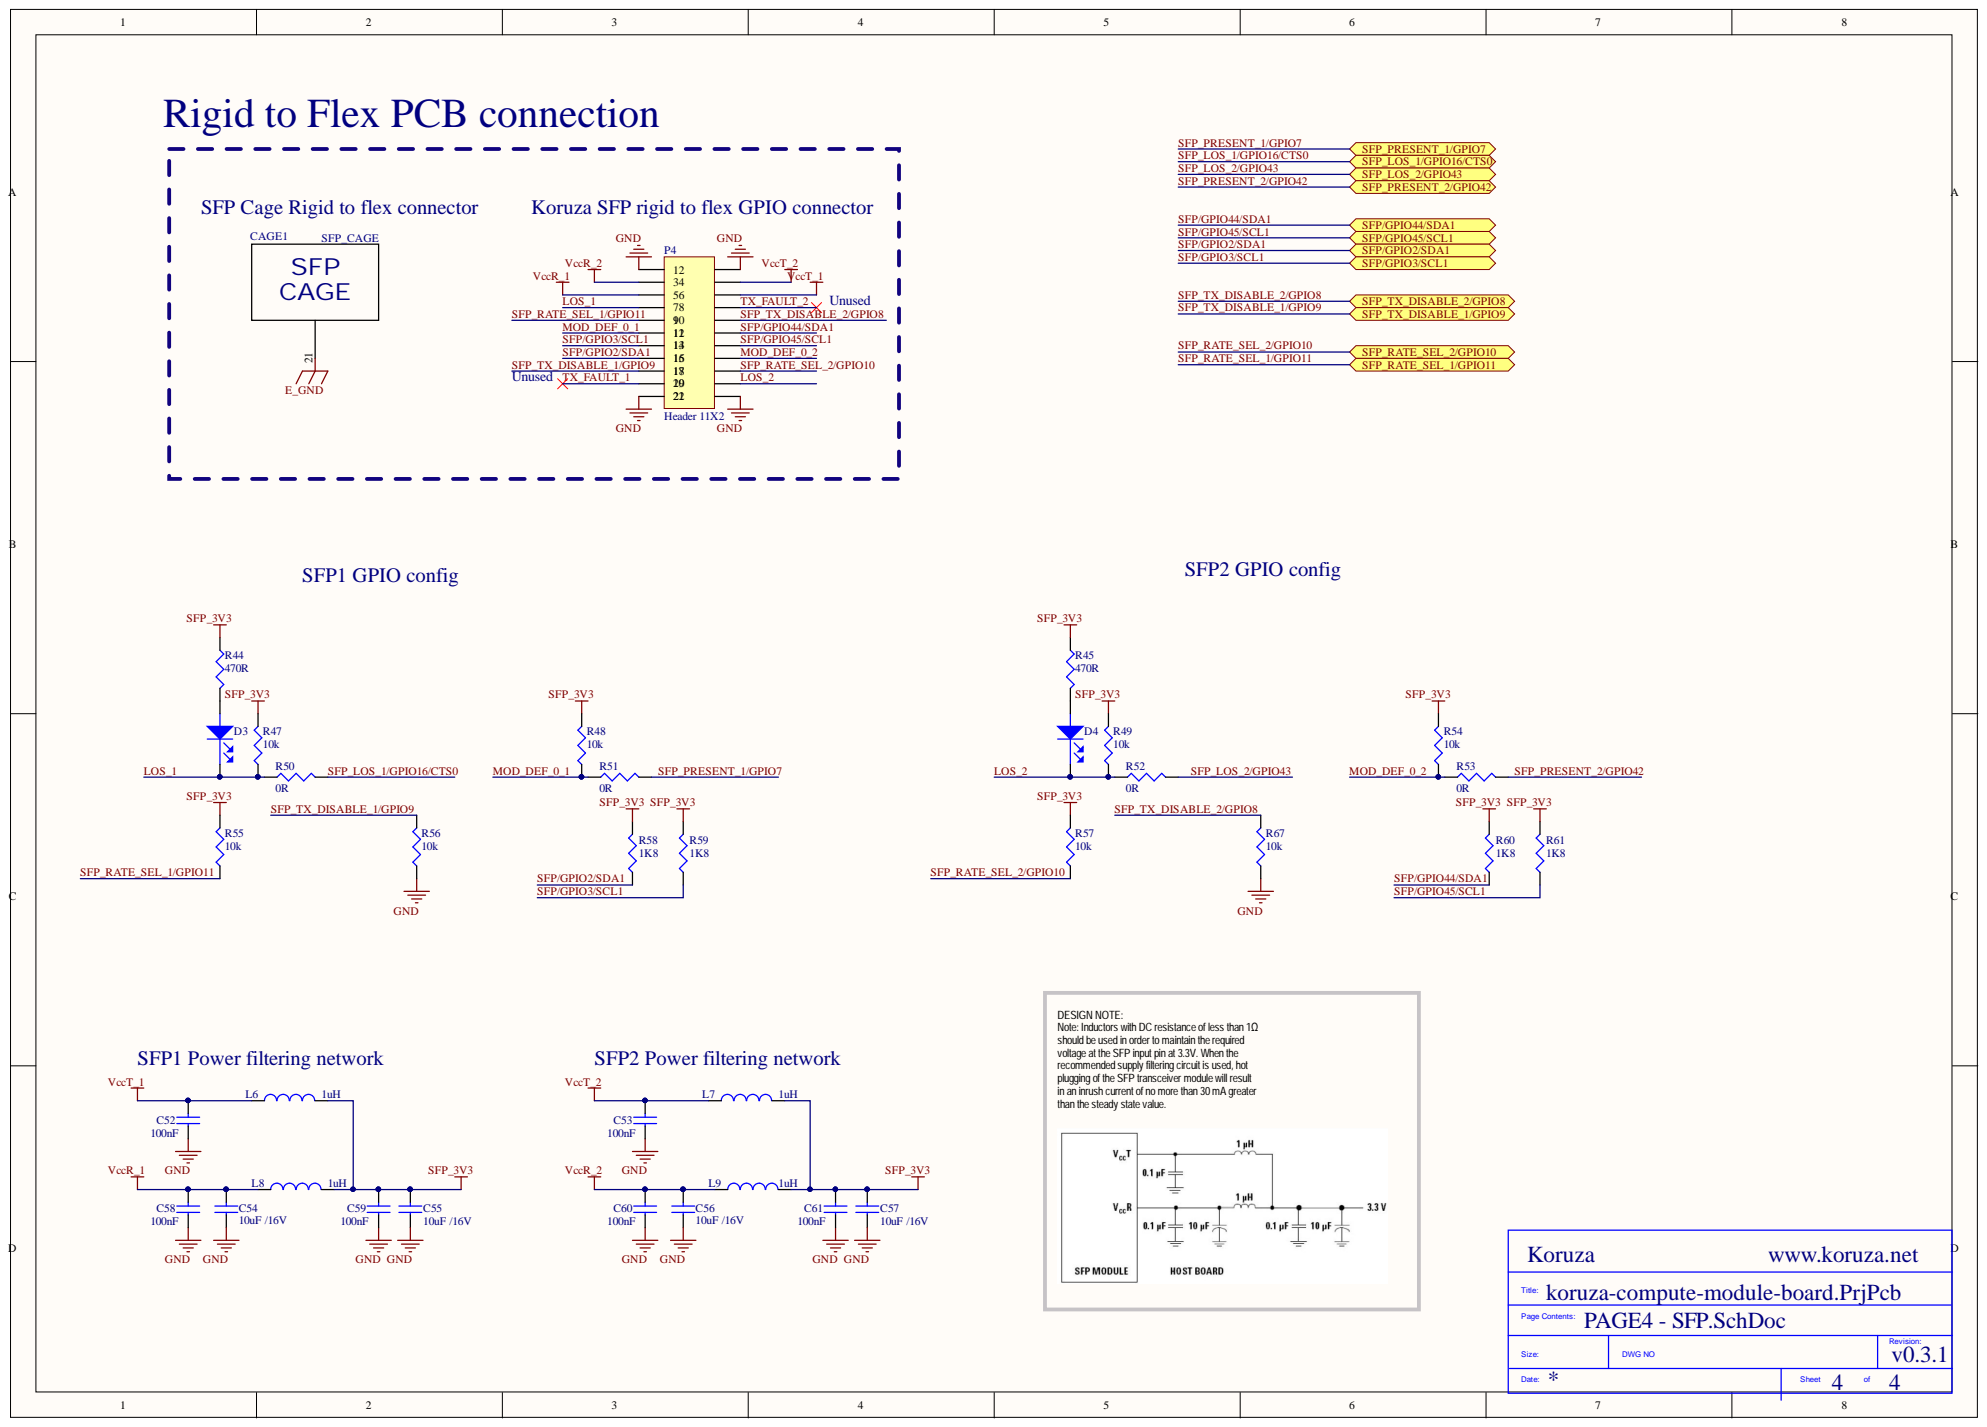
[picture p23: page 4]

Rigid to Flex PCB connection

SFP Cage Rigid to flex connector

Koruza SFP rigid to flex GPIO connector

DESIGN NOTE:
Note: Inductors with DC resistance of less than 1Ω
should be used in order to maintain the required
voltage at the SFP input pin at 3.3V. When the
recommended supply filtering circuit is used, hot
plugging of the SFP transceiver module will result
in an inrush current of no more than 30 mA greater
than the steady state value.

koruza-compute-module-board.PrjPcb
PAGE4 - SFP.SchDoc

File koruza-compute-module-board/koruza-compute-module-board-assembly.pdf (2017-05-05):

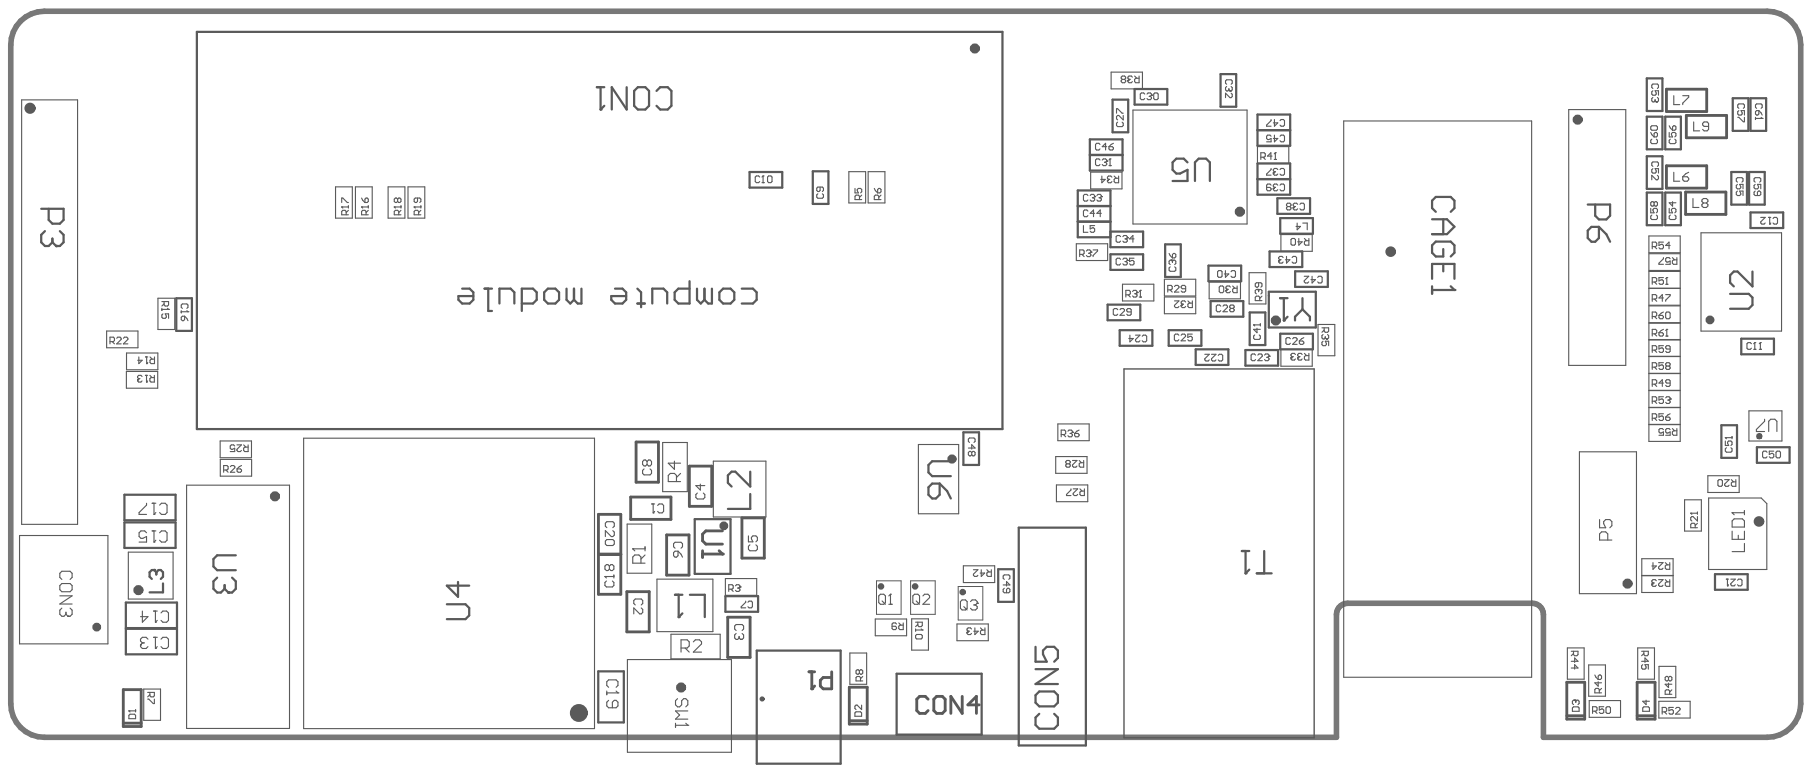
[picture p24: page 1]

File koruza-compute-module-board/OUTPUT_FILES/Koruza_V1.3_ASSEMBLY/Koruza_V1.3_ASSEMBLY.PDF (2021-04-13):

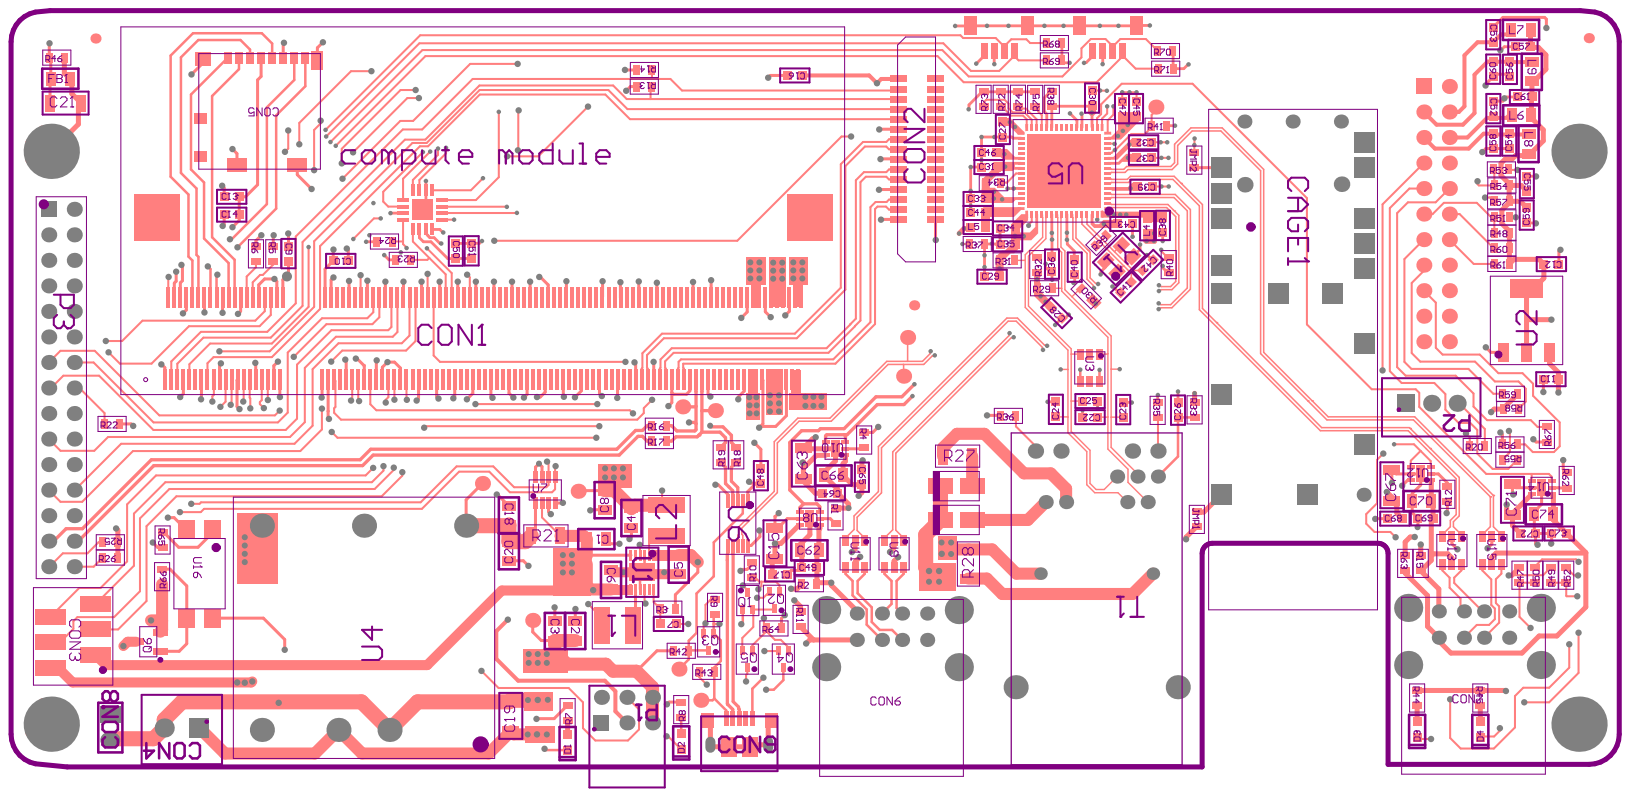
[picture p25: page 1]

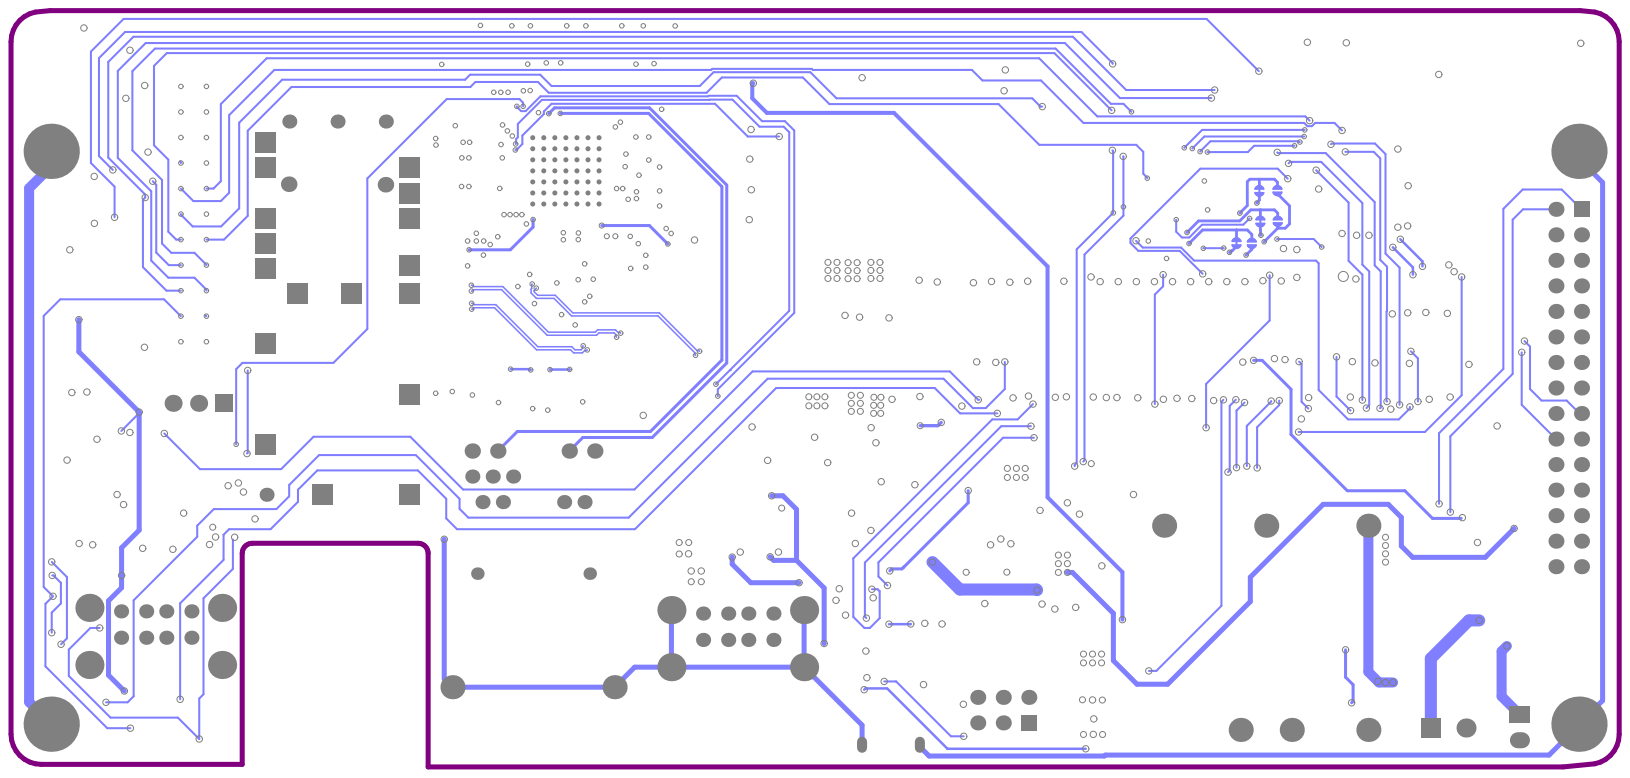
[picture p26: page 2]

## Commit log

2017-01-20 sch update and gitignore add
    [PAGE1 - CONTENTS.SchDoc, PAGE2 - PWR, MODULE.SchDoc, PAGE3 - HUB, USB, ETH.SchDoc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]
2017-01-24 schematics done
    [PAGE1 - CONTENTS.SchDoc, PAGE2 - PWR, MODULE.SchDoc, PAGE3 - HUB, USB, ETH.SchDoc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]
2017-01-24 pdf update
    [PAGE2 - PWR, MODULE.SchDoc]
2017-01-24 schematics update
    [PAGE1 - CONTENTS.SchDoc, PAGE2 - PWR, MODULE.SchDoc, PAGE3 - HUB, USB, ETH.SchDoc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]
2017-01-24 sch and footprint update
    [PAGE1 - CONTENTS.SchDoc, PAGE2 - PWR, MODULE.SchDoc, PAGE3 - HUB, USB, ETH.SchDoc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]
2017-01-25 footprint lib update
    [PAGE2 - PWR, MODULE.SchDoc, PAGE3 - HUB, USB, ETH.SchDoc, PcbLib.PcbLib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]
2017-01-25 all footprint ready for PCB
    [PAGE2 - PWR, MODULE.SchDoc, PAGE3 - HUB, USB, ETH.SchDoc, PCB.PcbDoc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]
2017-01-26 PCB update
    [PAGE2 - PWR, MODULE.SchDoc, PAGE3 - HUB, USB, ETH.SchDoc, PCB.PcbDoc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]
2017-01-26 PCB update 2 to 4 layer
    [PCB.PcbDoc]
2017-01-26 power plane update
    [PCB.PcbDoc]
2017-01-27 impedance matching
    [PAGE3 - HUB, USB, ETH.SchDoc, PCB.PcbDoc]
2017-01-27 DRC check errors solved
    [PCB.PcbDoc]
2017-01-27 PCB overlay update
    [PCB.PcbDoc]
2017-01-30 PCB and sch update
    [PAGE2 - PWR, MODULE.SchDoc, PCB.PcbDoc, PcbLib.PcbLib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]
2017-01-31 sch update I2C see #8
    [PAGE2 - PWR, MODULE.SchDoc, PCB.PcbDoc]
2017-01-31 power layer done
    [PCB.PcbDoc]
2017-01-31 sch check and PCB DRC OK
    [PCB.PcbDoc]
2017-02-01 new hs board 3d model
    [PCB.PcbDoc]
2017-02-03 pcb v0.2 done
    [PCB.PcbDoc, PcbLib.PcbLib, koruza-compute-module-board.PrjPcb]
2017-02-03 gerber files
    [PCB.DRL, PCB.GBL, PCB.GBO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]
2017-02-07 bom update
    [PAGE2 - PWR, MODULE.SchDoc, PAGE3 - HUB, USB, ETH.SchDoc, SCHLib.SchLib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]
2017-03-27 NEW BOARD VERSION 0.3 START, lib update
    [Bill of Materials-koruza-compute-module-board.csv, PAGE2 - PWR, MODULE.SchDoc, PCB.PcbDoc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]
2017-03-28 lib update
    [PcbLib.PcbLib, SCHLib.SchLib]
2017-03-29 lib update FSUSB42MUX Fixes #12
    [PcbLib.PcbLib, SCHLib.SchLib]
2017-03-29 lib update Fixes #14
    [PcbLib.PcbLib, SCHLib.SchLib]
2017-03-29 lib update Fixes #15
    [PcbLib.PcbLib, SCHLib.SchLib]
2017-03-29 lib update Fixes #16
    [PcbLib.PcbLib, SCHLib.SchLib]
2017-03-29 lib update Fixes #17
    [PcbLib.PcbLib, SCHLib.SchLib]
2017-03-29 sch and lib update Fixes #18 #10 #9
    [PAGE2 - PWR, MODULE.SchDoc, PAGE3 - HUB, USB, ETH.SchDoc, PcbLib.PcbLib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]
2017-03-30 sch and lib update Fixes #22, #19, #13
    [PAGE2 - PWR, MODULE.SchDoc, PAGE3 - HUB, USB, ETH.SchDoc, PAGE4 - SFP.SchDoc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]
2017-03-30 shc and lib update Fixes #11
    [PAGE2 - PWR, MODULE.SchDoc, PAGE4 - SFP.SchDoc, PcbLib.PcbLib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]
2017-03-30 sch, lib and PDF update
    [PAGE1 - CONTENTS.SchDoc, PAGE2 - PWR, MODULE.SchDoc, PAGE3 - HUB, USB, ETH.SchDoc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]
2017-03-31 sch v0.3 OK
    [PAGE2 - PWR, MODULE.SchDoc, PAGE3 - HUB, USB, ETH.SchDoc, PAGE4 - SFP.SchDoc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]
2017-03-31 initial placemant PCB
    [PAGE2 - PWR, MODULE.SchDoc, PCB.PcbDoc, PcbLib.PcbLib]
2017-04-05 pcb and pdf update, all components placed, all tracks routed
    [PAGE2 - PWR, MODULE.SchDoc, PAGE4 - SFP.SchDoc]
2017-04-05 pcb update, done routing
    [PAGE2 - PWR, MODULE.SchDoc, PAGE3 - HUB, USB, ETH.SchDoc, PcbLib.PcbLib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]
2017-04-05 pcb and pdf update, Fixes #21
2017-04-05 pcb update, DRC ok
2017-04-06 pcb update, overlay done
    [PAGE2 - PWR, MODULE.SchDoc]
2017-04-06 pcb, pdf, gerber update
    [Bill of Materials-koruza-compute-module-board.csv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]
2017-05-05 pcb and sch update, new revision v0.3.1, Fixes #23
    [PAGE1 - CONTENTS.SchDoc, PAGE3 - HUB, USB, ETH.SchDoc, PCB.CSV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]
2017-05-17 v0.3.1 done
    [Bill of Materials-koruza-compute-module-board.xls, PAGE1 - CONTENTS.SchDoc, PAGE2 - PWR, MODULE.SchDoc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]
2017-08-21 new version first commit
    [1040310811.stp, PAGE2 - PWR, MODULE.SchDoc, PAGE3 - HUB, USB, ETH.SchDoc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]
2017-08-22 sch update
    [DFN2020-6.step, PAGE2 - PWR, MODULE.SchDoc, PAGE3 - HUB, USB, ETH.SchDoc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]
2017-08-25 sch done
    [PAGE1 - CONTENTS.SchDoc, PAGE2 - PWR, MODULE.SchDoc, PAGE3 - HUB, USB, ETH.SchDoc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]
2017-08-28 sch and pcb update
    [PAGE2 - PWR, MODULE.SchDoc, PAGE3 - HUB, USB, ETH.SchDoc, SCHLib.SchLib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]
2017-08-31 gerber upload
    [PCB.DRL, PCB.GBL, PCB.GBO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]
2017-08-31 upload BOM
    [koruza-compute-module-v1_0-BOM.xlsx]
2021-04-13 V1.3 update
    [Koruza_V1.3.DRL, Koruza_V1.3.GBL, Koruza_V1.3.GBO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]
